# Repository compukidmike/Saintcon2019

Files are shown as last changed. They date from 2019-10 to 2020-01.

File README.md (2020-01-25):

# Saintcon 2019 Enigma Badge

## About the Badge
There is a writeup available at https://mkfactor.com/?p=100

There is also a video of my badge talk at Saintcon https://www.youtube.com/watch?v=MAhJ2W_oN14

## Completing the Badge Challenge
Since you probably don't have 26 badges and a Hut 6 "teleprinter" at your house, it will be difficult to complete the challenge. I have created a modified version of the badge firmware that will allow you to complete the challenge at home! You'll need to complete the steps for reprogramming your badge below. Once that's done, grab the Saintcon2019BadgeChallenge.pdf file from this repository. It has all the intercepted messages for you to decode. Be sure to decode them in order! Your badge should say "LEVELED UP" after successfully decoding a message. Good luck! If you get stuck, feel free to reach out on the SaintComms slack, or via twitter @compukidmike or even email compukidmike @ gmail.

## Reprogramming your badge
Note: This will completely erase the memory on your badge. Any progress in the challenge, as well as custom messages will be lost.

You will need the STM32CubeProgrammer software from https://www.st.com/en/development-tools/stm32cubeprog.html to reprogram your badge. It's cross-platform, though I've only tested it on Windows 10. Unfortunately ST requires you to create a login to download software :(

You'll also need the 2 hex files called Saintcon2019.hex and fpga.hex from this repository as well as a micro USB cable and one of the plugboard jumper wires from your badge.

Programming Steps:
1. Turn off the badge.
2. Connect the 2 TEST pins on your badge using the jumper (On the bottom-right side of your badge). If you haven't soldered that connector, you can put the jumper in from the back and hold it.
3. Connect the badge to your computer using a micro USB cable.
4. Turn on the badge. It will boot into DFU (Device Firmware Upgrade) mode.
5. From the STM32CubeProgrammer application, select USB from the drop-down menu at the top-right.
6. If you don't see anything next to "Serial number", click the little refresh button.
7. Click the green "Connect" button in the top-right corner. It should now say "Connected" above that button.
8. Click the Eraser button on the bottom-left corner (right above the question mark) and click OK to erase the badge memory. This is required for the new program to run correctly as there were many changes made to the way the internal EEPROM is organized.
9. Now click the "+" tab next to Device Memory and select "Open file". Choose one of the hex files you downloaded earlier. Now do the same for the other hex file.
10. With one of the hex file tabs selected, click the blue Download button. This will load the file onto your badge. Now do the same for the other hex file tab.
11. Remove the jumper and turn it off and back on. The first time you turn it on, it will go into a testing mode, where all the LEDs are turned on white. This is normal. Simply press each keyboard button until all the lampboard lights are off. It will say "TEST DONE". Turn it off and back on, and you are finished programming your badge. Enjoy!

## Editing Badge Code
The badge code can be found in the Firmware folder. It was written using the STM32CubeIDE. It's cross-platform and works reasonably well. You'll need an ST-Link V2 USB adapter to program and debug your badge. They can be had for ~$10 from Amazon or even less from Aliexpress if you're willing to wait for shipping.
The IDE can be downloaded from ST here: https://www.st.com/en/development-tools/stm32cubeide.html

The FPGA code was written using Icestudio https://icestudio.io/ It's a cross-platform IDE for Lattice ICE40 FPGAs

The FPGA code is in SaintconFPGA.ice

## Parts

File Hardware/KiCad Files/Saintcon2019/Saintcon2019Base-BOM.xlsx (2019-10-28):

Item # | Ref Des | Qty | Manufacturer | Mfg Part # | Description / Value | Package | Type | Your Instructions / Notes
1 | BT1 | 1 | JST Sales America Inc. | S2B-PH-SM4-TB(LF)(SN) | CONN HEADER SMD R/A 2POS 2MM | 2-SMD | SMD
2 | C1, C2, C3, C4, C6, C7, C14, C16, C18, C20, C22 | 11 |  |  | CAPACITOR 0.1uF 0603 | 0603 | SMD
3 | C5, C9, C10, C11, C12 | 5 |  |  | CAPACITOR 4.7uF 0603 | 0603 | SMD
4 | C8, C13, C15, C17, C19, C21 | 6 |  |  | CAPACITOR 1uF 0603 | 0603 | SMD
5 | D1, D2, D3, D4, D5, D6, D7, D8, D9, D10, D11, D12, D13, D14, D15, D16, D17, D18, D19, D20, D21, D22, D23, D24, D25, D26 | 26 | Varies | Varies | 5050 RGB LED | PLCC-6 (5050) | SMD | https://www.aliexpress.com/item/Led-Lamp-SMD-Led-Diode-RGB-LED-4500pcs-smd-5050-super-bright-leds-Free-Shipping-SMT/32690982692.html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
6 | D27 | 1 |  |  | LED RED 0603 | 0603 | SMD
7 | J1 | 1 | DNP | DNP | DNP
8 | J2 | 1 | Amphenol ICC (FCI) | 10132797-027100LF | CONN PLUG 20POS SMD GOLD | 20*0.5mm | SMD
9 | J3, J4 | 2 | DNP | DNP | DNP
10 | J5 | 1 | DNP | DNP | DNP
11 | J6 | 1 | Amphenol ICC (FCI) | 10118192-0002LF | CONN RCPT USB2.0 MICRO B SMD R/A | USB | SMD
12 | R1, R2, R3, R4 | 4 |  |  | RESISTOR 1k 0603 | 0603 | SMD
13 | R5, R13, R14, R15, R16, R17 | 6 |  |  | RESISTOR 10k 0603 | 0603 | SMD
14 | R6, R7, R10, R12 | 4 |  |  | RESISTOR 100k 0603 | 0603 | SMD
15 | R8, R9 | 2 |  |  | RESISTOR 2k 0603 | 0603 | SMD
16 | R11 | 1 |  |  | RESISTOR 20k 0603 | 0603 | SMD
17 | SW1, SW2, SW3, SW4, SW5, SW6, SW7, SW8, SW9, SW10, SW11, SW12, SW13, SW14, SW15, SW16, SW17, SW18, SW19, SW20, SW21, SW22, SW23, SW24, SW25, SW26 | 26 | Varies | Varies | TACH SWITCH SQUARE HEAD 6x6MM | 4-SMD | SMD | https://www.aliexpress.com/item/32726480469.html?transAbTest=ae803_5
18 | SW27 | 1 | C&K | JS102011SAQN | SWITCH SLIDE SPDT 300MA 6V | 3-SMD | SMD
19 | U1 | 1 | STMicroelectronics | STM32L433VCT6 | IC MCU 32BIT 256KB FLASH 100LQFP | 100LQFP | SMD
20 | U2 | 1 | Microchip Technology | MCP73832T-2ACI/OT | IC LI-ION/LI-POLY CTRLR SOT23-5 | SOT-23-5 | SMD
21 | U3 | 1 | Diodes Incorporated | AP2112K-3.3TRG1 | IC REG LINEAR 3.3V 600MA SOT25 | SOT-23-5 | SMD
22 | U4 | 1 | ISSI, Integrated Silicon Solution Inc | IS31FL3736-QFLS4-TR | IC LED DRVR LINEAR 45MA 40QFN | 40-QFN | SMD
23 | X1, X2 | 2 | JST Sales America Inc. | 02R-LEBSS-TB(LF)(SN) | CONN SSL RCPT 2POS 4MM SOLDER | 2-SMD | SMD
24 | X3, X4 | 2 | JST Sales America Inc. | 02P-LEBSS-TF(LF)(SN) | CONN SSL PLUG 2POS 4MM SOLDER | 2-SMD | SMD
25 | Y1 | 1 | ECS Inc. | ECS-2520MV-120-BN-TR | XTAL OSC XO 12.0000MHZ CMOS SMD | 4-SMD | SMD

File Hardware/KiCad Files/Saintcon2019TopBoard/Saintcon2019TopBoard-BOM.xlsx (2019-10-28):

Item # | Ref Des | Qty | Manufacturer | Mfg Part # | Description / Value | Package | Type | Your Instructions / Notes
1 | C1, C2, C3, C4, C5, C6, C7, C8, C10, C15, C16, C17, C18, C19, C20, C21, C22, C23, C24, C25, C26, C27, C28, C29, C30, C31, C32 | 27 |  |  | Capacitor 0603 100nF 25V | 0603 | SMD
2 | C9 | 1 |  |  | Capacitor 0603 10uF 25V | 0603 | SMD
3 | C11, C12, C13, C14 | 4 |  |  | Capacitor 0603 1uF 25V | 0603 | SMD
4 | D1, D2, D3, D4, D5, D6, D7, D8, D9, D10, D11, D12, D13, D14, D15, D16, D17, D18, D19, D20, D21, D22, D23, D24, D25, D26, D27, D28, D29, D30, D31, D32, D33, D34, D35, D36, D37, D38, D39, D40, D41, D42, D43, D44, D45, D46, D47, D48, D49, D50, D51, D52, D53, D54, D55, D56, D57, D58, D59, D60, D61, D62, D63, D64, D65, D66, D67, D68, D69, D70, D71, D72, D73, D74, D75, D76, D77, D78, D79, D80, D81, D82, D83, D84, D85, D86, D87, D88, D89, D90, D91, D92, D93, D94, D95, D96, D97, D98, D99, D100, D101, D102, D103, D104, D105, D106, D107, D108, D109, D110, D111, D112, D113, D114, D115, D116, D117, D118, D119, D120, D121, D122, D123, D124, D125, D126, D127, D128, D129, D130, D131, D132, D133, D134, D135, D136, D137, D138, D139, D140, D141, D142, D143, D144, D145, D146, D147, D148, D149, D150, D151, D152, D153, D154, D155, D156, D157, D158, D159, D160, D161, D162, D163, D164, D165, D166, D167, D168, D169, D170, D171, D172, D173, D174, D175, D176, D177, D178, D179, D180, D181, D182, D183, D184, D185, D186, D187, D188, D189, D190, D191, D192, D193, D194, D195, D196, D197, D198, D199, D200, D201, D202, D203, D204, D205, D206, D207, D208, D209, D210, D211, D212, D213, D214, D215, D216, D217, D218, D219, D220, D221, D222, D223, D224, D225, D226, D227, D228, D229, D230, D231, D232, D233, D234, D235, D236, D237, D238, D239, D240, D241, D242, D243, D244, D245, D246, D247, D248, D249, D250, D251, D252, D253, D254, D255, D256, D257, D258, D259, D260, D261, D262, D263, D264, D265, D266, D267, D268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 | 1024 | Lite-On | LSTN-B28JEGBB | RGB LED 0404(1010) | 1010 | SMD | https://www.aliexpress.com/item/32374160642.html?transAbTest=ae803_5
5 | D1025 | 1 | STMicroelectronics | BAS70JFILM | DIODE SCHOTTKY 70V 70MA SOD323 | SOD323 | SMD
6 | J1 | 1 | Amphenol ICC (FCI) | 10132798-022100LF | Board to Board & Mezzanine Connectors 2.7mm Height,Dbl Rw 20P,Recept,Connector | 20*0.5mm | SMD
7 | R1, R2, R3 | 3 |  |  | Resistor 0603 10k | 0603 | SMD
8 | R4 | 1 |  |  | Resistor 0603 100 | 0603 | SMD
9 | R9, R10, R11, R12, R13, R14, R15, R16, R17, R18, R19, R20, R21, R22, R23, R24, R25, R26, R27, R28, R29, R30, R31, R32, R33, R34, R35, R36 | 28 |  |  | Resistor 0603 1k | 0603 | SMD
10 | U1 | 1 | Lattice | iCE40HX1K-TQ144 | FPGA - Field Programmable Gate Array iCE40HX 1280 LUTs 1.2V Ultra Low-Power | TQFP144 | SMD
11 | U2 | 1 | Diodes Incorporated | AP2112K-3.3TRG1 | IC REG LINEAR 3.3V 600MA SOT25 | SOT-23-5 | SMD
12 | U3 | 1 | Microchip | MIC5504-1.2YM5-TR | IC REG LINEAR 1.2V 300MA SOT23-5 | SOT-23-5 | SMD
13 | U5, U6, U7, U8, U9, U10, U11, U12, U13, U14, U15, U16 | 12 | Macroblock | MBI5124GP-A | IC LED DRVR 24QSOP | 24-QSOP | SMD
14 | U17, U18, U19, U20, U21, U22, U23, U24 | 8 | Micro Commercial Co | SIL2301-TP | P-CHANNEL,MOSFETS,SOT23-6L PACKA | SOT-23-6 | SMD

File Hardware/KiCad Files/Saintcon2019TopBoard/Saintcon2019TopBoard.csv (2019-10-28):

Source: | C:\Users\compukidmike\Dropbox\kicad\Saintcon2019TopBoard\Saintcon2019TopBoard.sch
Date: | 6/2/2019 3:04:15 PM
Tool: | Eeschema (5.1.2)-1
Generator: | C:\Program Files\KiCad\bin\scripting\plugins/bom_csv_grouped_by_value.py
Component Count: | 1119
Individual Components:
Item | Qty | Reference(s) | Value | LibPart | Footprint | Datasheet | Field4 | Field5 | Field6 | Field7 | Field8
 |  | C1 | 0.1uF | Device:C_Small | Capacitors_SMD:C_0603 | ~
 |  | C2 | 0.1uF | Device:C_Small | Capacitors_SMD:C_0603 | ~
 |  | C3 | 0.1uF | Device:C_Small | Capacitors_SMD:C_0603 | ~
 |  | C4 | 0.1uF | Device:C_Small | Capacitors_SMD:C_0603 | ~
 |  | C5 | 0.1uF | Device:C_Small | Capacitors_SMD:C_0603 | ~
 |  | C6 | 0.1uF | Device:C_Small | Capacitors_SMD:C_0603 | ~
 |  | C7 | 0.1uF | Device:C_Small | Capacitors_SMD:C_0603 | ~
 |  | C8 | 0.1uF | Device:C_Small | Capacitors_SMD:C_0603 | ~
 |  | C9 | 10uF | Device:C_Small | Capacitors_SMD:C_0603 | ~
 |  | C10 | 0.1uF | Device:C_Small | Capacitors_SMD:C_0603 | ~
 |  | C11 | 1uF | Device:C_Small | Capacitors_SMD:C_0603 | ~
 |  | C12 | 1uF | Device:C_Small | Capacitors_SMD:C_0603 | ~
 |  | C13 | 1uF | Device:C_Small | Capacitors_SMD:C_0603 | ~
 |  | C14 | 1uF | Device:C_Small | Capacitors_SMD:C_0603 | ~
 |  | C15 | 0.1uF | Device:C_Small | Capacitors_SMD:C_0603 | ~
 |  | C16 | 0.1uF | Device:C_Small | Capacitors_SMD:C_0603 | ~
 |  | C17 | 0.1uF | Device:C_Small | Capacitors_SMD:C_0603 | ~
 |  | C18 | 0.1uF | Device:C_Small | Capacitors_SMD:C_0603 | ~
 |  | C19 | 0.1uF | Device:C_Small | Capacitors_SMD:C_0603 | ~
 |  | C20 | 0.1uF | Device:C_Small | Capacitors_SMD:C_0603 | ~
 |  | C21 | 0.1uF | Device:C_Small | Capacitors_SMD:C_0603 | ~
 |  | C22 | 0.1uF | Device:C_Small | Capacitors_SMD:C_0603 | ~
 |  | C23 | 0.1uF | Device:C_Small | Capacitors_SMD:C_0603 | ~
 |  | C24 | 0.1uF | Device:C_Small | Capacitors_SMD:C_0603 | ~
 |  | C25 | 0.1uF | Device:C_Small | Capacitors_SMD:C_0603 | ~
 |  | C26 | 0.1uF | Device:C_Small | Capacitors_SMD:C_0603 | ~
 |  | C27 | 0.1uF | Device:C_Small | Capacitors_SMD:C_0603 | ~
 |  | C28 | 0.1uF | Device:C_Small | Capacitors_SMD:C_0603 | ~
 |  | C29 | 0.1uF | Device:C_Small | Capacitors_SMD:C_0603 | ~
 |  | C30 | 0.1uF | Device:C_Small | Capacitors_SMD:C_0603 | ~
 |  | C31 | 0.1uF | Device:C_Small | Capacitors_SMD:C_0603 | ~
 |  | C32 | 0.1uF | Device:C_Small | Capacitors_SMD:C_0603 | ~
 |  | D1 | LED_ARGB | Device:LED_ARGB | RGB_LED_0402_1mm:LTSN-B28JEGBB | ~
 |  | D2 | LED_ARGB | Device:LED_ARGB | RGB_LED_0402_1mm:LTSN-B28JEGBB | ~
 |  | D3 | LED_ARGB | Device:LED_ARGB | RGB_LED_0402_1mm:LTSN-B28JEGBB | ~
 |  | D4 | LED_ARGB | Device:LED_ARGB | RGB_LED_0402_1mm:LTSN-B28JEGBB | ~
 |  | D5 | LED_ARGB | Device:LED_ARGB | RGB_LED_0402_1mm:LTSN-B28JEGBB | ~
 |  | D6 | LED_ARGB | Device:LED_ARGB | RGB_LED_0402_1mm:LTSN-B28JEGBB | ~
 |  | D7 | LED_ARGB | Device:LED_ARGB | RGB_LED_0402_1mm:LTSN-B28JEGBB | ~
 |  | D8 | LED_ARGB | Device:LED_ARGB | RGB_LED_0402_1mm:LTSN-B28JEGBB | ~
 |  | D9 | LED_ARGB | Device:LED_ARGB | RGB_LED_0402_1mm:LTSN-B28JEGBB | ~
 |  | D10 | LED_ARGB | Device:LED_ARGB | RGB_LED_0402_1mm:LTSN-B28JEGBB | ~
 |  | D11 | LED_ARGB | Device:LED_ARGB | RGB_LED_0402_1mm:LTSN-B28JEGBB | ~
 |  | D12 | LED_ARGB | Device:LED_ARGB | RGB_LED_0402_1mm:LTSN-B28JEGBB | ~
 |  | D13 | LED_ARGB | Device:LED_ARGB | RGB_LED_0402_1mm:LTSN-B28JEGBB | ~
 |  | D14 | LED_ARGB | Device:LED_ARGB | RGB_LED_0402_1mm:LTSN-B28JEGBB | ~
 |  | D15 | LED_ARGB | Device:LED_ARGB | RGB_LED_0402_1mm:LTSN-B28JEGBB | ~
 |  | D16 | LED_ARGB | Device:LED_ARGB | RGB_LED_0402_1mm:LTSN-B28JEGBB | ~
 |  | D17 | LED_ARGB | Device:LED_ARGB | RGB_LED_0402_1mm:LTSN-B28JEGBB | ~
 |  | D18 | LED_ARGB | Device:LED_ARGB | RGB_LED_0402_1mm:LTSN-B28JEGBB | ~
 |  | D19 | LED_ARGB | Device:LED_ARGB | RGB_LED_0402_1mm:LTSN-B28JEGBB | ~
 |  | D20 | LED_ARGB | Device:LED_ARGB | RGB_LED_0402_1mm:LTSN-B28JEGBB | ~
 |  | D21 | LED_ARGB | Device:LED_ARGB | RGB_LED_0402_1mm:LTSN-B28JEGBB | ~
 |  | D22 | LED_ARGB | Device:LED_ARGB | RGB_LED_0402_1mm:LTSN-B28JEGBB | ~
 |  | D23 | LED_ARGB | Device:LED_ARGB | RGB_LED_0402_1mm:LTSN-B28JEGBB | ~
 |  | D24 | LED_ARGB | Device:LED_ARGB | RGB_LED_0402_1mm:LTSN-B28JEGBB | ~
 |  | D25 | LED_ARGB | Device:LED_ARGB | RGB_LED_0402_1mm:LTSN-B28JEGBB | ~
 |  | D26 | LED_ARGB | Device:LED_ARGB | RGB_LED_0402_1mm:LTSN-B28JEGBB | ~
 |  | D27 | LED_ARGB | Device:LED_ARGB | RGB_LED_0402_1mm:LTSN-B28JEGBB | ~
 |  | D28 | LED_ARGB | Device:LED_ARGB | RGB_LED_0402_1mm:LTSN-B28JEGBB | ~
 |  | D29 | LED_ARGB | Device:LED_ARGB | RGB_LED_0402_1mm:LTSN-B28JEGBB | ~
 |  | D30 | LED_ARGB | Device:LED_ARGB | RGB_LED_0402_1mm:LTSN-B28JEGBB | ~
 |  | D31 | LED_ARGB | Device:LED_ARGB | RGB_LED_0402_1mm:LTSN-B28JEGBB | ~
 |  | D32 | LED_ARGB | Device:LED_ARGB | RGB_LED_0402_1mm:LTSN-B28JEGBB | ~
 |  | D33 | LED_ARGB | Device:LED_ARGB | RGB_LED_0402_1mm:LTSN-B28JEGBB | ~
 |  | D34 | LED_ARGB | Device:LED_ARGB | RGB_LED_0402_1mm:LTSN-B28JEGBB | ~
 |  | D35 | LED_ARGB | Device:LED_ARGB | RGB_LED_0402_1mm:LTSN-B28JEGBB | ~
 |  | D36 | LED_ARGB | Device:LED_ARGB | RGB_LED_0402_1mm:LTSN-B28JEGBB | ~
 |  | D37 | LED_ARGB | Device:LED_ARGB | RGB_LED_0402_1mm:LTSN-B28JEGBB | ~
 |  | D38 | LED_ARGB | Device:LED_ARGB | RGB_LED_0402_1mm:LTSN-B28JEGBB | ~
 |  | D39 | LED_ARGB | Device:LED_ARGB | RGB_LED_0402_1mm:LTSN-B28JEGBB | ~
 |  | D40 | LED_ARGB | Device:LED_ARGB | RGB_LED_0402_1mm:LTSN-B28JEGBB | ~
 |  | D41 | LED_ARGB | Device:LED_ARGB | RGB_LED_0402_1mm:LTSN-B28JEGBB | ~
 |  | D42 | LED_ARGB | Device:LED_ARGB | RGB_LED_0402_1mm:LTSN-B28JEGBB | ~
 |  | D43 | LED_ARGB | Device:LED_ARGB | RGB_LED_0402_1mm:LTSN-B28JEGBB | ~
 |  | D44 | LED_ARGB | Device:LED_ARGB | RGB_LED_0402_1mm:LTSN-B28JEGBB | ~
 |  | D45 | LED_ARGB | Device:LED_ARGB | RGB_LED_0402_1mm:LTSN-B28JEGBB | ~
 |  | D46 | LED_ARGB | Device:LED_ARGB | RGB_LED_0402_1mm:LTSN-B28JEGBB | ~
 |  | D47 | LED_ARGB | Device:LED_ARGB | RGB_LED_0402_1mm:LTSN-B28JEGBB | ~
 |  | D48 | LED_ARGB | Device:LED_ARGB | RGB_LED_0402_1mm:LTSN-B28JEGBB | ~
 |  | D49 | LED_ARGB | Device:LED_ARGB | RGB_LED_0402_1mm:LTSN-B28JEGBB | ~
 |  | D50 | LED_ARGB | Device:LED_ARGB | RGB_LED_0402_1mm:LTSN-B28JEGBB | ~
 |  | D51 | LED_ARGB | Device:LED_ARGB | RGB_LED_0402_1mm:LTSN-B28JEGBB | ~
 |  | D52 | LED_ARGB | Device:LED_ARGB | RGB_LED_0402_1mm:LTSN-B28JEGBB | ~
 |  | D53 | LED_ARGB | Device:LED_ARGB | RGB_LED_0402_1mm:LTSN-B28JEGBB | ~
 |  | D54 | LED_ARGB | Device:LED_ARGB | RGB_LED_0402_1mm:LTSN-B28JEGBB | ~
 |  | D55 | LED_ARGB | Device:LED_ARGB | RGB_LED_0402_1mm:LTSN-B28JEGBB | ~
 |  | D56 | LED_ARGB | Device:LED_ARGB | RGB_LED_0402_1mm:LTSN-B28JEGBB | ~
 |  | D57 | LED_ARGB | Device:LED_ARGB | RGB_LED_0402_1mm:LTSN-B28JEGBB | ~
 |  | D58 | LED_ARGB | Device:LED_ARGB | RGB_LED_0402_1mm:LTSN-B28JEGBB | ~
 |  | D59 | LED_ARGB | Device:LED_ARGB | RGB_LED_0402_1mm:LTSN-B28JEGBB | ~
 |  | D60 | LED_ARGB | Device:LED_ARGB | RGB_LED_0402_1mm:LTSN-B28JEGBB | ~
 |  | D61 | LED_ARGB | Device:LED_ARGB | RGB_LED_0402_1mm:LTSN-B28JEGBB | ~
 |  | D62 | LED_ARGB | Device:LED_ARGB | RGB_LED_0402_1mm:LTSN-B28JEGBB | ~
 |  | D63 | LED_ARGB | Device:LED_ARGB | RGB_LED_0402_1mm:LTSN-B28JEGBB | ~
 |  | D64 | LED_ARGB | Device:LED_ARGB | RGB_LED_0402_1mm:LTSN-B28JEGBB | ~
 |  | D65 | LED_ARGB | Device:LED_ARGB | RGB_LED_0402_1mm:LTSN-B28JEGBB | ~
 |  | D66 | LED_ARGB | Device:LED_ARGB | RGB_LED_0402_1mm:LTSN-B28JEGBB | ~
 |  | D67 | LED_ARGB | Device:LED_ARGB | RGB_LED_0402_1mm:LTSN-B28JEGBB | ~
 |  | D68 | LED_ARGB | Device:LED_ARGB | RGB_LED_0402_1mm:LTSN-B28JEGBB | ~
 |  | D69 | LED_ARGB | Device:LED_ARGB | RGB_LED_0402_1mm:LTSN-B28JEGBB | ~
 |  | D70 | LED_ARGB | Device:LED_ARGB | RGB_LED_0402_1mm:LTSN-B28JEGBB | ~
 |  | D71 | LED_ARGB | Device:LED_ARGB | RGB_LED_0402_1mm:LTSN-B28JEGBB | ~
 |  | D72 | LED_ARGB | Device:LED_ARGB | RGB_LED_0402_1mm:LTSN-B28JEGBB | ~
 |  | D73 | LED_ARGB | Device:LED_ARGB | RGB_LED_0402_1mm:LTSN-B28JEGBB | ~
 |  | D74 | LED_ARGB | Device:LED_ARGB | RGB_LED_0402_1mm:LTSN-B28JEGBB | ~
 |  | D75 | LED_ARGB | Device:LED_ARGB | RGB_LED_0402_1mm:LTSN-B28JEGBB | ~
 |  | D76 | LED_ARGB | Device:LED_ARGB | RGB_LED_0402_1mm:LTSN-B28JEGBB | ~
 |  | D77 | LED_ARGB | Device:LED_ARGB | RGB_LED_0402_1mm:LTSN-B28JEGBB | ~
 |  | D78 | LED_ARGB | Device:LED_ARGB | RGB_LED_0402_1mm:LTSN-B28JEGBB | ~
 |  | D79 | LED_ARGB | Device:LED_ARGB | RGB_LED_0402_1mm:LTSN-B28JEGBB | ~
 |  | D80 | LED_ARGB | Device:LED_ARGB | RGB_LED_0402_1mm:LTSN-B28JEGBB | ~
 |  | D81 | LED_ARGB | Device:LED_ARGB | RGB_LED_0402_1mm:LTSN-B28JEGBB | ~
 |  | D82 | LED_ARGB | Device:LED_ARGB | RGB_LED_0402_1mm:LTSN-B28JEGBB | ~
 |  | D83 | LED_ARGB | Device:LED_ARGB | RGB_LED_0402_1mm:LTSN-B28JEGBB | ~
 |  | D84 | LED_ARGB | Device:LED_ARGB | RGB_LED_0402_1mm:LTSN-B28JEGBB | ~
 |  | D85 | LED_ARGB | Device:LED_ARGB | RGB_LED_0402_1mm:LTSN-B28JEGBB | ~
 |  | D86 | LED_ARGB | Device:LED_ARGB | RGB_LED_0402_1mm:LTSN-B28JEGBB | ~
 |  | D87 | LED_ARGB | Device:LED_ARGB | RGB_LED_0402_1mm:LTSN-B28JEGBB | ~
 |  | D88 | LED_ARGB | Device:LED_ARGB | RGB_LED_0402_1mm:LTSN-B28JEGBB | ~
 |  | D89 | LED_ARGB | Device:LED_ARGB | RGB_LED_0402_1mm:LTSN-B28JEGBB | ~
 |  | D90 | LED_ARGB | Device:LED_ARGB | RGB_LED_0402_1mm:LTSN-B28JEGBB | ~
 |  | D91 | LED_ARGB | Device:LED_ARGB | RGB_LED_0402_1mm:LTSN-B28JEGBB | ~
 |  | D92 | LED_ARGB | Device:LED_ARGB | RGB_LED_0402_1mm:LTSN-B28JEGBB | ~
 |  | D93 | LED_ARGB | Device:LED_ARGB | RGB_LED_0402_1mm:LTSN-B28JEGBB | ~
 |  | D94 | LED_ARGB | Device:LED_ARGB | RGB_LED_0402_1mm:LTSN-B28JEGBB | ~
 |  | D95 | LED_ARGB | Device:LED_ARGB | RGB_LED_0402_1mm:LTSN-B28JEGBB | ~
 |  | D96 | LED_ARGB | Device:LED_ARGB | RGB_LED_0402_1mm:LTSN-B28JEGBB | ~
 |  | D97 | LED_ARGB | Device:LED_ARGB | RGB_LED_0402_1mm:LTSN-B28JEGBB | ~
 |  | D98 | LED_ARGB | Device:LED_ARGB | RGB_LED_0402_1mm:LTSN-B28JEGBB | ~
 |  | D99 | LED_ARGB | Device:LED_ARGB | RGB_LED_0402_1mm:LTSN-B28JEGBB | ~
 |  | D100 | LED_ARGB | Device:LED_ARGB | RGB_LED_0402_1mm:LTSN-B28JEGBB | ~
 |  | D101 | LED_ARGB | Device:LED_ARGB | RGB_LED_0402_1mm:LTSN-B28JEGBB | ~
 |  | D102 | LED_ARGB | Device:LED_ARGB | RGB_LED_0402_1mm:LTSN-B28JEGBB | ~
 |  | D103 | LED_ARGB | Device:LED_ARGB | RGB_LED_0402_1mm:LTSN-B28JEGBB | ~
 |  | D104 | LED_ARGB | Device:LED_ARGB | RGB_LED_0402_1mm:LTSN-B28JEGBB | ~
 |  | D105 | LED_ARGB | Device:LED_ARGB | RGB_LED_0402_1mm:LTSN-B28JEGBB | ~
 |  | D106 | LED_ARGB | Device:LED_ARGB | RGB_LED_0402_1mm:LTSN-B28JEGBB | ~
 |  | D107 | LED_ARGB | Device:LED_ARGB | RGB_LED_0402_1mm:LTSN-B28JEGBB | ~
 |  | D108 | LED_ARGB | Device:LED_ARGB | RGB_LED_0402_1mm:LTSN-B28JEGBB | ~
 |  | D109 | LED_ARGB | Device:LED_ARGB | RGB_LED_0402_1mm:LTSN-B28JEGBB | ~
 |  | D110 | LED_ARGB | Device:LED_ARGB | RGB_LED_0402_1mm:LTSN-B28JEGBB | ~
 |  | D111 | LED_ARGB | Device:LED_ARGB | RGB_LED_0402_1mm:LTSN-B28JEGBB | ~
 |  | D112 | LED_ARGB | Device:LED_ARGB | RGB_LED_0402_1mm:LTSN-B28JEGBB | ~
 |  | D113 | LED_ARGB | Device:LED_ARGB | RGB_LED_0402_1mm:LTSN-B28JEGBB | ~
 |  | D114 | LED_ARGB | Device:LED_ARGB | RGB_LED_0402_1mm:LTSN-B28JEGBB | ~
 |  | D115 | LED_ARGB | Device:LED_ARGB | RGB_LED_0402_1mm:LTSN-B28JEGBB | ~
 |  | D116 | LED_ARGB | Device:LED_ARGB | RGB_LED_0402_1mm:LTSN-B28JEGBB | ~
 |  | D117 | LED_ARGB | Device:LED_ARGB | RGB_LED_0402_1mm:LTSN-B28JEGBB | ~
 |  | D118 | LED_ARGB | Device:LED_ARGB | RGB_LED_0402_1mm:LTSN-B28JEGBB | ~
 |  | D119 | LED_ARGB | Device:LED_ARGB | RGB_LED_0402_1mm:LTSN-B28JEGBB | ~
 |  | D120 | LED_ARGB | Device:LED_ARGB | RGB_LED_0402_1mm:LTSN-B28JEGBB | ~
 |  | D121 | LED_ARGB | Device:LED_ARGB | RGB_LED_0402_1mm:LTSN-B28JEGBB | ~
 |  | D122 | LED_ARGB | Device:LED_ARGB | RGB_LED_0402_1mm:LTSN-B28JEGBB | ~
 |  | D123 | LED_ARGB | Device:LED_ARGB | RGB_LED_0402_1mm:LTSN-B28JEGBB | ~
 |  | D124 | LED_ARGB | Device:LED_ARGB | RGB_LED_0402_1mm:LTSN-B28JEGBB | ~
 |  | D125 | LED_ARGB | Device:LED_ARGB | RGB_LED_0402_1mm:LTSN-B28JEGBB | ~
 |  | D126 | LED_ARGB | Device:LED_ARGB | RGB_LED_0402_1mm:LTSN-B28JEGBB | ~
 |  | D127 | LED_ARGB | Device:LED_ARGB | RGB_LED_0402_1mm:LTSN-B28JEGBB | ~
 |  | D128 | LED_ARGB | Device:LED_ARGB | RGB_LED_0402_1mm:LTSN-B28JEGBB | ~
 |  | D129 | LED_ARGB | Device:LED_ARGB | RGB_LED_0402_1mm:LTSN-B28JEGBB | ~
 |  | D130 | LED_ARGB | Device:LED_ARGB | RGB_LED_0402_1mm:LTSN-B28JEGBB | ~
 |  | D131 | LED_ARGB | Device:LED_ARGB | RGB_LED_0402_1mm:LTSN-B28JEGBB | ~
 |  | D132 | LED_ARGB | Device:LED_ARGB | RGB_LED_0402_1mm:LTSN-B28JEGBB | ~
 |  | D133 | LED_ARGB | Device:LED_ARGB | RGB_LED_0402_1mm:LTSN-B28JEGBB | ~
 |  | D134 | LED_ARGB | Device:LED_ARGB | RGB_LED_0402_1mm:LTSN-B28JEGBB | ~
 |  | D135 | LED_ARGB | Device:LED_ARGB | RGB_LED_0402_1mm:LTSN-B28JEGBB | ~
 |  | D136 | LED_ARGB | Device:LED_ARGB | RGB_LED_0402_1mm:LTSN-B28JEGBB | ~
 |  | D137 | LED_ARGB | Device:LED_ARGB | RGB_LED_0402_1mm:LTSN-B28JEGBB | ~
 |  | D138 | LED_ARGB | Device:LED_ARGB | RGB_LED_0402_1mm:LTSN-B28JEGBB | ~
 |  | D139 | LED_ARGB | Device:LED_ARGB | RGB_LED_0402_1mm:LTSN-B28JEGBB | ~
 |  | D140 | LED_ARGB | Device:LED_ARGB | RGB_LED_0402_1mm:LTSN-B28JEGBB | ~
 |  | D141 | LED_ARGB | Device:LED_ARGB | RGB_LED_0402_1mm:LTSN-B28JEGBB | ~
 |  | D142 | LED_ARGB | Device:LED_ARGB | RGB_LED_0402_1mm:LTSN-B28JEGBB | ~
 |  | D143 | LED_ARGB | Device:LED_ARGB | RGB_LED_0402_1mm:LTSN-B28JEGBB | ~
 |  | D144 | LED_ARGB | Device:LED_ARGB | RGB_LED_0402_1mm:LTSN-B28JEGBB | ~
 |  | D145 | LED_ARGB | Device:LED_ARGB | RGB_LED_0402_1mm:LTSN-B28JEGBB | ~
 |  | D146 | LED_ARGB | Device:LED_ARGB | RGB_LED_0402_1mm:LTSN-B28JEGBB | ~
 |  | D147 | LED_ARGB | Device:LED_ARGB | RGB_LED_0402_1mm:LTSN-B28JEGBB | ~
 |  | D148 | LED_ARGB | Device:LED_ARGB | RGB_LED_0402_1mm:LTSN-B28JEGBB | ~
 |  | D149 | LED_ARGB | Device:LED_ARGB | RGB_LED_0402_1mm:LTSN-B28JEGBB | ~
 |  | D150 | LED_ARGB | Device:LED_ARGB | RGB_LED_0402_1mm:LTSN-B28JEGBB | ~
 |  | D151 | LED_ARGB | Device:LED_ARGB | RGB_LED_0402_1mm:LTSN-B28JEGBB | ~
 |  | D152 | LED_ARGB | Device:LED_ARGB | RGB_LED_0402_1mm:LTSN-B28JEGBB | ~
 |  | D153 | LED_ARGB | Device:LED_ARGB | RGB_LED_0402_1mm:LTSN-B28JEGBB | ~
 |  | D154 | LED_ARGB | Device:LED_ARGB | RGB_LED_0402_1mm:LTSN-B28JEGBB | ~
 |  | D155 | LED_ARGB | Device:LED_ARGB | RGB_LED_0402_1mm:LTSN-B28JEGBB | ~
 |  | D156 | LED_ARGB | Device:LED_ARGB | RGB_LED_0402_1mm:LTSN-B28JEGBB | ~
 |  | D157 | LED_ARGB | Device:LED_ARGB | RGB_LED_0402_1mm:LTSN-B28JEGBB | ~
 |  | D158 | LED_ARGB | Device:LED_ARGB | RGB_LED_0402_1mm:LTSN-B28JEGBB | ~
 |  | D159 | LED_ARGB | Device:LED_ARGB | RGB_LED_0402_1mm:LTSN-B28JEGBB | ~
 |  | D160 | LED_ARGB | Device:LED_ARGB | RGB_LED_0402_1mm:LTSN-B28JEGBB | ~
 |  | D161 | LED_ARGB | Device:LED_ARGB | RGB_LED_0402_1mm:LTSN-B28JEGBB | ~
 |  | D162 | LED_ARGB | Device:LED_ARGB | RGB_LED_0402_1mm:LTSN-B28JEGBB | ~
 |  | D163 | LED_ARGB | Device:LED_ARGB | RGB_LED_0402_1mm:LTSN-B28JEGBB | ~
 |  | D164 | LED_ARGB | Device:LED_ARGB | RGB_LED_0402_1mm:LTSN-B28JEGBB | ~
 |  | D165 | LED_ARGB | Device:LED_ARGB | RGB_LED_0402_1mm:LTSN-B28JEGBB | ~
 |  | D166 | LED_ARGB | Device:LED_ARGB | RGB_LED_0402_1mm:LTSN-B28JEGBB | ~
 |  | D167 | LED_ARGB | Device:LED_ARGB | RGB_LED_0402_1mm:LTSN-B28JEGBB | ~
 |  | D168 | LED_ARGB | Device:LED_ARGB | RGB_LED_0402_1mm:LTSN-B28JEGBB | ~
 |  | D169 | LED_ARGB | Device:LED_ARGB | RGB_LED_0402_1mm:LTSN-B28JEGBB | ~
 |  | D170 | LED_ARGB | Device:LED_ARGB | RGB_LED_0402_1mm:LTSN-B28JEGBB | ~
 |  | D171 | LED_ARGB | Device:LED_ARGB | RGB_LED_0402_1mm:LTSN-B28JEGBB | ~
 |  | D172 | LED_ARGB | Device:LED_ARGB | RGB_LED_0402_1mm:LTSN-B28JEGBB | ~
 |  | D173 | LED_ARGB | Device:LED_ARGB | RGB_LED_0402_1mm:LTSN-B28JEGBB | ~
 |  | D174 | LED_ARGB | Device:LED_ARGB | RGB_LED_0402_1mm:LTSN-B28JEGBB | ~
 |  | D175 | LED_ARGB | Device:LED_ARGB | RGB_LED_0402_1mm:LTSN-B28JEGBB | ~
 |  | D176 | LED_ARGB | Device:LED_ARGB | RGB_LED_0402_1mm:LTSN-B28JEGBB | ~
 |  | D177 | LED_ARGB | Device:LED_ARGB | RGB_LED_0402_1mm:LTSN-B28JEGBB | ~
 |  | D178 | LED_ARGB | Device:LED_ARGB | RGB_LED_0402_1mm:LTSN-B28JEGBB | ~
 |  | D179 | LED_ARGB | Device:LED_ARGB | RGB_LED_0402_1mm:LTSN-B28JEGBB | ~
 |  | D180 | LED_ARGB | Device:LED_ARGB | RGB_LED_0402_1mm:LTSN-B28JEGBB | ~
 |  | D181 | LED_ARGB | Device:LED_ARGB | RGB_LED_0402_1mm:LTSN-B28JEGBB | ~
 |  | D182 | LED_ARGB | Device:LED_ARGB | RGB_LED_0402_1mm:LTSN-B28JEGBB | ~
 |  | D183 | LED_ARGB | Device:LED_ARGB | RGB_LED_0402_1mm:LTSN-B28JEGBB | ~
 |  | D184 | LED_ARGB | Device:LED_ARGB | RGB_LED_0402_1mm:LTSN-B28JEGBB | ~
 |  | D185 | LED_ARGB | Device:LED_ARGB | RGB_LED_0402_1mm:LTSN-B28JEGBB | ~
 |  | D186 | LED_ARGB | Device:LED_ARGB | RGB_LED_0402_1mm:LTSN-B28JEGBB | ~
 |  | D187 | LED_ARGB | Device:LED_ARGB | RGB_LED_0402_1mm:LTSN-B28JEGBB | ~
 |  | D188 | LED_ARGB | Device:LED_ARGB | RGB_LED_0402_1mm:LTSN-B28JEGBB | ~
 |  | D189 | LED_ARGB | Device:LED_ARGB | RGB_LED_0402_1mm:LTSN-B28JEGBB | ~
 |  | D190 | LED_ARGB | Device:LED_ARGB | RGB_LED_0402_1mm:LTSN-B28JEGBB | ~
 |  | D191 | LED_ARGB | Device:LED_ARGB | RGB_LED_0402_1mm:LTSN-B28JEGBB | ~
 |  | D192 | LED_ARGB | Device:LED_ARGB | RGB_LED_0402_1mm:LTSN-B28JEGBB | ~
 |  | D193 | LED_ARGB | Device:LED_ARGB | RGB_LED_0402_1mm:LTSN-B28JEGBB | ~
 |  | D194 | LED_ARGB | Device:LED_ARGB | RGB_LED_0402_1mm:LTSN-B28JEGBB | ~
 |  | D195 | LED_ARGB | Device:LED_ARGB | RGB_LED_0402_1mm:LTSN-B28JEGBB | ~
 |  | D196 | LED_ARGB | Device:LED_ARGB | RGB_LED_0402_1mm:LTSN-B28JEGBB | ~
 |  | D197 | LED_ARGB | Device:LED_ARGB | RGB_LED_0402_1mm:LTSN-B28JEGBB | ~
 |  | D198 | LED_ARGB | Device:LED_ARGB | RGB_LED_0402_1mm:LTSN-B28JEGBB | ~
 |  | D199 | LED_ARGB | Device:LED_ARGB | RGB_LED_0402_1mm:LTSN-B28JEGBB | ~
 |  | D200 | LED_ARGB | Device:LED_ARGB | RGB_LED_0402_1mm:LTSN-B28JEGBB | ~
 |  | D201 | LED_ARGB | Device:LED_ARGB | RGB_LED_0402_1mm:LTSN-B28JEGBB | ~
 |  | D202 | LED_ARGB | Device:LED_ARGB | RGB_LED_0402_1mm:LTSN-B28JEGBB | ~
 |  | D203 | LED_ARGB | Device:LED_ARGB | RGB_LED_0402_1mm:LTSN-B28JEGBB | ~
 |  | D204 | LED_ARGB | Device:LED_ARGB | RGB_LED_0402_1mm:LTSN-B28JEGBB | ~
 |  | D205 | LED_ARGB | Device:LED_ARGB | RGB_LED_0402_1mm:LTSN-B28JEGBB | ~
 |  | D206 | LED_ARGB | Device:LED_ARGB | RGB_LED_0402_1mm:LTSN-B28JEGBB | ~
 |  | D207 | LED_ARGB | Device:LED_ARGB | RGB_LED_0402_1mm:LTSN-B28JEGBB | ~
 |  | D208 | LED_ARGB | Device:LED_ARGB | RGB_LED_0402_1mm:LTSN-B28JEGBB | ~
 |  | D209 | LED_ARGB | Device:LED_ARGB | RGB_LED_0402_1mm:LTSN-B28JEGBB | ~
 |  | D210 | LED_ARGB | Device:LED_ARGB | RGB_LED_0402_1mm:LTSN-B28JEGBB | ~
 |  | D211 | LED_ARGB | Device:LED_ARGB | RGB_LED_0402_1mm:LTSN-B28JEGBB | ~
 |  | D212 | LED_ARGB | Device:LED_ARGB | RGB_LED_0402_1mm:LTSN-B28JEGBB | ~
 |  | D213 | LED_ARGB | Device:LED_ARGB | RGB_LED_0402_1mm:LTSN-B28JEGBB | ~
 |  | D214 | LED_ARGB | Device:LED_ARGB | RGB_LED_0402_1mm:LTSN-B28JEGBB | ~
 |  | D215 | LED_ARGB | Device:LED_ARGB | RGB_LED_0402_1mm:LTSN-B28JEGBB | ~
 |  | D216 | LED_ARGB | Device:LED_ARGB | RGB_LED_0402_1mm:LTSN-B28JEGBB | ~
 |  | D217 | LED_ARGB | Device:LED_ARGB | RGB_LED_0402_1mm:LTSN-B28JEGBB | ~
 |  | D218 | LED_ARGB | Device:LED_ARGB | RGB_LED_0402_1mm:LTSN-B28JEGBB | ~
 |  | D219 | LED_ARGB | Device:LED_ARGB | RGB_LED_0402_1mm:LTSN-B28JEGBB | ~
 |  | D220 | LED_ARGB | Device:LED_ARGB | RGB_LED_0402_1mm:LTSN-B28JEGBB | ~
 |  | D221 | LED_ARGB | Device:LED_ARGB | RGB_LED_0402_1mm:LTSN-B28JEGBB | ~
 |  | D222 | LED_ARGB | Device:LED_ARGB | RGB_LED_0402_1mm:LTSN-B28JEGBB | ~
 |  | D223 | LED_ARGB | Device:LED_ARGB | RGB_LED_0402_1mm:LTSN-B28JEGBB | ~
 |  | D224 | LED_ARGB | Device:LED_ARGB | RGB_LED_0402_1mm:LTSN-B28JEGBB | ~
 |  | D225 | LED_ARGB | Device:LED_ARGB | RGB_LED_0402_1mm:LTSN-B28JEGBB | ~
 |  | D226 | LED_ARGB | Device:LED_ARGB | RGB_LED_0402_1mm:LTSN-B28JEGBB | ~
 |  | D227 | LED_ARGB | Device:LED_ARGB | RGB_LED_0402_1mm:LTSN-B28JEGBB | ~
 |  | D228 | LED_ARGB | Device:LED_ARGB | RGB_LED_0402_1mm:LTSN-B28JEGBB | ~
 |  | D229 | LED_ARGB | Device:LED_ARGB | RGB_LED_0402_1mm:LTSN-B28JEGBB | ~
 |  | D230 | LED_ARGB | Device:LED_ARGB | RGB_LED_0402_1mm:LTSN-B28JEGBB | ~
 |  | D231 | LED_ARGB | Device:LED_ARGB | RGB_LED_0402_1mm:LTSN-B28JEGBB | ~
 |  | D232 | LED_ARGB | Device:LED_ARGB | RGB_LED_0402_1mm:LTSN-B28JEGBB | ~
 |  | D233 | LED_ARGB | Device:LED_ARGB | RGB_LED_0402_1mm:LTSN-B28JEGBB | ~
 |  | D234 | LED_ARGB | Device:LED_ARGB | RGB_LED_0402_1mm:LTSN-B28JEGBB | ~
 |  | D235 | LED_ARGB | Device:LED_ARGB | RGB_LED_0402_1mm:LTSN-B28JEGBB | ~
 |  | D236 | LED_ARGB | Device:LED_ARGB | RGB_LED_0402_1mm:LTSN-B28JEGBB | ~
 |  | D237 | LED_ARGB | Device:LED_ARGB | RGB_LED_0402_1mm:LTSN-B28JEGBB | ~
 |  | D238 | LED_ARGB | Device:LED_ARGB | RGB_LED_0402_1mm:LTSN-B28JEGBB | ~
 |  | D239 | LED_ARGB | Device:LED_ARGB | RGB_LED_0402_1mm:LTSN-B28JEGBB | ~
 |  | D240 | LED_ARGB | Device:LED_ARGB | RGB_LED_0402_1mm:LTSN-B28JEGBB | ~
 |  | D241 | LED_ARGB | Device:LED_ARGB | RGB_LED_0402_1mm:LTSN-B28JEGBB | ~
 |  | D242 | LED_ARGB | Device:LED_ARGB | RGB_LED_0402_1mm:LTSN-B28JEGBB | ~
 |  | D243 | LED_ARGB | Device:LED_ARGB | RGB_LED_0402_1mm:LTSN-B28JEGBB | ~
 |  | D244 | LED_ARGB | Device:LED_ARGB | RGB_LED_0402_1mm:LTSN-B28JEGBB | ~
 |  | D245 | LED_ARGB | Device:LED_ARGB | RGB_LED_0402_1mm:LTSN-B28JEGBB | ~
 |  | D246 | LED_ARGB | Device:LED_ARGB | RGB_LED_0402_1mm:LTSN-B28JEGBB | ~
 |  | D247 | LED_ARGB | Device:LED_ARGB | RGB_LED_0402_1mm:LTSN-B28JEGBB | ~
 |  | D248 | LED_ARGB | Device:LED_ARGB | RGB_LED_0402_1mm:LTSN-B28JEGBB | ~
 |  | D249 | LED_ARGB | Device:LED_ARGB | RGB_LED_0402_1mm:LTSN-B28JEGBB | ~
 |  | D250 | LED_ARGB | Device:LED_ARGB | RGB_LED_0402_1mm:LTSN-B28JEGBB | ~
 |  | D251 | LED_ARGB | Device:LED_ARGB | RGB_LED_0402_1mm:LTSN-B28JEGBB | ~
 |  | D252 | LED_ARGB | Device:LED_ARGB | RGB_LED_0402_1mm:LTSN-B28JEGBB | ~
 |  | D253 | LED_ARGB | Device:LED_ARGB | RGB_LED_0402_1mm:LTSN-B28JEGBB | ~
 |  | D254 | LED_ARGB | Device:LED_ARGB | RGB_LED_0402_1mm:LTSN-B28JEGBB | ~
 |  | D255 | LED_ARGB | Device:LED_ARGB | RGB_LED_0402_1mm:LTSN-B28JEGBB | ~
 |  | D256 | LED_ARGB | Device:LED_ARGB | RGB_LED_0402_1mm:LTSN-B28JEGBB | ~
 |  | D257 | LED_ARGB | Device:LED_ARGB | RGB_LED_0402_1mm:LTSN-B28JEGBB | ~
 |  | D258 | LED_ARGB | Device:LED_ARGB | RGB_LED_0402_1mm:LTSN-B28JEGBB | ~
 |  | D259 | LED_ARGB | Device:LED_ARGB | RGB_LED_0402_1mm:LTSN-B28JEGBB | ~
 |  | D260 | LED_ARGB | Device:LED_ARGB | RGB_LED_0402_1mm:LTSN-B28JEGBB | ~
 |  | D261 | LED_ARGB | Device:LED_ARGB | RGB_LED_0402_1mm:LTSN-B28JEGBB | ~
 |  | D262 | LED_ARGB | Device:LED_ARGB | RGB_LED_0402_1mm:LTSN-B28JEGBB | ~
 |  | D263 | LED_ARGB | Device:LED_ARGB | RGB_LED_0402_1mm:LTSN-B28JEGBB | ~
 |  | D264 | LED_ARGB | Device:LED_ARGB | RGB_LED_0402_1mm:LTSN-B28JEGBB | ~
 |  | D265 | LED_ARGB | Device:LED_ARGB | RGB_LED_0402_1mm:LTSN-B28JEGBB | ~
 |  | D266 | LED_ARGB | Device:LED_ARGB | RGB_LED_0402_1mm:LTSN-B28JEGBB | ~
 |  | D267 | LED_ARGB | Device:LED_ARGB | RGB_LED_0402_1mm:LTSN-B28JEGBB | ~
 |  | D268 | LED_ARGB | Device:LED_ARGB | RGB_LED_0402_1mm:LTSN-B28JEGBB | ~
 |  | D269 | LED_ARGB | Device:LED_ARGB | RGB_LED_0402_1mm:LTSN-B28JEGBB | ~
 |  | D270 | LED_ARGB | Device:LED_ARGB | RGB_LED_0402_1mm:LTSN-B28JEGBB | ~
 |  | D271 | LED_ARGB | Device:LED_ARGB | RGB_LED_0402_1mm:LTSN-B28JEGBB | ~
 |  | D272 | LED_ARGB | Device:LED_ARGB | RGB_LED_0402_1mm:LTSN-B28JEGBB | ~
 |  | D273 | LED_ARGB | Device:LED_ARGB | RGB_LED_0402_1mm:LTSN-B28JEGBB | ~
 |  | D274 | LED_ARGB | Device:LED_ARGB | RGB_LED_0402_1mm:LTSN-B28JEGBB | ~
 |  | D275 | LED_ARGB | Device:LED_ARGB | RGB_LED_0402_1mm:LTSN-B28JEGBB | ~
 |  | D276 | LED_ARGB | Device:LED_ARGB | RGB_LED_0402_1mm:LTSN-B28JEGBB | ~
 |  | D277 | LED_ARGB | Device:LED_ARGB | RGB_LED_0402_1mm:LTSN-B28JEGBB | ~
 |  | D278 | LED_ARGB | Device:LED_ARGB | RGB_LED_0402_1mm:LTSN-B28JEGBB | ~
 |  | D279 | LED_ARGB | Device:LED_ARGB | RGB_LED_0402_1mm:LTSN-B28JEGBB | ~
 |  | D280 | LED_ARGB | Device:LED_ARGB | RGB_LED_0402_1mm:LTSN-B28JEGBB | ~
 |  | D281 | LED_ARGB | Device:LED_ARGB | RGB_LED_0402_1mm:LTSN-B28JEGBB | ~
 |  | D282 | LED_ARGB | Device:LED_ARGB | RGB_LED_0402_1mm:LTSN-B28JEGBB | ~
 |  | D283 | LED_ARGB | Device:LED_ARGB | RGB_LED_0402_1mm:LTSN-B28JEGBB | ~
 |  | D284 | LED_ARGB | Device:LED_ARGB | RGB_LED_0402_1mm:LTSN-B28JEGBB | ~
 |  | D285 | LED_ARGB | Device:LED_ARGB | RGB_LED_0402_1mm:LTSN-B28JEGBB | ~
 |  | D286 | LED_ARGB | Device:LED_ARGB | RGB_LED_0402_1mm:LTSN-B28JEGBB | ~
 |  | D287 | LED_ARGB | Device:LED_ARGB | RGB_LED_0402_1mm:LTSN-B28JEGBB | ~
 |  | D288 | LED_ARGB | Device:LED_ARGB | RGB_LED_0402_1mm:LTSN-B28JEGBB | ~
 |  | D289 | LED_ARGB | Device:LED_ARGB | RGB_LED_0402_1mm:LTSN-B28JEGBB | ~
 |  | D290 | LED_ARGB | Device:LED_ARGB | RGB_LED_0402_1mm:LTSN-B28JEGBB | ~
 |  | D291 | LED_ARGB | Device:LED_ARGB | RGB_LED_0402_1mm:LTSN-B28JEGBB | ~
 |  | D292 | LED_ARGB | Device:LED_ARGB | RGB_LED_0402_1mm:LTSN-B28JEGBB | ~
 |  | D293 | LED_ARGB | Device:LED_ARGB | RGB_LED_0402_1mm:LTSN-B28JEGBB | ~
 |  | D294 | LED_ARGB | Device:LED_ARGB | RGB_LED_0402_1mm:LTSN-B28JEGBB | ~
 |  | D295 | LED_ARGB | Device:LED_ARGB | RGB_LED_0402_1mm:LTSN-B28JEGBB | ~
 |  | D296 | LED_ARGB | Device:LED_ARGB | RGB_LED_0402_1mm:LTSN-B28JEGBB | ~
 |  | D297 | LED_ARGB | Device:LED_ARGB | RGB_LED_0402_1mm:LTSN-B28JEGBB | ~
 |  | D298 | LED_ARGB | Device:LED_ARGB | RGB_LED_0402_1mm:LTSN-B28JEGBB | ~
 |  | D299 | LED_ARGB | Device:LED_ARGB | RGB_LED_0402_1mm:LTSN-B28JEGBB | ~
 |  | D300 | LED_ARGB | Device:LED_ARGB | RGB_LED_0402_1mm:LTSN-B28JEGBB | ~
 |  | D301 | LED_ARGB | Device:LED_ARGB | RGB_LED_0402_1mm:LTSN-B28JEGBB | ~
 |  | D302 | LED_ARGB | Device:LED_ARGB | RGB_LED_0402_1mm:LTSN-B28JEGBB | ~
 |  | D303 | LED_ARGB | Device:LED_ARGB | RGB_LED_0402_1mm:LTSN-B28JEGBB | ~
 |  | D304 | LED_ARGB | Device:LED_ARGB | RGB_LED_0402_1mm:LTSN-B28JEGBB | ~
 |  | D305 | LED_ARGB | Device:LED_ARGB | RGB_LED_0402_1mm:LTSN-B28JEGBB | ~
 |  | D306 | LED_ARGB | Device:LED_ARGB | RGB_LED_0402_1mm:LTSN-B28JEGBB | ~
 |  | D307 | LED_ARGB | Device:LED_ARGB | RGB_LED_0402_1mm:LTSN-B28JEGBB | ~
 |  | D308 | LED_ARGB | Device:LED_ARGB | RGB_LED_0402_1mm:LTSN-B28JEGBB | ~
 |  | D309 | LED_ARGB | Device:LED_ARGB | RGB_LED_0402_1mm:LTSN-B28JEGBB | ~
 |  | D310 | LED_ARGB | Device:LED_ARGB | RGB_LED_0402_1mm:LTSN-B28JEGBB | ~
 |  | D311 | LED_ARGB | Device:LED_ARGB | RGB_LED_0402_1mm:LTSN-B28JEGBB | ~
 |  | D312 | LED_ARGB | Device:LED_ARGB | RGB_LED_0402_1mm:LTSN-B28JEGBB | ~
 |  | D313 | LED_ARGB | Device:LED_ARGB | RGB_LED_0402_1mm:LTSN-B28JEGBB | ~
 |  | D314 | LED_ARGB | Device:LED_ARGB | RGB_LED_0402_1mm:LTSN-B28JEGBB | ~
 |  | D315 | LED_ARGB | Device:LED_ARGB | RGB_LED_0402_1mm:LTSN-B28JEGBB | ~
 |  | D316 | LED_ARGB | Device:LED_ARGB | RGB_LED_0402_1mm:LTSN-B28JEGBB | ~
 |  | D317 | LED_ARGB | Device:LED_ARGB | RGB_LED_0402_1mm:LTSN-B28JEGBB | ~
 |  | D318 | LED_ARGB | Device:LED_ARGB | RGB_LED_0402_1mm:LTSN-B28JEGBB | ~
 |  | D319 | LED_ARGB | Device:LED_ARGB | RGB_LED_0402_1mm:LTSN-B28JEGBB | ~
 |  | D320 | LED_ARGB | Device:LED_ARGB | RGB_LED_0402_1mm:LTSN-B28JEGBB | ~
 |  | D321 | LED_ARGB | Device:LED_ARGB | RGB_LED_0402_1mm:LTSN-B28JEGBB | ~
 |  | D322 | LED_ARGB | Device:LED_ARGB | RGB_LED_0402_1mm:LTSN-B28JEGBB | ~
 |  | D323 | LED_ARGB | Device:LED_ARGB | RGB_LED_0402_1mm:LTSN-B28JEGBB | ~
 |  | D324 | LED_ARGB | Device:LED_ARGB | RGB_LED_0402_1mm:LTSN-B28JEGBB | ~
 |  | D325 | LED_ARGB | Device:LED_ARGB | RGB_LED_0402_1mm:LTSN-B28JEGBB | ~
 |  | D326 | LED_ARGB | Device:LED_ARGB | RGB_LED_0402_1mm:LTSN-B28JEGBB | ~
 |  | D327 | LED_ARGB | Device:LED_ARGB | RGB_LED_0402_1mm:LTSN-B28JEGBB | ~
 |  | D328 | LED_ARGB | Device:LED_ARGB | RGB_LED_0402_1mm:LTSN-B28JEGBB | ~
 |  | D329 | LED_ARGB | Device:LED_ARGB | RGB_LED_0402_1mm:LTSN-B28JEGBB | ~
 |  | D330 | LED_ARGB | Device:LED_ARGB | RGB_LED_0402_1mm:LTSN-B28JEGBB | ~
 |  | D331 | LED_ARGB | Device:LED_ARGB | RGB_LED_0402_1mm:LTSN-B28JEGBB | ~
 |  | D332 | LED_ARGB | Device:LED_ARGB | RGB_LED_0402_1mm:LTSN-B28JEGBB | ~
 |  | D333 | LED_ARGB | Device:LED_ARGB | RGB_LED_0402_1mm:LTSN-B28JEGBB | ~
 |  | D334 | LED_ARGB | Device:LED_ARGB | RGB_LED_0402_1mm:LTSN-B28JEGBB | ~
 |  | D335 | LED_ARGB | Device:LED_ARGB | RGB_LED_0402_1mm:LTSN-B28JEGBB | ~
 |  | D336 | LED_ARGB | Device:LED_ARGB | RGB_LED_0402_1mm:LTSN-B28JEGBB | ~
 |  | D337 | LED_ARGB | Device:LED_ARGB | RGB_LED_0402_1mm:LTSN-B28JEGBB | ~
 |  | D338 | LED_ARGB | Device:LED_ARGB | RGB_LED_0402_1mm:LTSN-B28JEGBB | ~
 |  | D339 | LED_ARGB | Device:LED_ARGB | RGB_LED_0402_1mm:LTSN-B28JEGBB | ~
 |  | D340 | LED_ARGB | Device:LED_ARGB | RGB_LED_0402_1mm:LTSN-B28JEGBB | ~
 |  | D341 | LED_ARGB | Device:LED_ARGB | RGB_LED_0402_1mm:LTSN-B28JEGBB | ~
 |  | D342 | LED_ARGB | Device:LED_ARGB | RGB_LED_0402_1mm:LTSN-B28JEGBB | ~
 |  | D343 | LED_ARGB | Device:LED_ARGB | RGB_LED_0402_1mm:LTSN-B28JEGBB | ~
 |  | D344 | LED_ARGB | Device:LED_ARGB | RGB_LED_0402_1mm:LTSN-B28JEGBB | ~
 |  | D345 | LED_ARGB | Device:LED_ARGB | RGB_LED_0402_1mm:LTSN-B28JEGBB | ~
 |  | D346 | LED_ARGB | Device:LED_ARGB | RGB_LED_0402_1mm:LTSN-B28JEGBB | ~
 |  | D347 | LED_ARGB | Device:LED_ARGB | RGB_LED_0402_1mm:LTSN-B28JEGBB | ~
 |  | D348 | LED_ARGB | Device:LED_ARGB | RGB_LED_0402_1mm:LTSN-B28JEGBB | ~
 |  | D349 | LED_ARGB | Device:LED_ARGB | RGB_LED_0402_1mm:LTSN-B28JEGBB | ~
 |  | D350 | LED_ARGB | Device:LED_ARGB | RGB_LED_0402_1mm:LTSN-B28JEGBB | ~
 |  | D351 | LED_ARGB | Device:LED_ARGB | RGB_LED_0402_1mm:LTSN-B28JEGBB | ~
 |  | D352 | LED_ARGB | Device:LED_ARGB | RGB_LED_0402_1mm:LTSN-B28JEGBB | ~
 |  | D353 | LED_ARGB | Device:LED_ARGB | RGB_LED_0402_1mm:LTSN-B28JEGBB | ~
 |  | D354 | LED_ARGB | Device:LED_ARGB | RGB_LED_0402_1mm:LTSN-B28JEGBB | ~
 |  | D355 | LED_ARGB | Device:LED_ARGB | RGB_LED_0402_1mm:LTSN-B28JEGBB | ~
 |  | D356 | LED_ARGB | Device:LED_ARGB | RGB_LED_0402_1mm:LTSN-B28JEGBB | ~
 |  | D357 | LED_ARGB | Device:LED_ARGB | RGB_LED_0402_1mm:LTSN-B28JEGBB | ~
 |  | D358 | LED_ARGB | Device:LED_ARGB | RGB_LED_0402_1mm:LTSN-B28JEGBB | ~
 |  | D359 | LED_ARGB | Device:LED_ARGB | RGB_LED_0402_1mm:LTSN-B28JEGBB | ~
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

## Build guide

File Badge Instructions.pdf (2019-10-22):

Hello Agent! You have a new mission: Help the Allies decode secret messages from the Enemy. You have acquired an enigma machine and have intercepted a code sheet! This will enable you and your fellow agents to decode encrypted messages sent by the Enemy.

How to use your enigma machine:
- When you turn it on, it will enter the menu from which you should select “Enigma Emulator” using W,S keys to go up/down through the menu and K for “Enter” to select an option.
- Use the W,A,S,D keys to change the various enigma settings. Use the provided wires to connect the plugboard according to the code sheet. Use the K key for “Enter” to start encoding/decoding messages.
- After you’re finished, press and hold any key for 3 seconds to go back to the main menu.

How to use the code sheet:
- The code sheet contains one month of daily enigma codes. It includes the Rotor numbers (Walzenlage), Ring settings (Ringstellung), Plugboard settings (Steckerverbindungen), and Key type (Kenngruppen). You enter these settings into the enigma machine based on the date of the message.
- Here is a sample of an intercepted message:

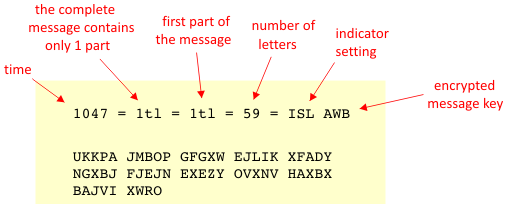
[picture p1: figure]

The first 5 letters of the message (Buchstabenkenngruppe) are plaintext. The first 2 letters are randomly chosen and do not matter. The next 3 letters (Kenngruppe) tell you which code sheet the message uses. If those 3 letters don’t match any of the Kengruppen for the day, the mesage is meant for a different military unit (Army, Navy, Command, etc), each of which used different code sheets.

Deciphering Procedure (example using sample message above):
1. Apply the daily key from the code sheet to your Enigma machine.
2. Look for the indicator setting (ISL) in the unenciphered preamble of the message, and apply those settings to the rotors.
3. Look for the encrypted message key (AWB) in the preamble, and type on the Enigma the letters A, W and B with the settings described under point 1 and 2. The result will be the message key ETG.
4. Change the rotor settings to ETG, supplied by the message key.
5. Type in the encrypted text blocks after the first five letter block. The result is the plain text!

Hint: Commanders can help if you get stuck. You can identify them by the shiny emblems on their badges.

Good luck!

Image and some text borrowed from: https://www.matematiksider.dk/enigma_eng.html

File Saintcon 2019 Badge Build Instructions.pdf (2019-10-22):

# How to build your Saintcon 2019 badge

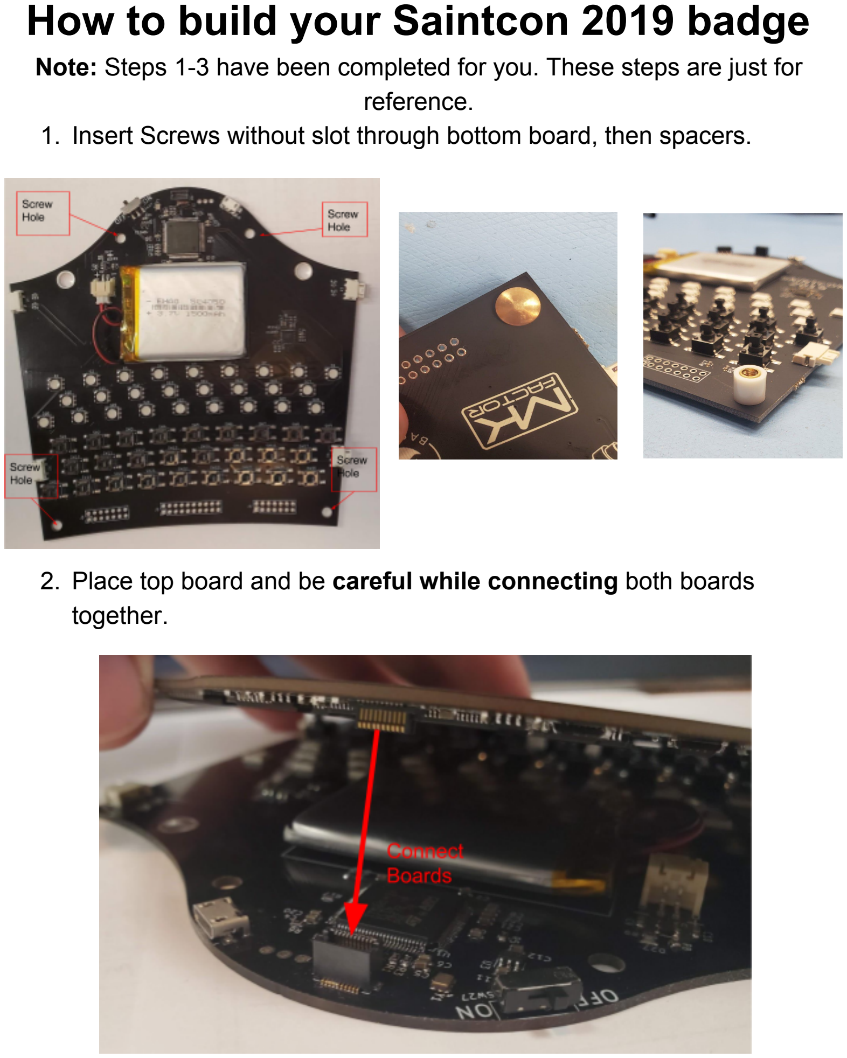
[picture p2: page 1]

Note: Steps 1-3 have been completed for you. These steps are just for reference.
1. Insert Screws without slot through bottom board, then spacers.
2. Place top board and be careful while connecting both boards together.

3. Put slotted screws through top board. Be careful not to overtighten the screws!

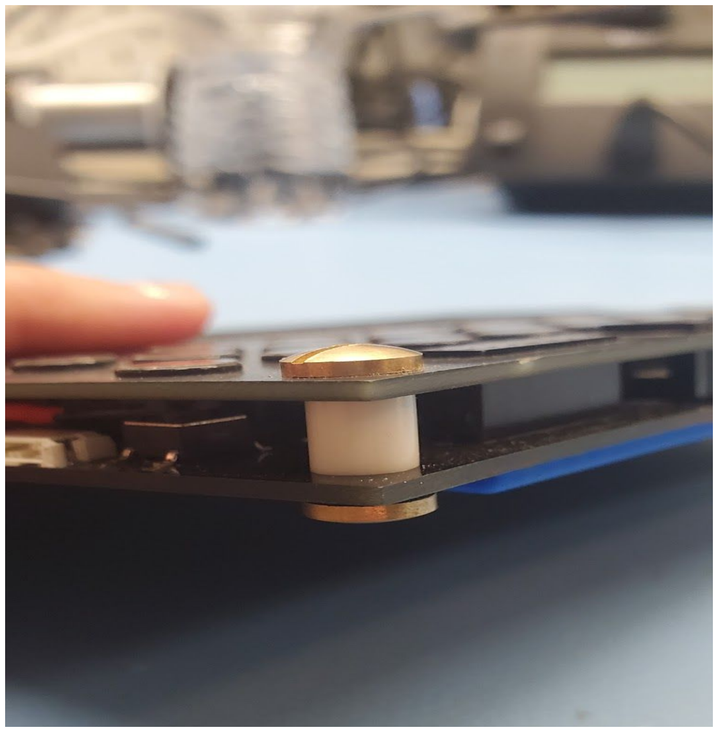
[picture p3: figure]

4. Place the connectors Solder minibadge connector WITH NOTCH FACING BOTTOM OF BOARD (This matters!) and then solder on both female plugboard connectors.

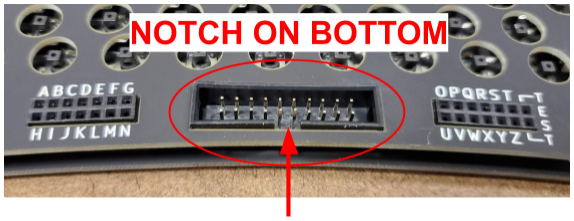
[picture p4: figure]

5. Your board is now assembled! Take it to the nearest flashing station to get the latest code.

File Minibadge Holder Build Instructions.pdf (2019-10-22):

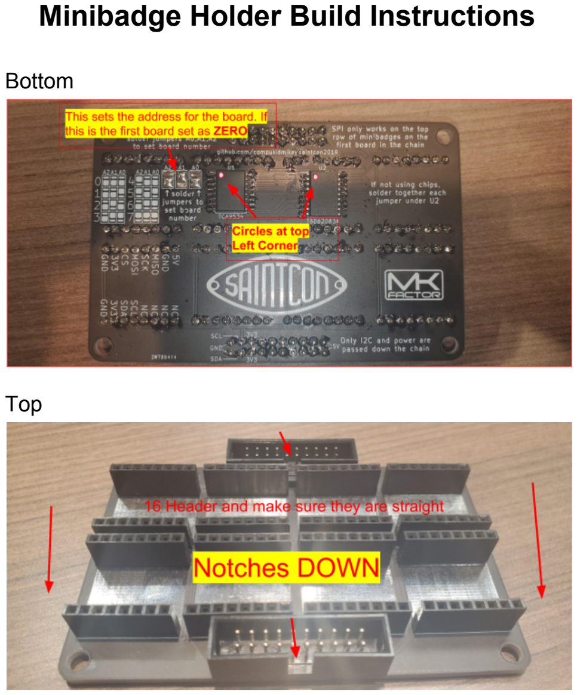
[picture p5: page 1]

Minibadge Holder Build Instructions

Bottom

Top

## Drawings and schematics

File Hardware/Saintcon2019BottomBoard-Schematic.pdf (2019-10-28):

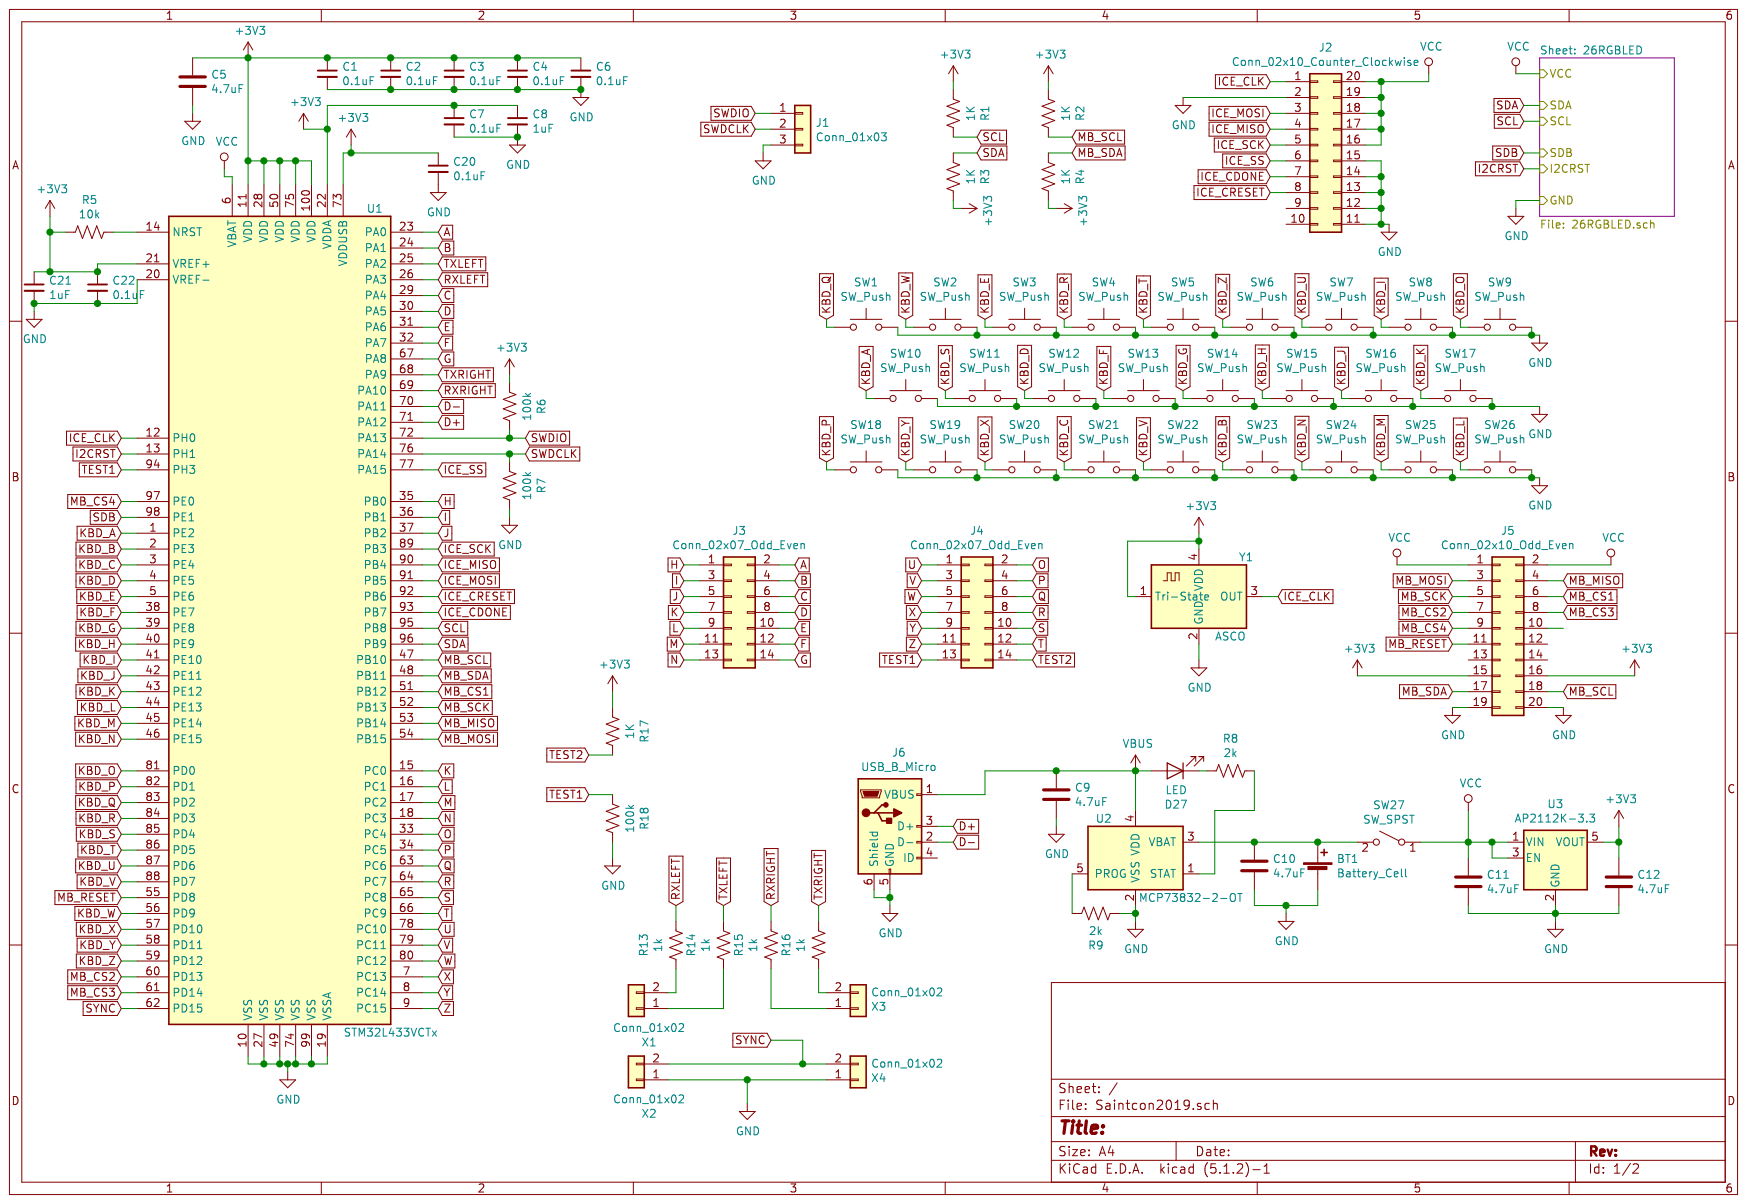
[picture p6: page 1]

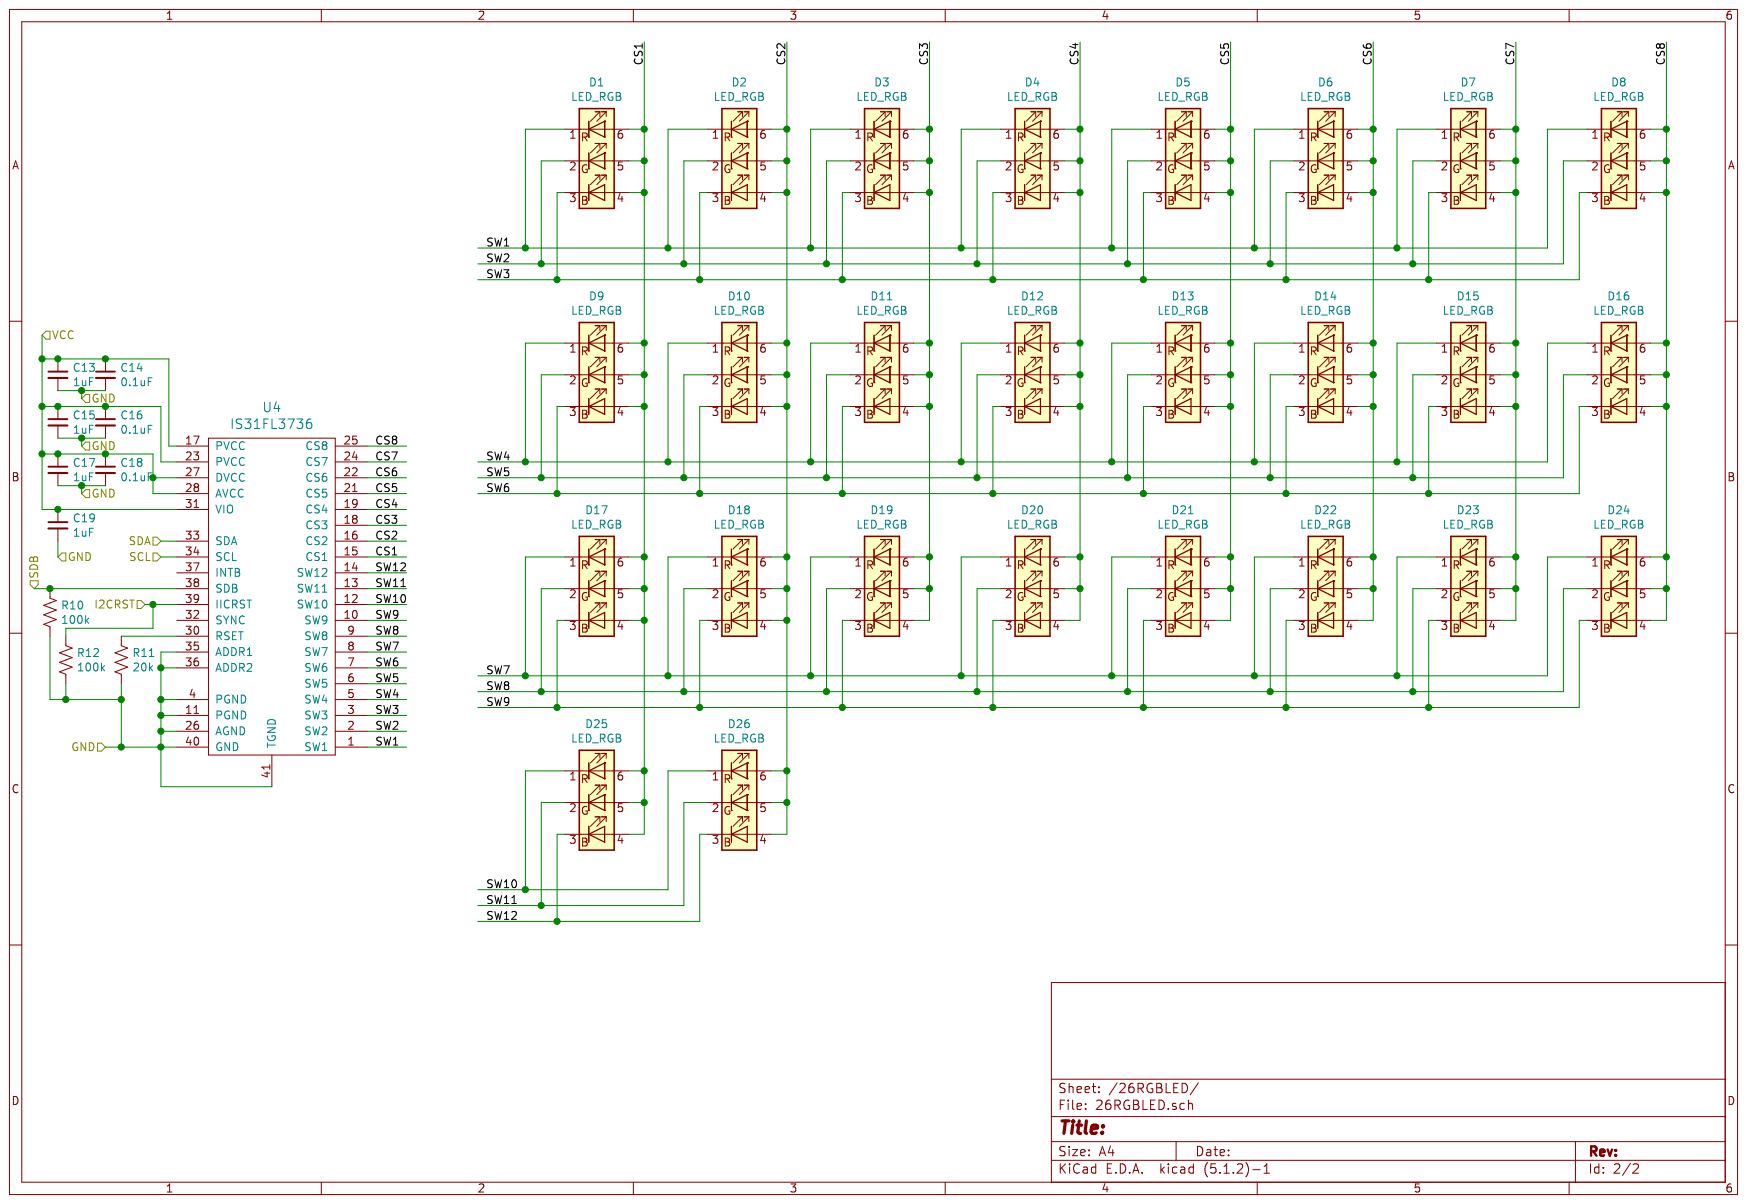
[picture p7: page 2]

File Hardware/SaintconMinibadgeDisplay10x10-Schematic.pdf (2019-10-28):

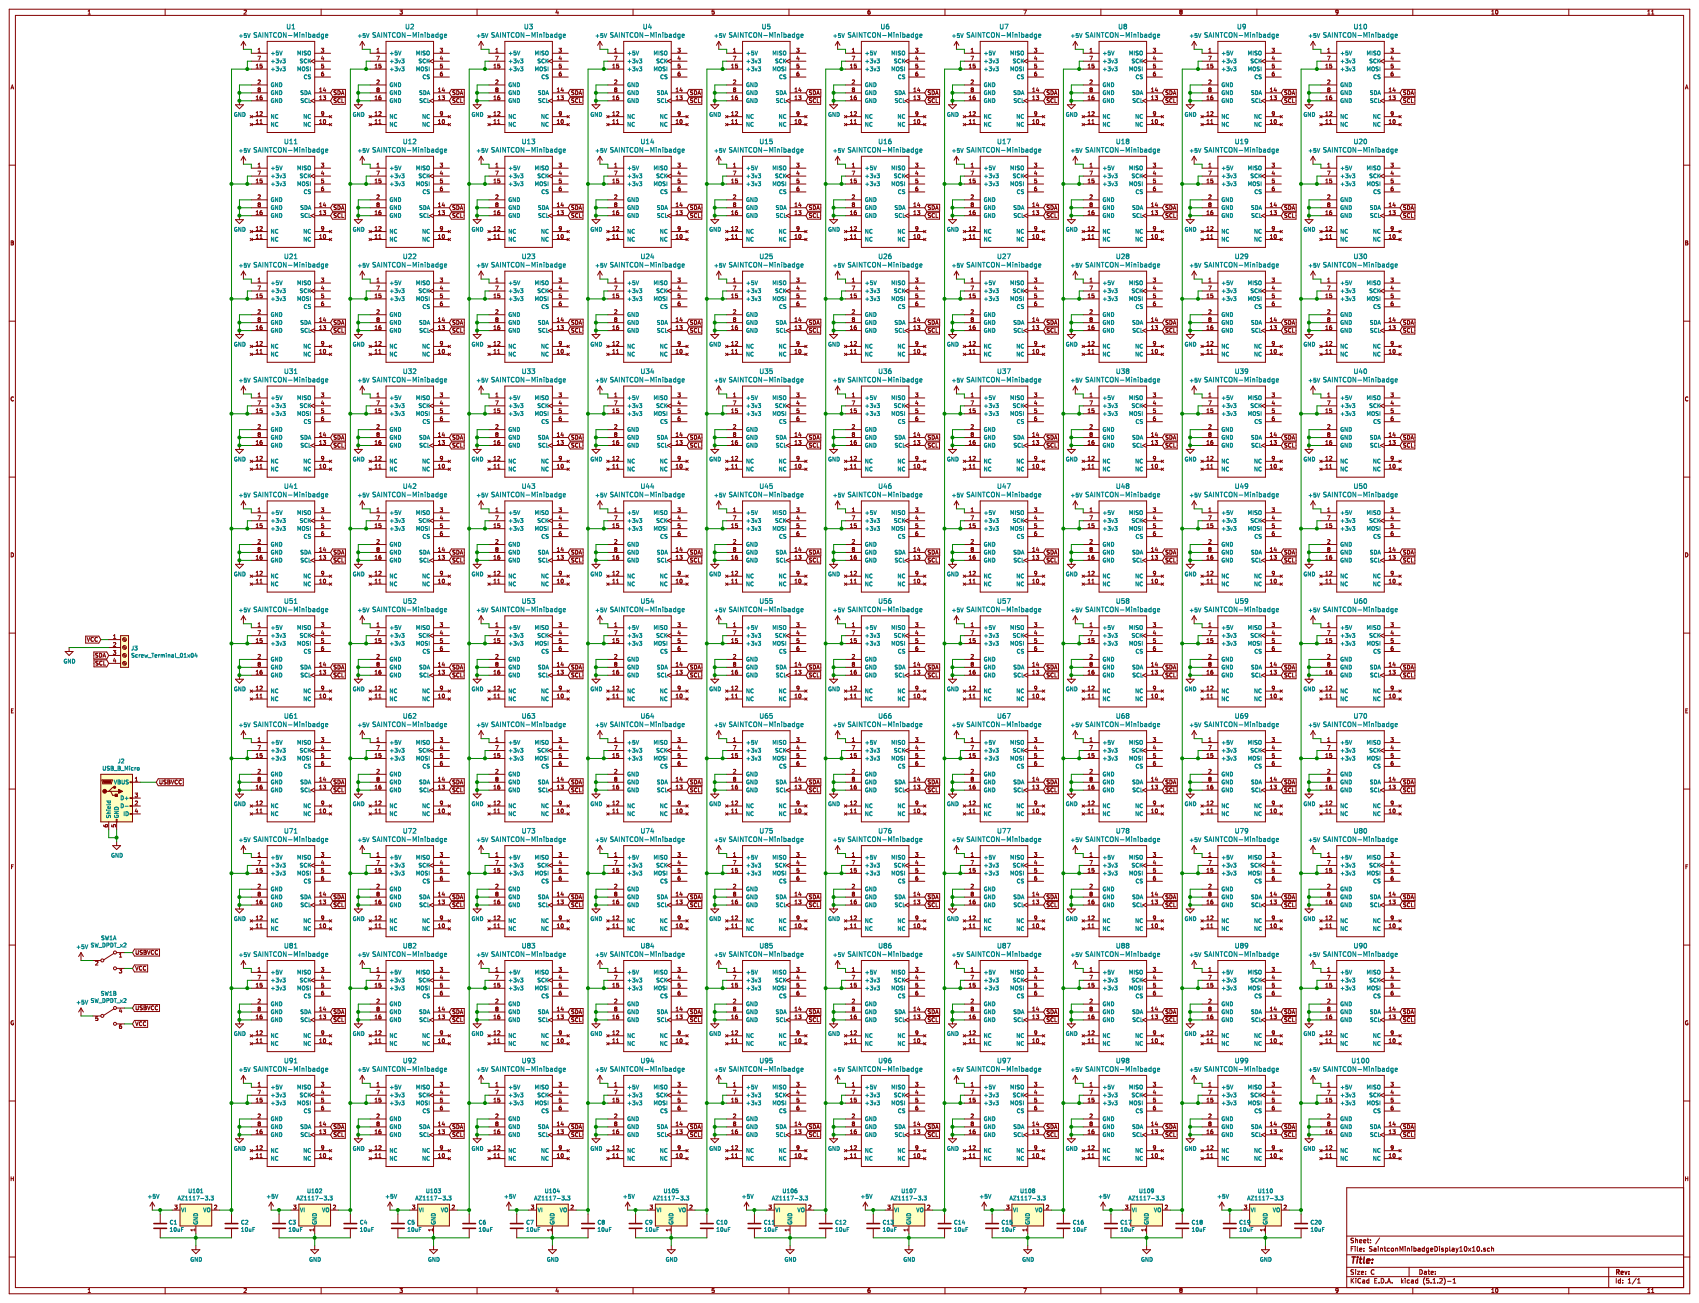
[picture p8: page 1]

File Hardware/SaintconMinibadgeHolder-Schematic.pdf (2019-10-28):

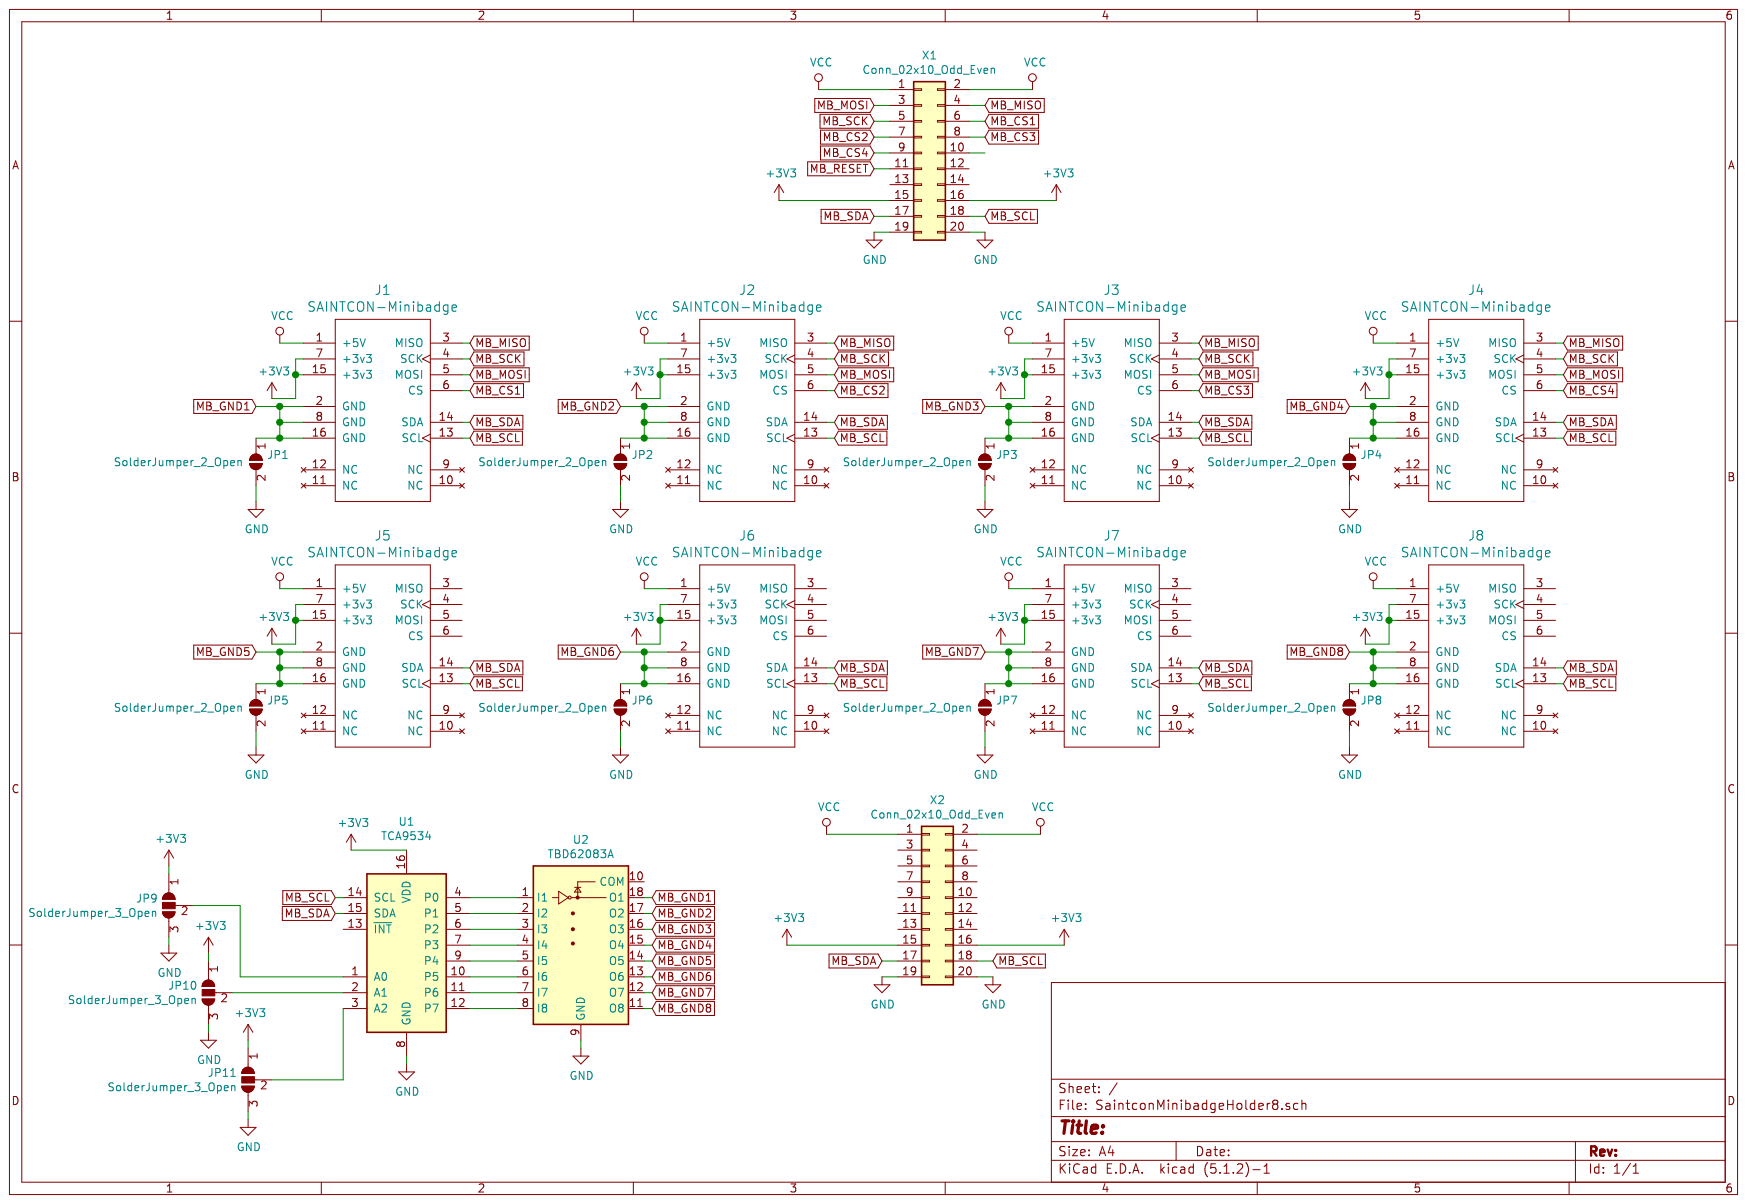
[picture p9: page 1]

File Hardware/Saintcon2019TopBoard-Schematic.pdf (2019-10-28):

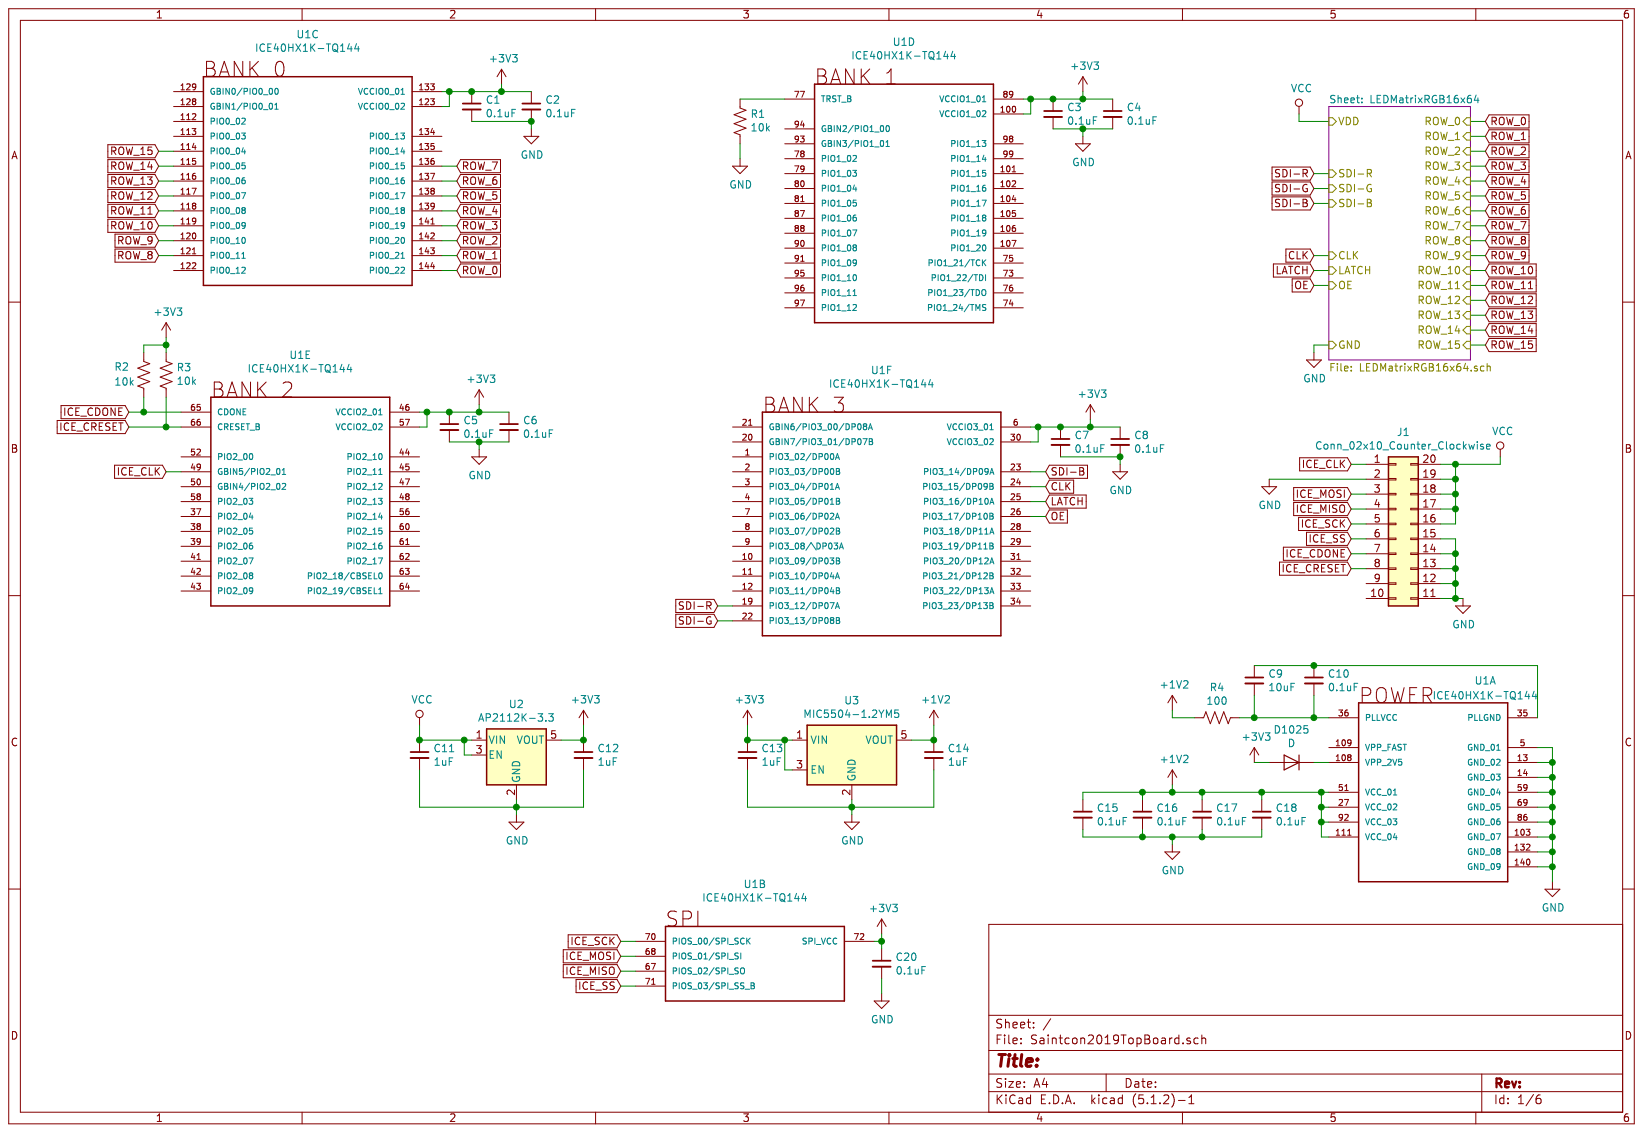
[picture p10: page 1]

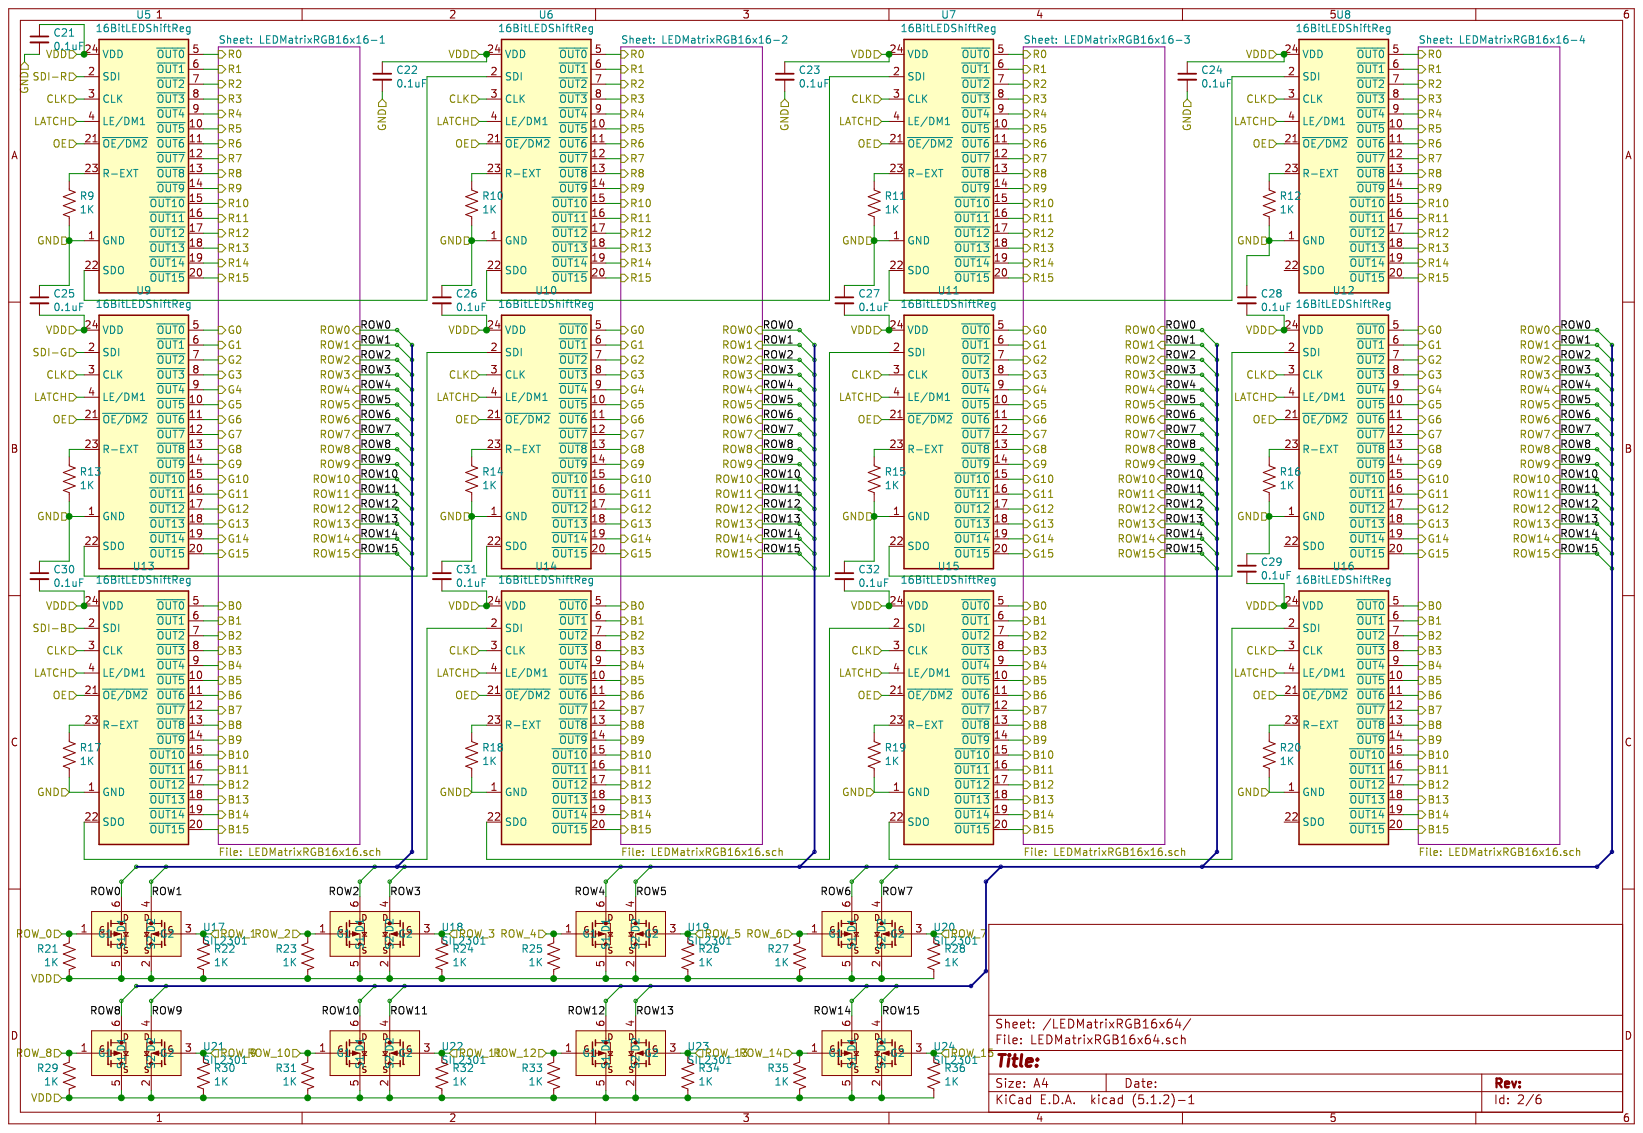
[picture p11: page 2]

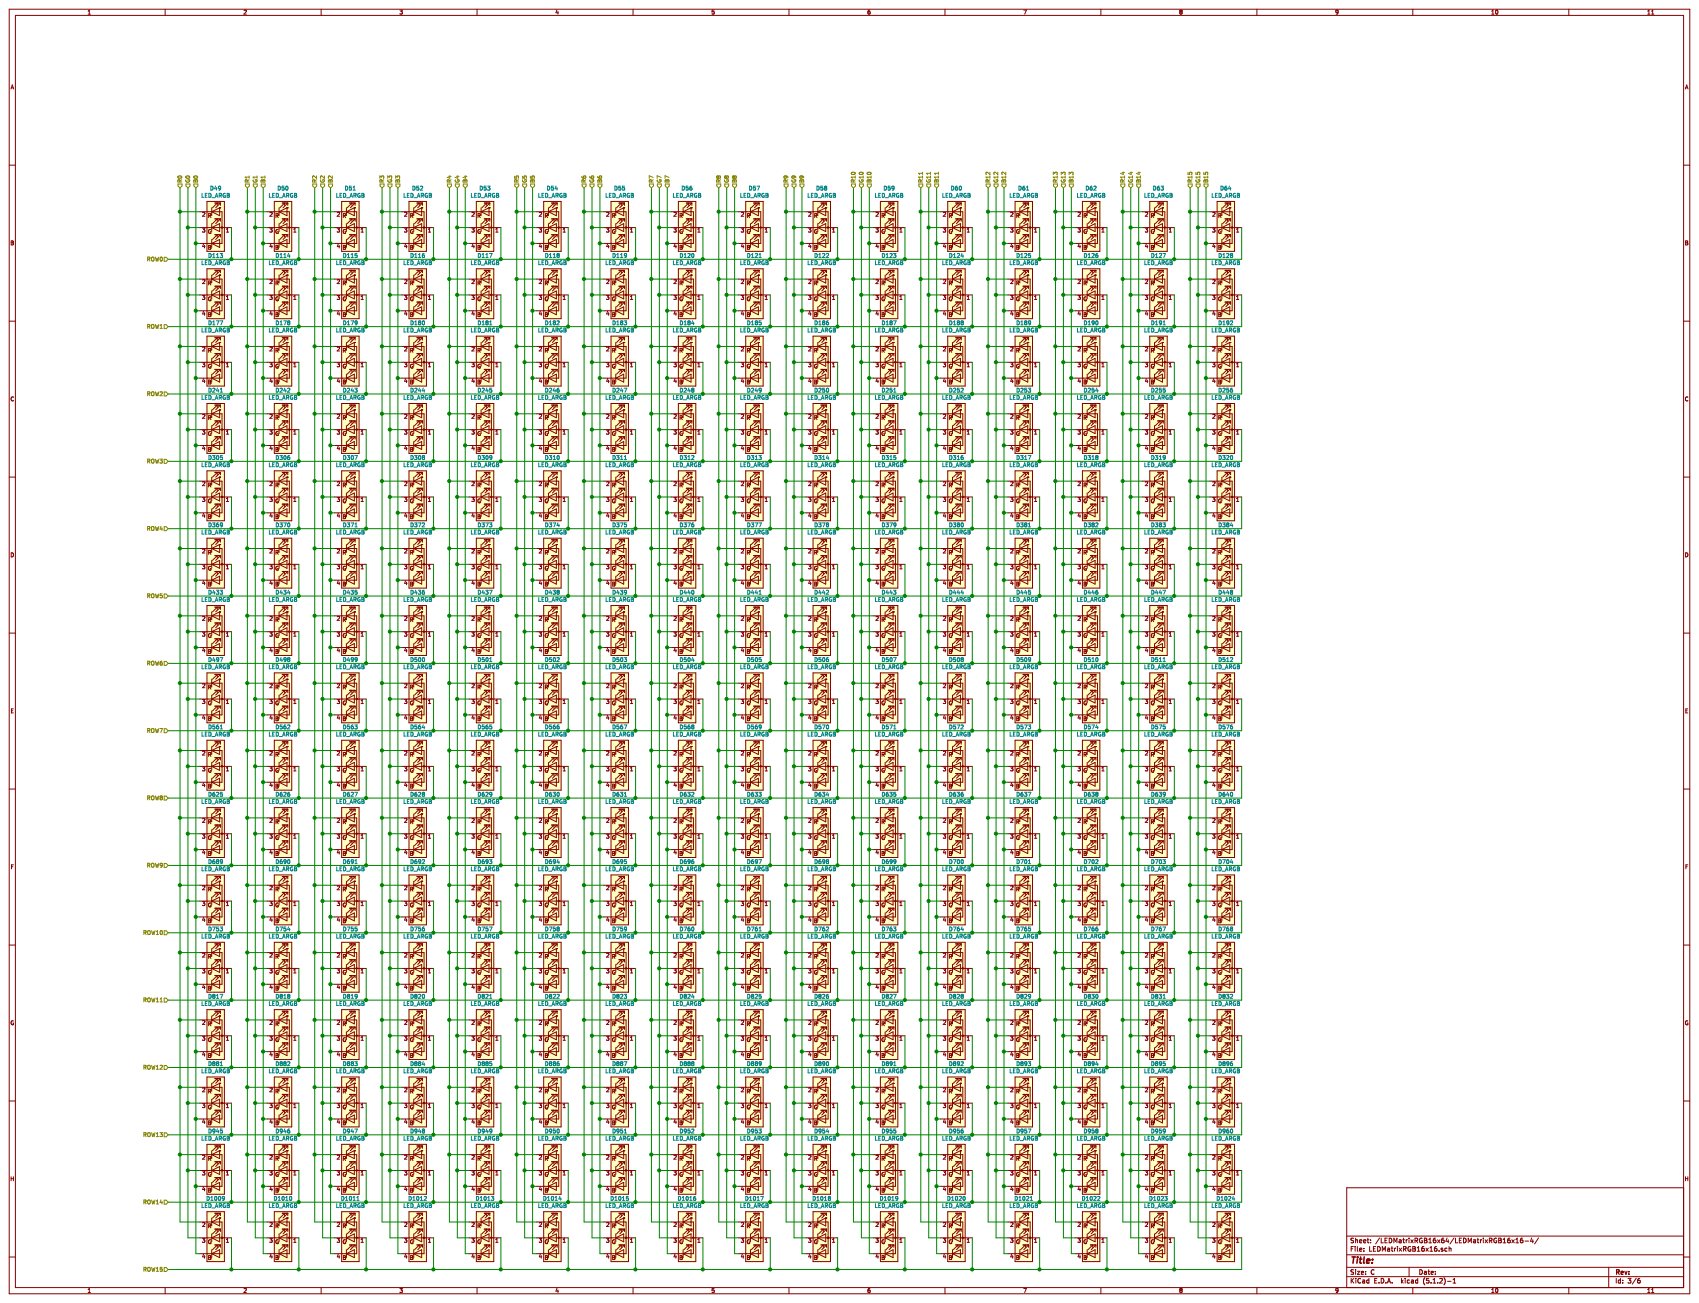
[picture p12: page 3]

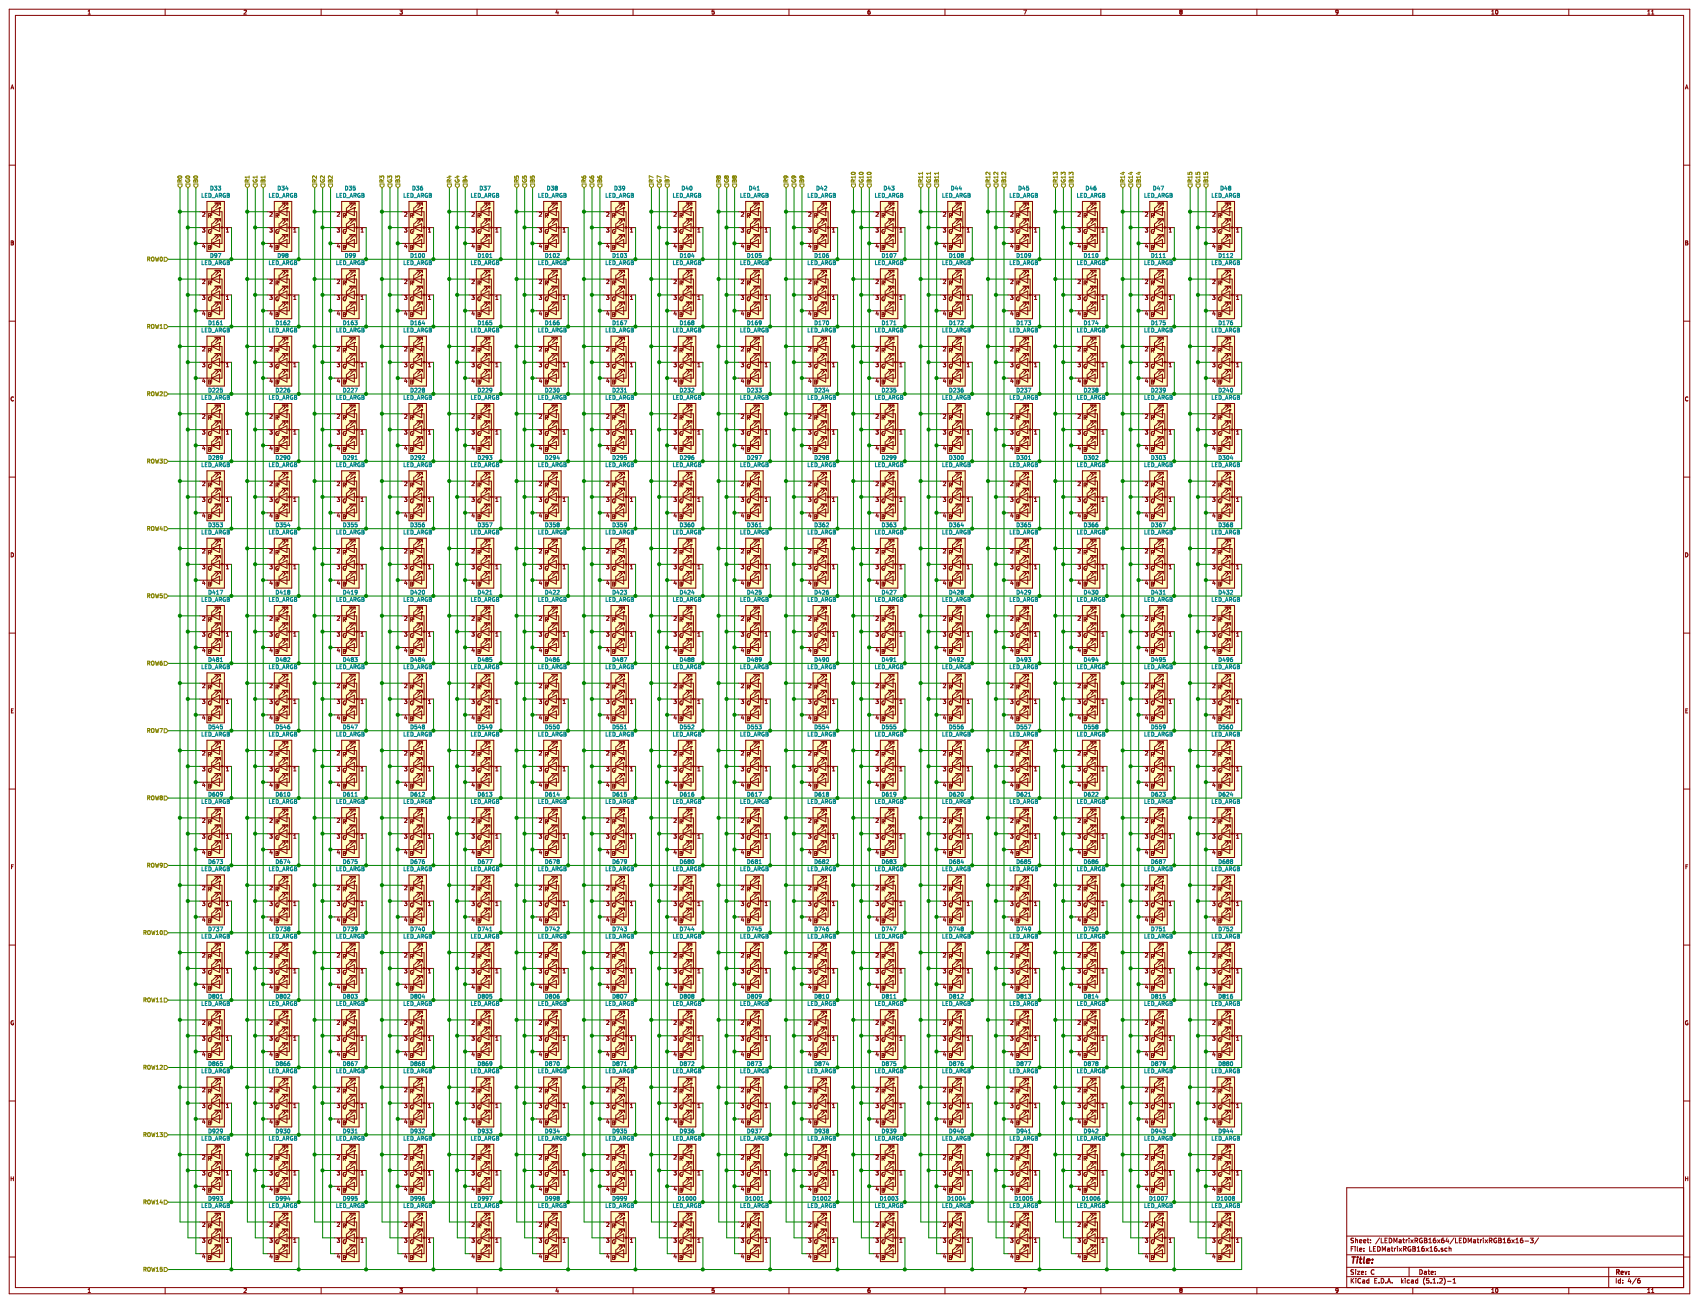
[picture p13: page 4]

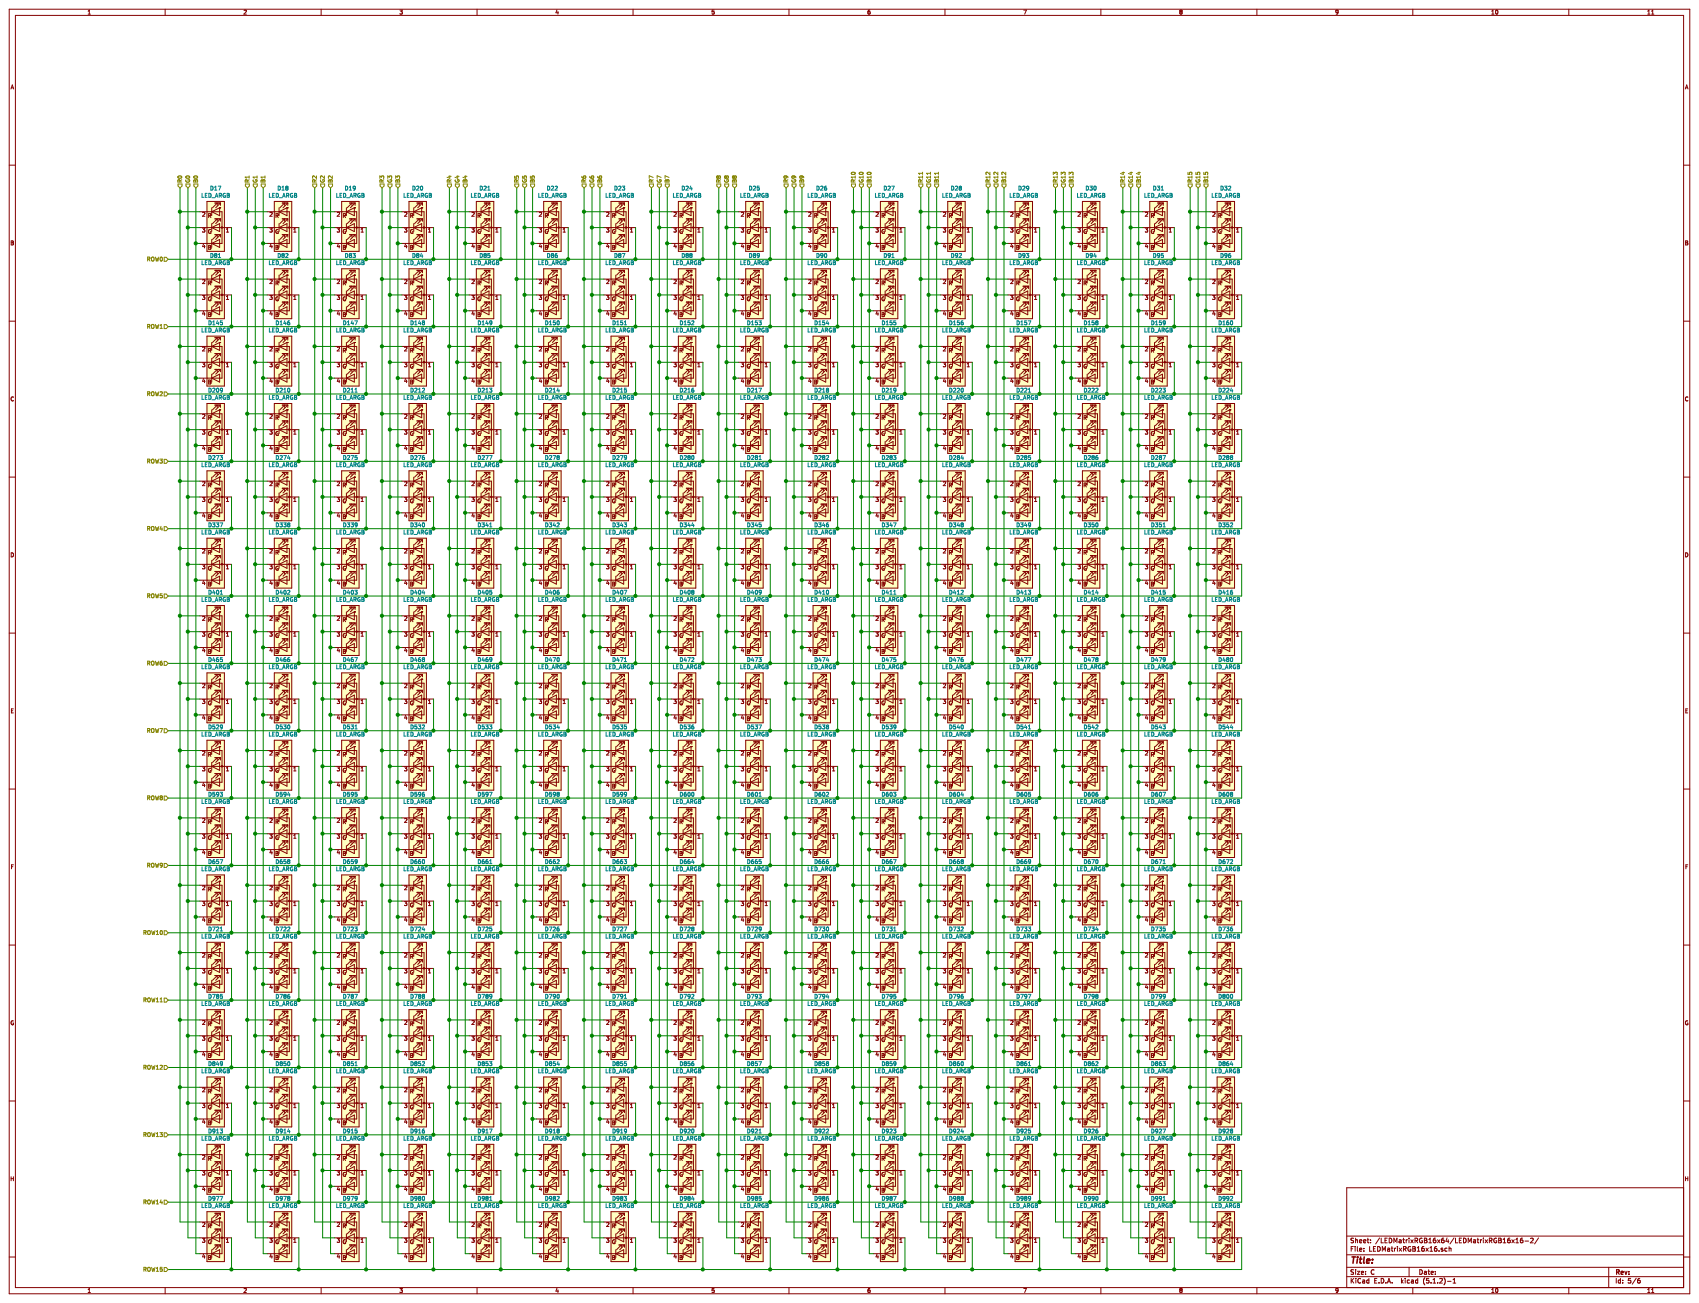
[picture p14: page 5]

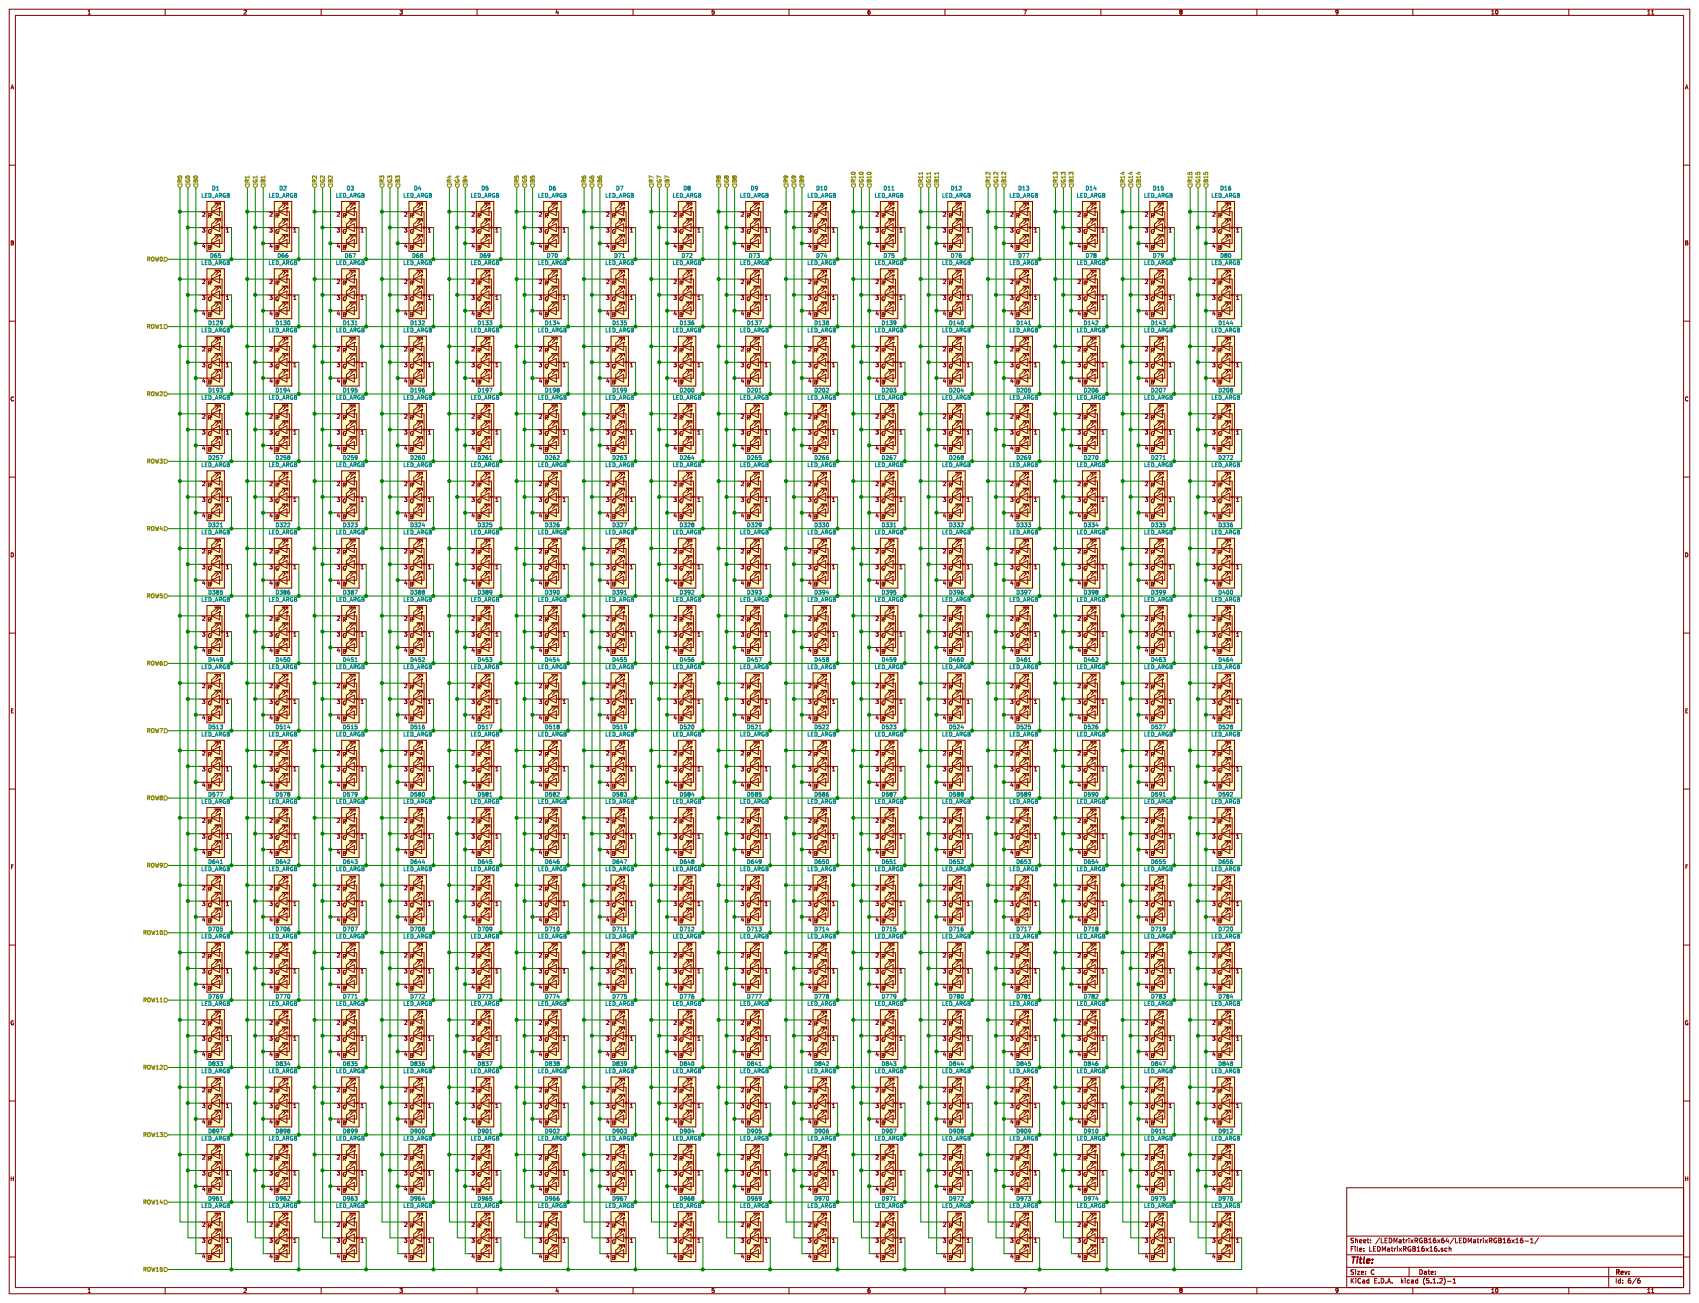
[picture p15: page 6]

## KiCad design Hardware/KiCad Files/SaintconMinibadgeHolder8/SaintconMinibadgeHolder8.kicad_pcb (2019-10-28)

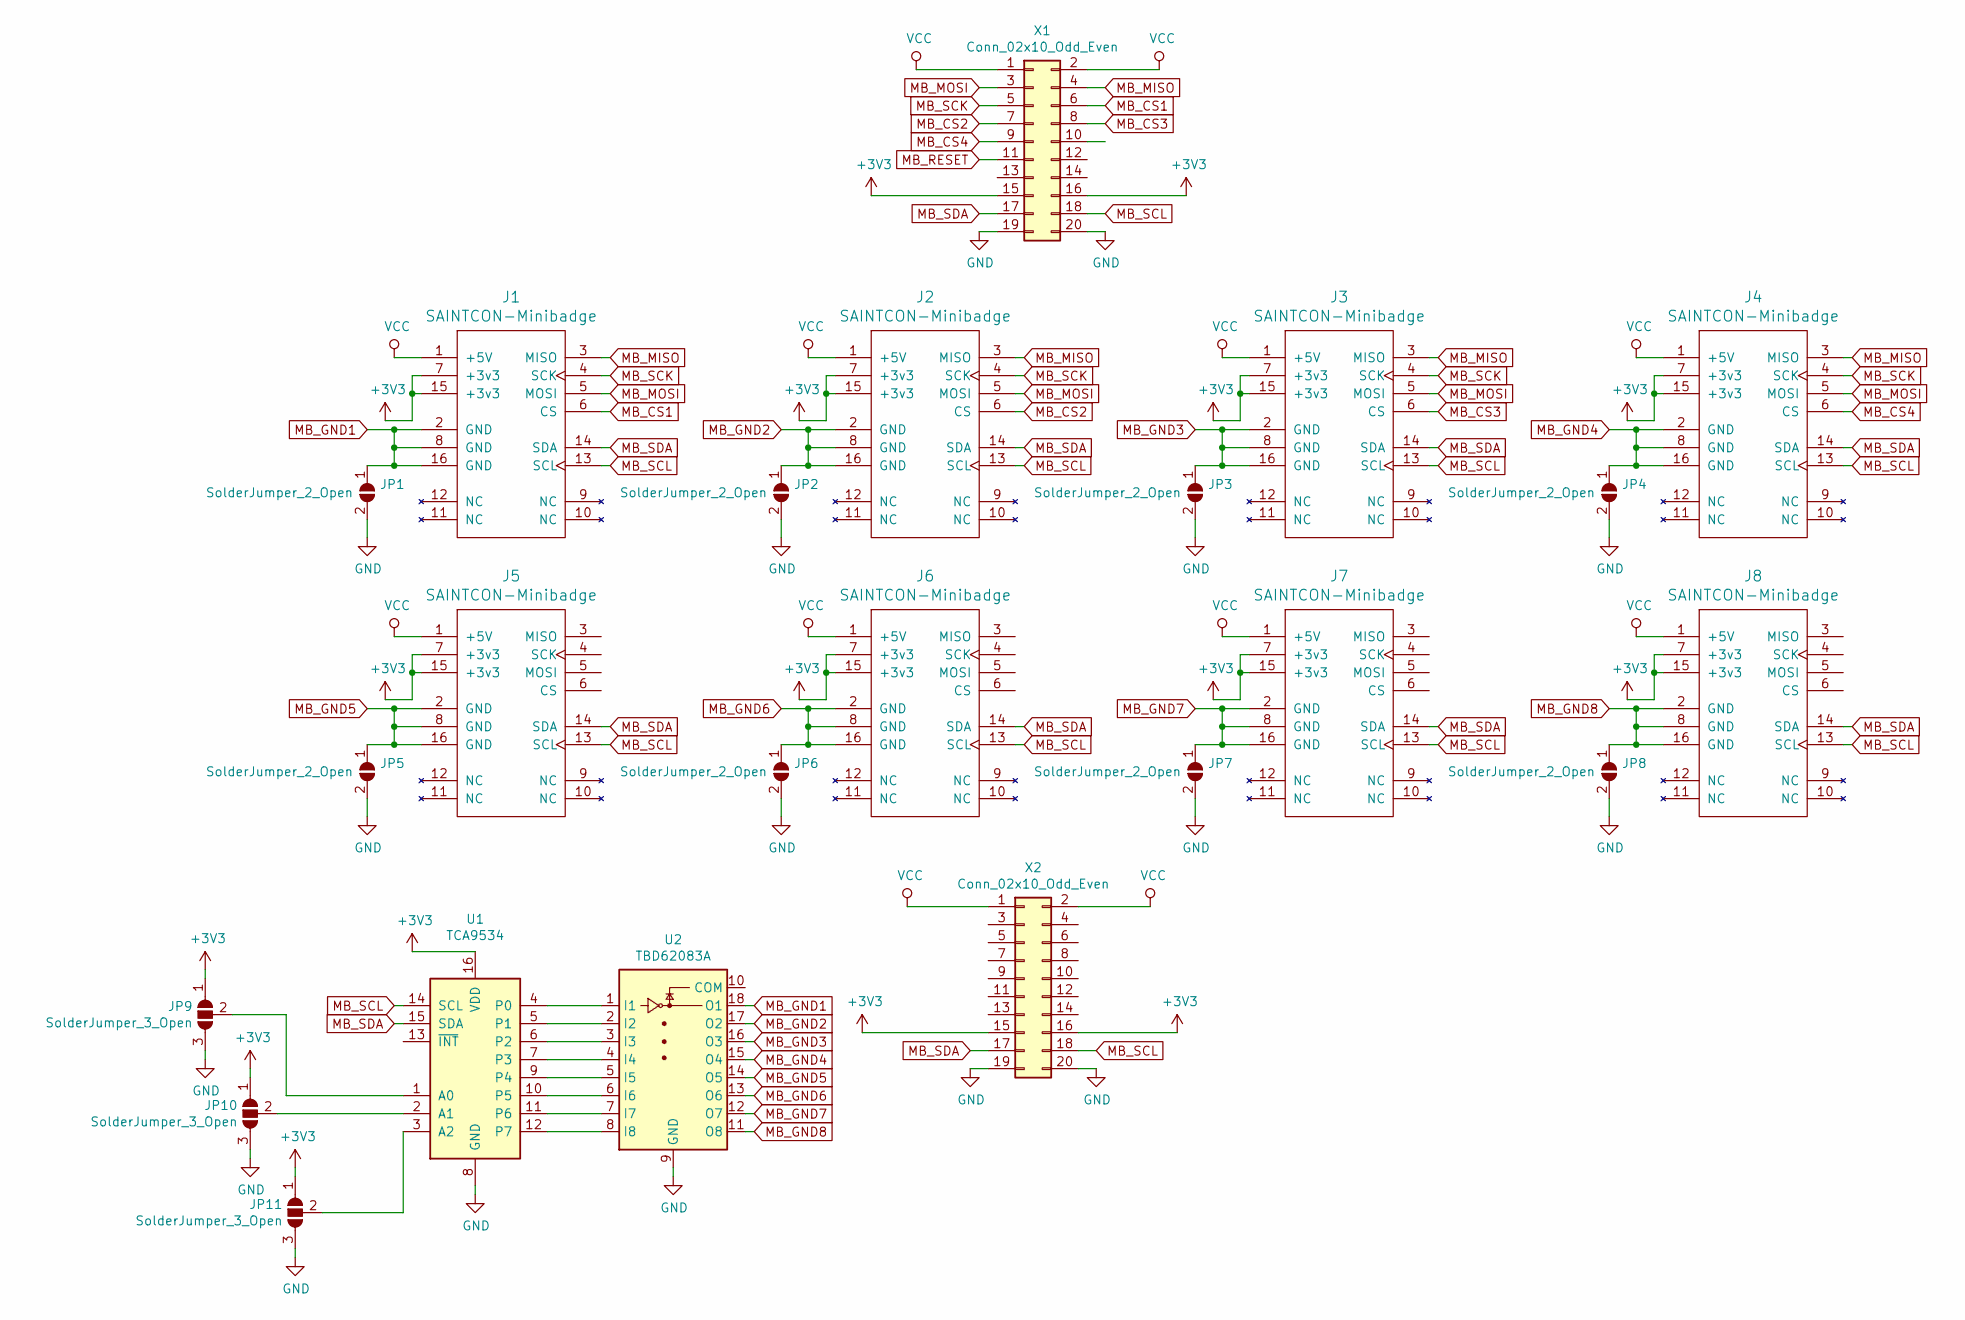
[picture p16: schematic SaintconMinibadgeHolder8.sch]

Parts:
J1, J2, J3, J4, J5, J6, J7, J8: SAINTCON-Minibadge; SAINTCON-Minibadge-Shiny
JP1, JP2, JP3, JP4, JP5, JP6, JP7, JP8: SolderJumper_2_Open; PAD-JUMPER-2-NO_YES_SILK
JP9, JP10, JP11: SolderJumper_3_Open; PAD-JUMPER-3-NO_YES_SILK
U1: TCA9534; SOIC-16W_7.5x10.3mm_Pitch1.27mm
U2: TBD62083A; SOIC-18W_7.5x11.6mm_Pitch1.27mm
X1, X2: Conn_02x10_Odd_Even; Pin_Header_Straight_2x10_Pitch2.54mm

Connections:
+3V3: J1.7 (+3v3), J1.15 (+3v3), J2.7 (+3v3), J2.15 (+3v3), J3.7 (+3v3), J3.15 (+3v3), J4.7 (+3v3), J4.15 (+3v3), J5.7 (+3v3), J5.15 (+3v3), J6.7 (+3v3), J6.15 (+3v3), J7.7 (+3v3), J7.15 (+3v3), J8.7 (+3v3), J8.15 (+3v3), JP9.1 (A), JP10.1 (A), JP11.1 (A), U1.16 (VDD), X1.15, X1.16, X2.15, X2.16
GND: JP1.2 (B), JP2.2 (B), JP3.2 (B), JP4.2 (B), JP5.2 (B), JP6.2 (B), JP7.2 (B), JP8.2 (B), JP9.3 (B), JP10.3 (B), JP11.3 (B), U1.8 (GND), U2.9 (GND), X1.19, X1.20, X2.19, X2.20
MB_CS1: J1.6 (CS), X1.6
MB_CS2: J2.6 (CS), X1.7
MB_CS3: J3.6 (CS), X1.8
MB_CS4: J4.6 (CS), X1.9
MB_GND1: J1.2 (GND), J1.8 (GND), J1.16 (GND), JP1.1 (A), U2.18 (O1)
MB_GND2: J2.2 (GND), J2.8 (GND), J2.16 (GND), JP2.1 (A), U2.17 (O2)
MB_GND3: J3.2 (GND), J3.8 (GND), J3.16 (GND), JP3.1 (A), U2.16 (O3)
MB_GND4: J4.2 (GND), J4.8 (GND), J4.16 (GND), JP4.1 (A), U2.15 (O4)
MB_GND5: J5.2 (GND), J5.8 (GND), J5.16 (GND), JP5.1 (A), U2.14 (O5)
MB_GND6: J6.2 (GND), J6.8 (GND), J6.16 (GND), JP6.1 (A), U2.13 (O6)
MB_GND7: J7.2 (GND), J7.8 (GND), J7.16 (GND), JP7.1 (A), U2.12 (O7)
MB_GND8: J8.2 (GND), J8.8 (GND), J8.16 (GND), JP8.1 (A), U2.11 (O8)
MB_MISO: J1.3 (MISO), J2.3 (MISO), J3.3 (MISO), J4.3 (MISO), X1.4
MB_MOSI: J1.5 (MOSI), J2.5 (MOSI), J3.5 (MOSI), J4.5 (MOSI), X1.3
MB_RESET: X1.11
MB_SCK: J1.4 (SCK), J2.4 (SCK), J3.4 (SCK), J4.4 (SCK), X1.5
MB_SCL: J1.13 (SCL), J2.13 (SCL), J3.13 (SCL), J4.13 (SCL), J5.13 (SCL), J6.13 (SCL), J7.13 (SCL), J8.13 (SCL), U1.14 (SCL), X1.18, X2.18
MB_SDA: J1.14 (SDA), J2.14 (SDA), J3.14 (SDA), J4.14 (SDA), J5.14 (SDA), J6.14 (SDA), J7.14 (SDA), J8.14 (SDA), U1.15 (SDA), X1.17, X2.17
unnamed: JP9.2 (C), U1.1 (A0)
unnamed: JP10.2 (C), U1.2 (A1)
unnamed: JP11.2 (C), U1.3 (A2)
unnamed: U1.4 (P0), U2.1 (I1)
unnamed: U1.5 (P1), U2.2 (I2)
unnamed: U1.6 (P2), U2.3 (I3)
unnamed: U1.7 (P3), U2.4 (I4)
unnamed: U1.9 (P4), U2.5 (I5)
unnamed: U1.10 (P5), U2.6 (I6)
unnamed: U1.11 (P6), U2.7 (I7)
unnamed: U1.12 (P7), U2.8 (I8)
VCC: J1.1 (+5V), J2.1 (+5V), J3.1 (+5V), J4.1 (+5V), J5.1 (+5V), J6.1 (+5V), J7.1 (+5V), J8.1 (+5V), X1.1, X1.2, X2.1, X2.2

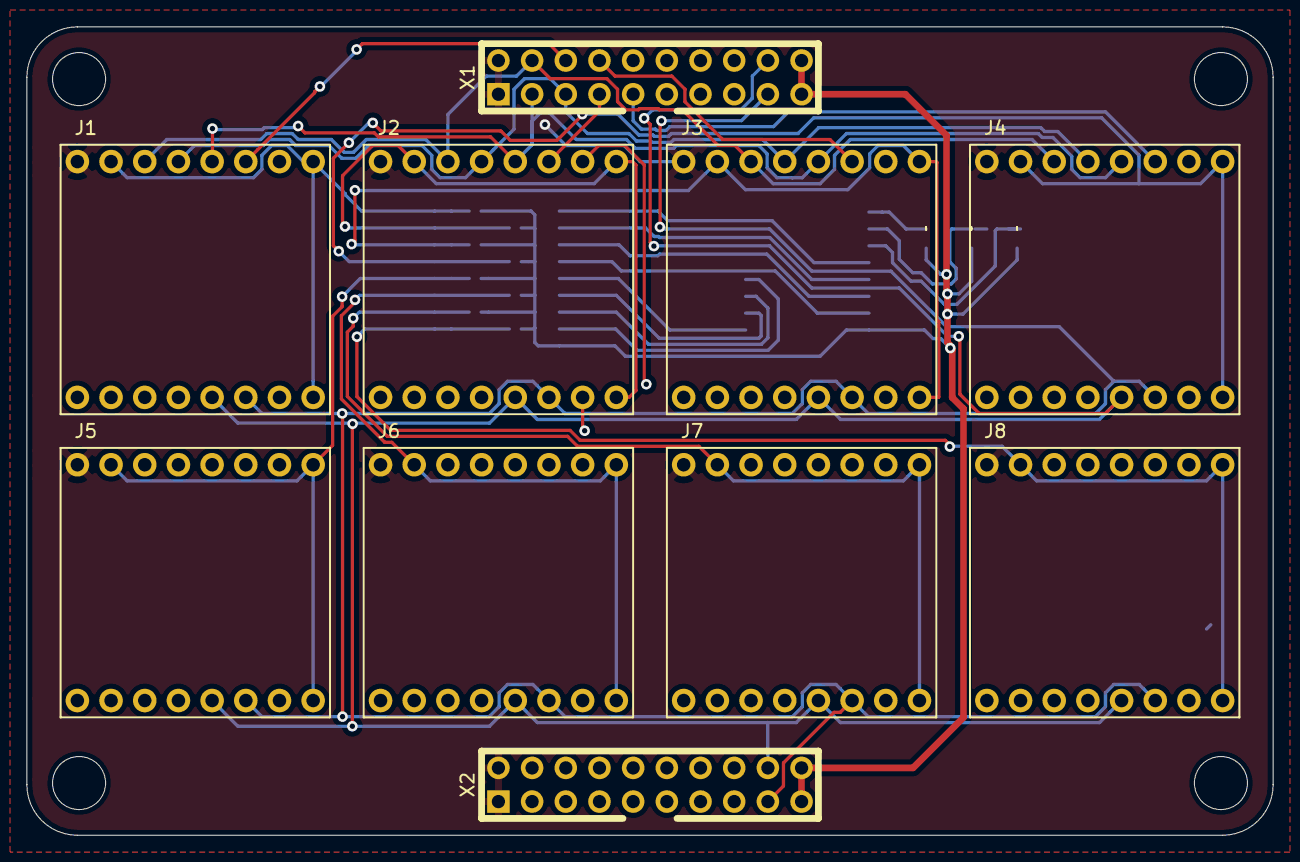
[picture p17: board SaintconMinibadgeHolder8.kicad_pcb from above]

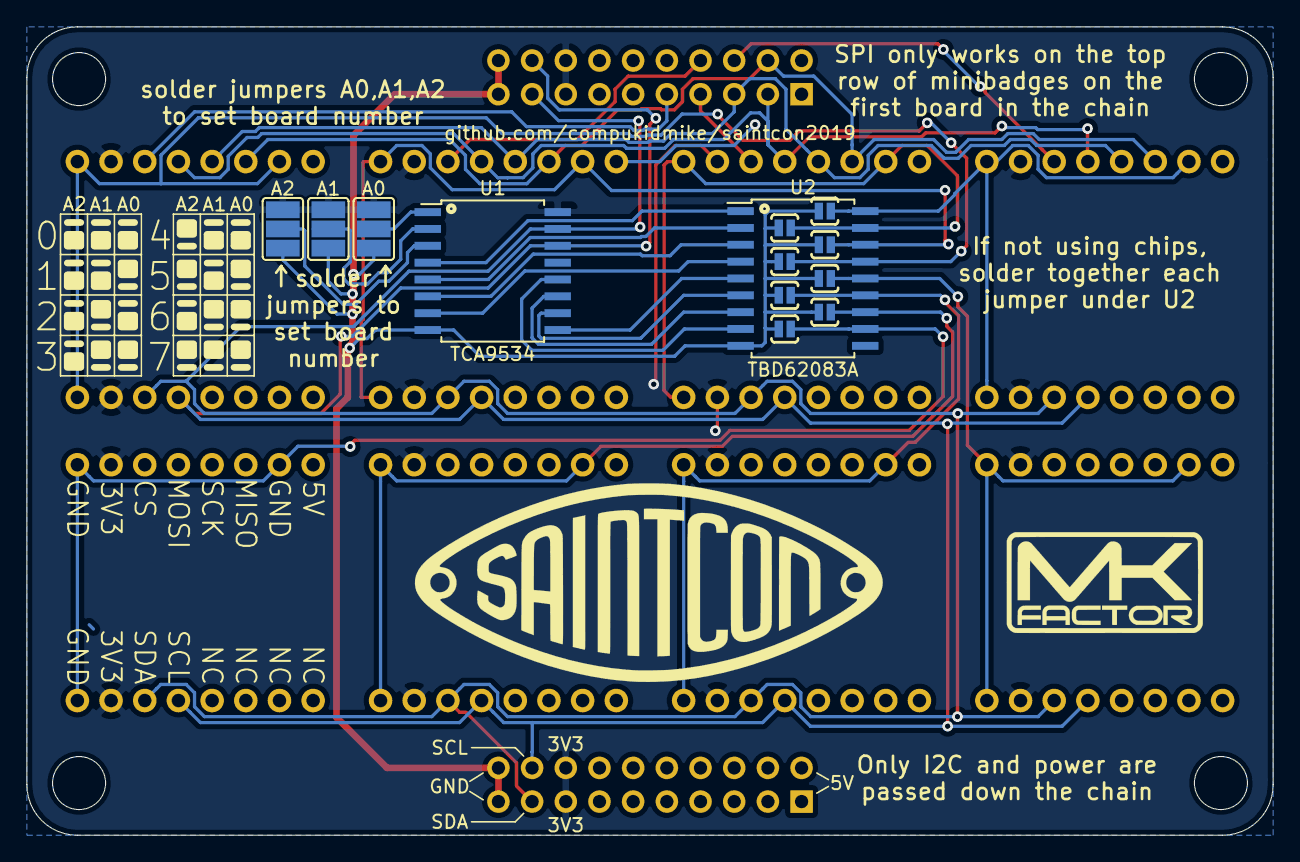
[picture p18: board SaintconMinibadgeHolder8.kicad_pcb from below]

Board: 2 copper layers, 94.0 x 61.0 mm, 24 parts (14 on the bottom side), 31 nets.

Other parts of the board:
Ref**: Val**; drawing

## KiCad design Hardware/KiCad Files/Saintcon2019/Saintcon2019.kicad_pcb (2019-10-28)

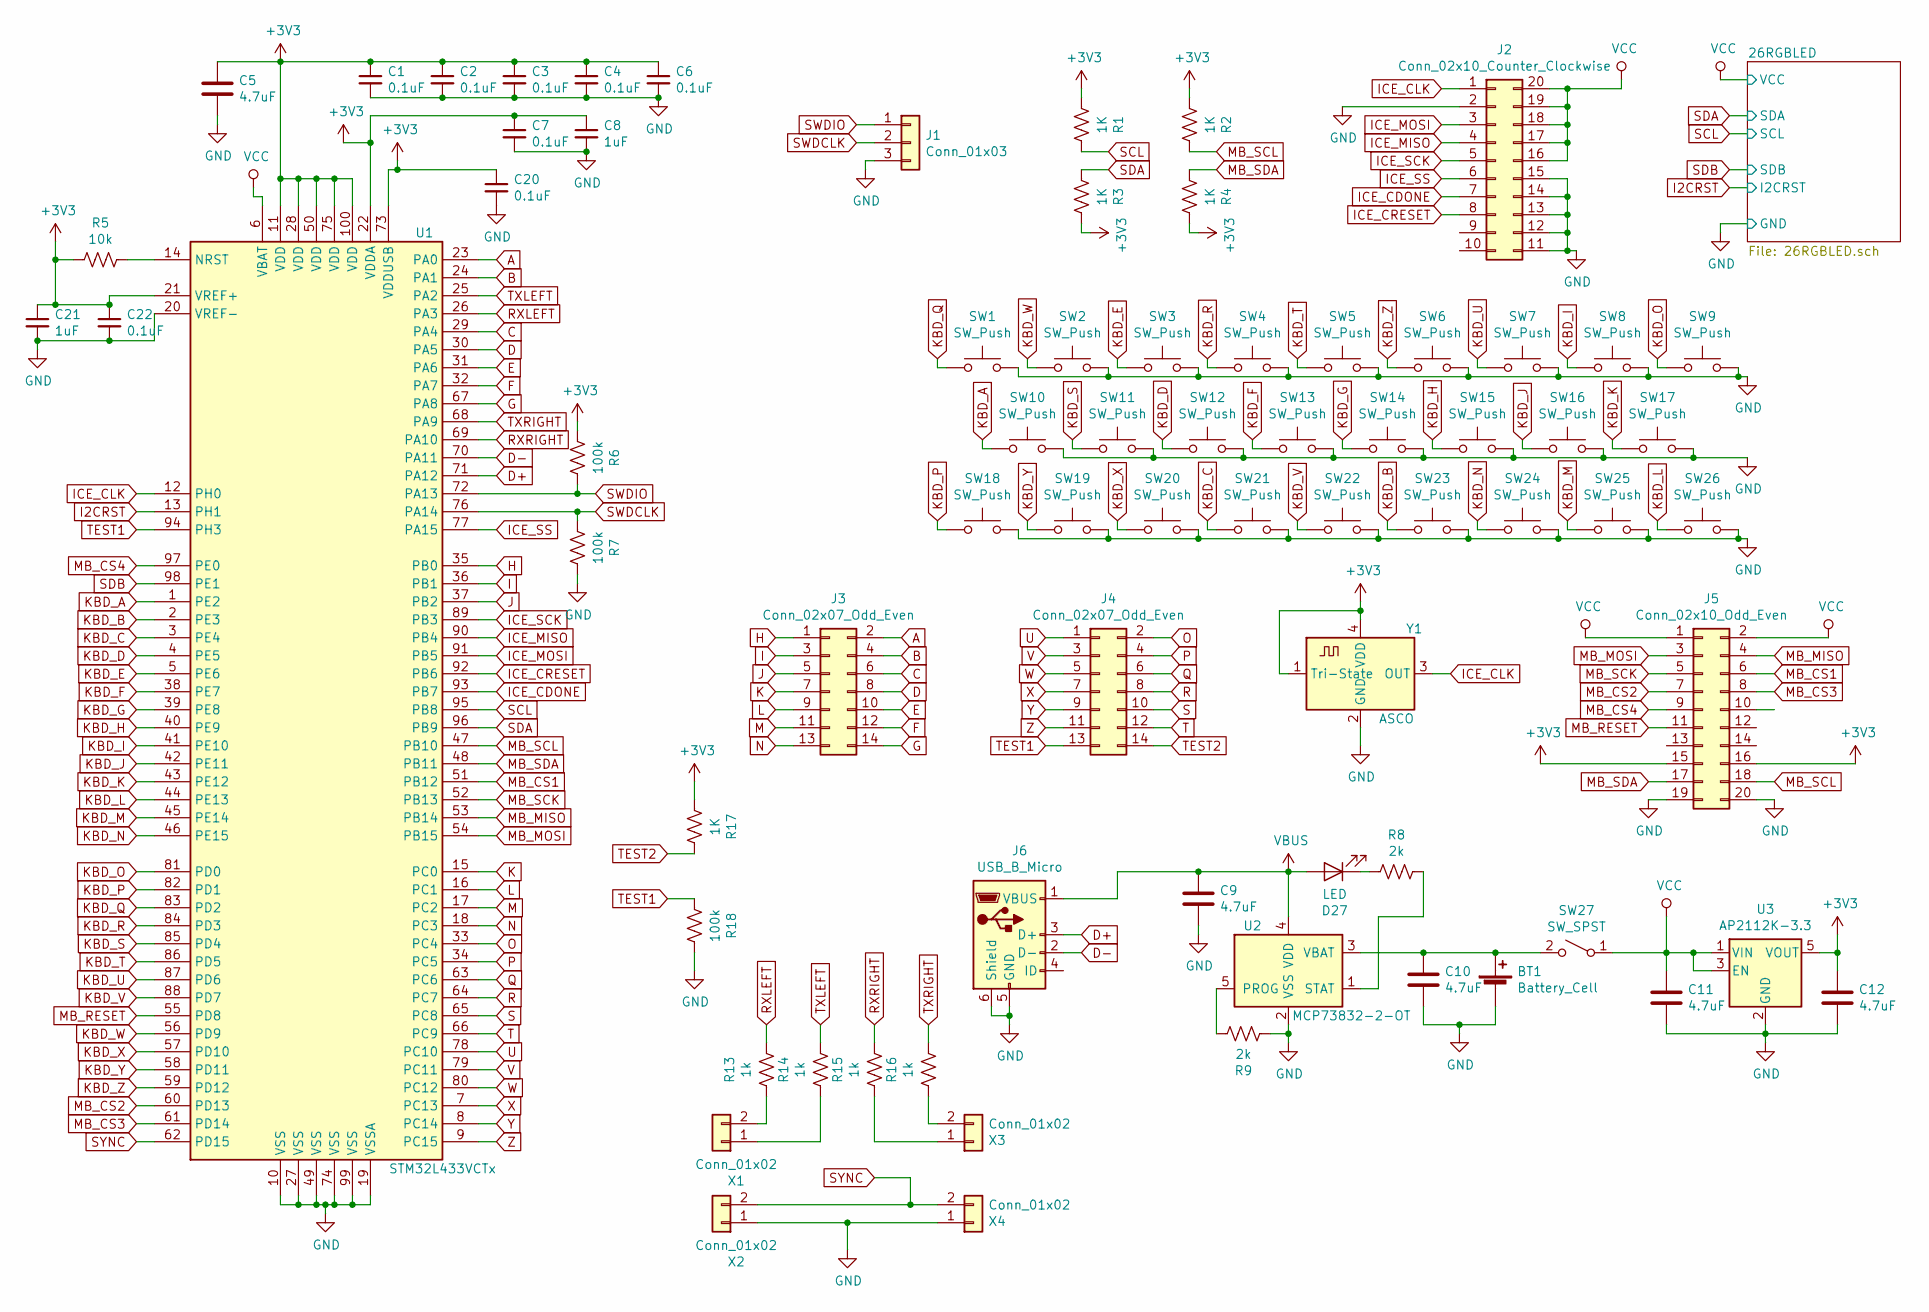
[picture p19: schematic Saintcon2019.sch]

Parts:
BT1: Battery_Cell; JST-2-SMD
C1, C2, C3, C4, C6, C7, C20, C22: 0.1uF; C_0603
C5, C9, C10, C11, C12: 4.7uF; C_0603
C8, C21: 1uF; C_0603
D27: LED; LED_0603
J1: Conn_01x03; 1X03
J2: Conn_02x10_Counter_Clockwise; BergStak_20Pin_0.5mm_Female_5.3mm
J3, J4: Conn_02x07_Odd_Even; Pin_Header_Straight_2x07_Pitch2.54mm
J5: Conn_02x10_Odd_Even; Pin_Header_Straight_2x10_Pitch2.54mm
J6: USB_B_Micro; 10118192-0002LF
R1, R2, R3, R4, R17: 1K; R_0603
R5: 10k; R_0603
R6, R7, R18: 100k; R_0603
R8, R9: 2k; R_0603
R13, R14, R15, R16: 1k; R_0603
SW1, SW2, SW3, SW4, SW5, SW6, SW7, SW8, SW9, SW10, SW11, SW12, SW13, SW14, SW15, SW16, SW17, SW18, SW19, SW20, SW21, SW22, SW23, SW24, SW25, SW26: SW_Push; TACT_6MM_SMD_SQUARE_TOP
SW27: SW_SPST; JS102011SAQN
U1: STM32L433VCTx; LQFP-100_14x14mm_Pitch0.5mm
U2: MCP73832-2-OT; SOT-23-5
U3: AP2112K-3.3; SOT-23-5
X1, X2: Conn_01x02; JST-LEB-2POS-FEMALE
X3, X4: Conn_01x02; JST-LEB-2POS-MALE
Y1: ASCO; ESC-2520MV

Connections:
+3V3: C1.1, C2.1, C3.1, C4.1, C5.1, C6.1, C7.1, C8.1, C12.1, C20.1, C21.1, C22.1, J5.15, J5.16, R1.2, R2.2, R3.1, R4.1, R5.2, R6.2, R17.2, U1.11 (VDD), U1.21 (VREF+), U1.22 (VDDA), U1.28 (VDD), U1.50 (VDD), U1.73 (VDDUSB), U1.75 (VDD), U1.100 (VDD), U3.5 (VOUT), Y1.1 (Tri-State), Y1.4 (VDD)
A: J3.2, U1.23 (PA0)
B: J3.4, U1.24 (PA1)
C: J3.6, U1.29 (PA4)
D: J3.8, U1.30 (PA5)
D+: J6.3 (D+), U1.71 (PA12)
D-: J6.2 (D-), U1.70 (PA11)
E: J3.10, U1.31 (PA6)
F: J3.12, U1.32 (PA7)
G: J3.14, U1.67 (PA8)
GND: BT1.2 (-), C1.2, C2.2, C3.2, C4.2, C5.2, C6.2, C7.2, C8.2, C9.2, C10.2, C11.2, C12.2, C20.2, C21.2, C22.2, J1.3, J2.2, J2.11, J2.12, J2.13, J2.14, J2.15, J5.19, J5.20, J6.5 (GND), J6.6 (Shield), R7.1, R9.2, R18.1, SW1.2, SW2.2, SW3.2, SW4.2, SW5.2, SW6.2, SW7.2, SW8.2, SW9.2, SW10.2, SW11.2, SW12.2, SW13.2, SW14.2, SW15.2, SW16.2, SW17.2, SW18.2, SW19.2, SW20.2, SW21.2, SW22.2, SW23.2, SW24.2, SW25.2, SW26.2, U1.10 (VSS), U1.19 (VSSA), U1.20 (VREF-), U1.27 (VSS), U1.49 (VSS), U1.74 (VSS), U1.99 (VSS), U2.2 (VSS), U3.2 (GND), X2.1, X4.1, Y1.2 (GND); also elsewhere on the board
H: J3.1, U1.35 (PB0)
I: J3.3, U1.36 (PB1)
I2CRST: U1.13 (PH1); also elsewhere on the board
ICE_CDONE: J2.7, U1.93 (PB7)
ICE_CLK: J2.1, U1.12 (PH0), Y1.3 (OUT)
ICE_CRESET: J2.8, U1.92 (PB6)
ICE_MISO: J2.4, U1.90 (PB4)
ICE_MOSI: J2.3, U1.91 (PB5)
ICE_SCK: J2.5, U1.89 (PB3)
ICE_SS: J2.6, U1.77 (PA15)
J: J3.5, U1.37 (PB2)
K: J3.7, U1.15 (PC0)
KBD_A: SW10.1, U1.1 (PE2)
KBD_B: SW23.1, U1.2 (PE3)
KBD_C: SW21.1, U1.3 (PE4)
KBD_D: SW12.1, U1.4 (PE5)
KBD_E: SW3.1, U1.5 (PE6)
KBD_F: SW13.1, U1.38 (PE7)
KBD_G: SW14.1, U1.39 (PE8)
KBD_H: SW15.1, U1.40 (PE9)
KBD_I: SW8.1, U1.41 (PE10)
KBD_J: SW16.1, U1.42 (PE11)
KBD_K: SW17.1, U1.43 (PE12)
KBD_L: SW26.1, U1.44 (PE13)
KBD_M: SW25.1, U1.45 (PE14)
KBD_N: SW24.1, U1.46 (PE15)
KBD_O: SW9.1, U1.81 (PD0)
KBD_P: SW18.1, U1.82 (PD1)
KBD_Q: SW1.1, U1.83 (PD2)
KBD_R: SW4.1, U1.84 (PD3)
KBD_S: SW11.1, U1.85 (PD4)
KBD_T: SW5.1, U1.86 (PD5)
KBD_U: SW7.1, U1.87 (PD6)
KBD_V: SW22.1, U1.88 (PD7)
KBD_W: SW2.1, U1.56 (PD9)
KBD_X: SW20.1, U1.57 (PD10)
KBD_Y: SW19.1, U1.58 (PD11)
KBD_Z: SW6.1, U1.59 (PD12)
L: J3.9, U1.16 (PC1)
M: J3.11, U1.17 (PC2)
MB_CS1: J5.6, U1.51 (PB12)
MB_CS2: J5.7, U1.60 (PD13)
MB_CS3: J5.8, U1.61 (PD14)
MB_CS4: J5.9, U1.97 (PE0)
MB_MISO: J5.4, U1.53 (PB14)
MB_MOSI: J5.3, U1.54 (PB15)
MB_RESET: J5.11, U1.55 (PD8)
MB_SCK: J5.5, U1.52 (PB13)
MB_SCL: J5.18, R2.1, U1.47 (PB10)
MB_SDA: J5.17, R4.2, U1.48 (PB11)
N: J3.13, U1.18 (PC3)
unnamed: BT1.1 (+), C10.1, SW27.2 (B), U2.3 (VBAT)
unnamed: D27.1 (K), R8.2
unnamed: R5.1, U1.14 (NRST)
unnamed: R8.1, U2.1 (STAT)
unnamed: R9.1, U2.5 (PROG)
unnamed: R13.2, X1.2
unnamed: R14.2, X1.1
unnamed: R15.2, X3.1
unnamed: R16.2, X3.2
O: J4.2, U1.33 (PC4)
P: J4.4, U1.34 (PC5)
Q: J4.6, U1.63 (PC6)
R: J4.8, U1.64 (PC7)
RXLEFT: R13.1, U1.26 (PA3)
RXRIGHT: R15.1, U1.69 (PA10)
S: J4.10, U1.65 (PC8)
SCL: R1.1, U1.95 (PB8); also elsewhere on the board
SDA: R3.2, U1.96 (PB9); also elsewhere on the board
SDB: U1.98 (PE1); also elsewhere on the board
SWDCLK: J1.2, R7.2, U1.76 (PA14)
SWDIO: J1.1, R6.1, U1.72 (PA13)
SYNC: U1.62 (PD15), X2.2, X4.2
T: J4.12, U1.66 (PC9)
TEST1: J4.13, R18.2, U1.94 (PH3)
TEST2: J4.14, R17.1
TXLEFT: R14.1, U1.25 (PA2)
TXRIGHT: R16.1, U1.68 (PA9)
U: J4.1, U1.78 (PC10)
V: J4.3, U1.79 (PC11)
VBUS: C9.1, D27.2 (A), J6.1 (VBUS), U2.4 (VDD)
VCC: C11.1, J2.16, J2.17, J2.18, J2.19, J2.20, J5.1, J5.2, SW27.1 (A), U1.6 (VBAT), U3.1 (VIN), U3.3 (EN); also elsewhere on the board
W: J4.5, U1.80 (PC12)
X: J4.7, U1.7 (PC13)
Y: J4.9, U1.8 (PC14)
Z: J4.11, U1.9 (PC15)

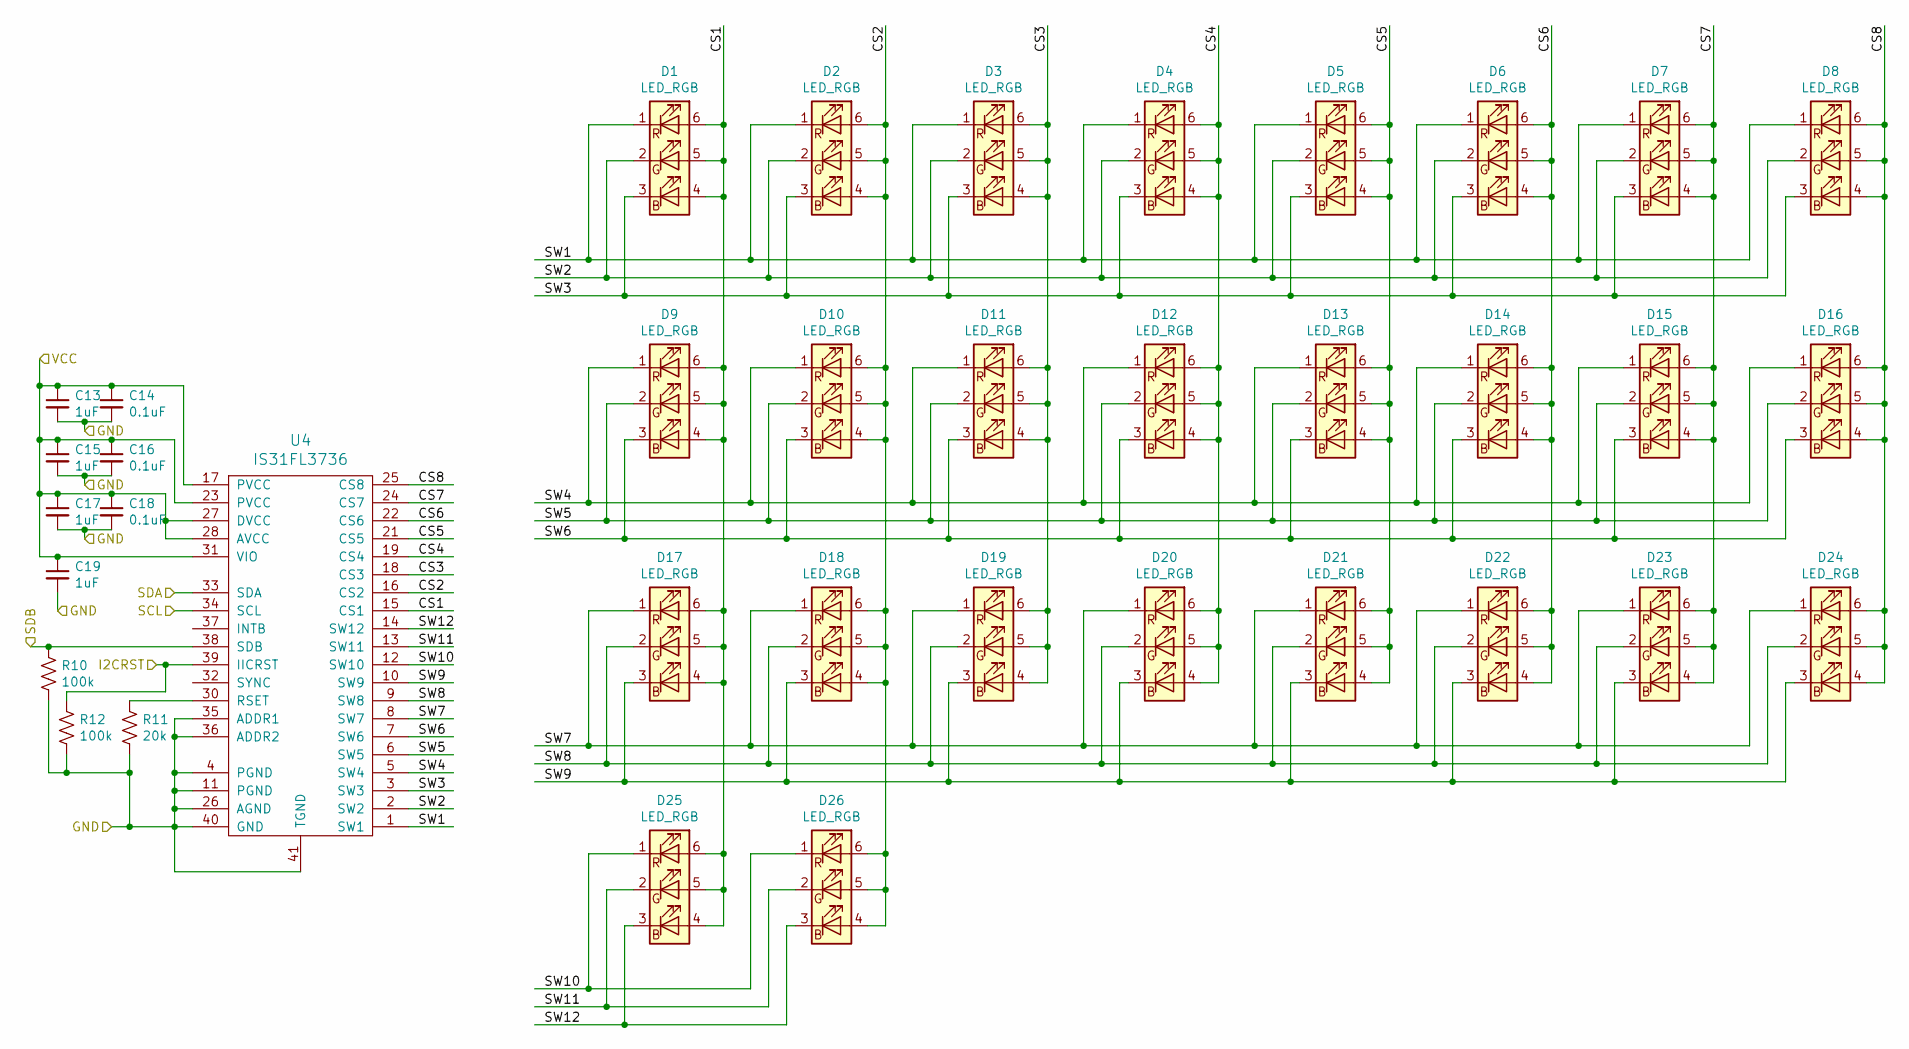
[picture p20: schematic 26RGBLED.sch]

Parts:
C13, C15, C17, C19: 1uF; C_0603
C14, C16, C18: 0.1uF; C_0603
D1, D2, D3, D4, D5, D6, D7, D8, D9, D10, D11, D12, D13, D14, D15, D16, D17, D18, D19, D20, D21, D22, D23, D24, D25, D26: LED_RGB; LED_RGB_5050-6
R10, R12: 100k; R_0603
R11: 20k; R_0603
U4: IS31FL3736; QFN-40-1EP_5x5mm_Pitch0.4mm

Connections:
/26RGBLED/CS1: D1.4 (BA), D1.5 (GA), D1.6 (RA), D9.4 (BA), D9.5 (GA), D9.6 (RA), D17.4 (BA), D17.5 (GA), D17.6 (RA), D25.4 (BA), D25.5 (GA), D25.6 (RA), U4.15 (CS1)
/26RGBLED/CS2: D2.4 (BA), D2.5 (GA), D2.6 (RA), D10.4 (BA), D10.5 (GA), D10.6 (RA), D18.4 (BA), D18.5 (GA), D18.6 (RA), D26.4 (BA), D26.5 (GA), D26.6 (RA), U4.16 (CS2)
/26RGBLED/CS3: D3.4 (BA), D3.5 (GA), D3.6 (RA), D11.4 (BA), D11.5 (GA), D11.6 (RA), D19.4 (BA), D19.5 (GA), D19.6 (RA), U4.18 (CS3)
/26RGBLED/CS4: D4.4 (BA), D4.5 (GA), D4.6 (RA), D12.4 (BA), D12.5 (GA), D12.6 (RA), D20.4 (BA), D20.5 (GA), D20.6 (RA), U4.19 (CS4)
/26RGBLED/CS5: D5.4 (BA), D5.5 (GA), D5.6 (RA), D13.4 (BA), D13.5 (GA), D13.6 (RA), D21.4 (BA), D21.5 (GA), D21.6 (RA), U4.21 (CS5)
/26RGBLED/CS6: D6.4 (BA), D6.5 (GA), D6.6 (RA), D14.4 (BA), D14.5 (GA), D14.6 (RA), D22.4 (BA), D22.5 (GA), D22.6 (RA), U4.22 (CS6)
/26RGBLED/CS7: D7.4 (BA), D7.5 (GA), D7.6 (RA), D15.4 (BA), D15.5 (GA), D15.6 (RA), D23.4 (BA), D23.5 (GA), D23.6 (RA), U4.24 (CS7)
/26RGBLED/CS8: D8.4 (BA), D8.5 (GA), D8.6 (RA), D16.4 (BA), D16.5 (GA), D16.6 (RA), D24.4 (BA), D24.5 (GA), D24.6 (RA), U4.25 (CS8)
/26RGBLED/SW1: D1.1 (RK), D2.1 (RK), D3.1 (RK), D4.1 (RK), D5.1 (RK), D6.1 (RK), D7.1 (RK), D8.1 (RK), U4.1 (SW1)
/26RGBLED/SW2: D1.2 (GK), D2.2 (GK), D3.2 (GK), D4.2 (GK), D5.2 (GK), D6.2 (GK), D7.2 (GK), D8.2 (GK), U4.2 (SW2)
/26RGBLED/SW3: D1.3 (BK), D2.3 (BK), D3.3 (BK), D4.3 (BK), D5.3 (BK), D6.3 (BK), D7.3 (BK), D8.3 (BK), U4.3 (SW3)
/26RGBLED/SW4: D9.1 (RK), D10.1 (RK), D11.1 (RK), D12.1 (RK), D13.1 (RK), D14.1 (RK), D15.1 (RK), D16.1 (RK), U4.5 (SW4)
/26RGBLED/SW5: D9.2 (GK), D10.2 (GK), D11.2 (GK), D12.2 (GK), D13.2 (GK), D14.2 (GK), D15.2 (GK), D16.2 (GK), U4.6 (SW5)
/26RGBLED/SW6: D9.3 (BK), D10.3 (BK), D11.3 (BK), D12.3 (BK), D13.3 (BK), D14.3 (BK), D15.3 (BK), D16.3 (BK), U4.7 (SW6)
/26RGBLED/SW7: D17.1 (RK), D18.1 (RK), D19.1 (RK), D20.1 (RK), D21.1 (RK), D22.1 (RK), D23.1 (RK), D24.1 (RK), U4.8 (SW7)
/26RGBLED/SW8: D17.2 (GK), D18.2 (GK), D19.2 (GK), D20.2 (GK), D21.2 (GK), D22.2 (GK), D23.2 (GK), D24.2 (GK), U4.9 (SW8)
/26RGBLED/SW9: D17.3 (BK), D18.3 (BK), D19.3 (BK), D20.3 (BK), D21.3 (BK), D22.3 (BK), D23.3 (BK), D24.3 (BK), U4.10 (SW9)
/26RGBLED/SW10: D25.1 (RK), D26.1 (RK), U4.12 (SW10)
/26RGBLED/SW11: D25.2 (GK), D26.2 (GK), U4.13 (SW11)
/26RGBLED/SW12: D25.3 (BK), D26.3 (BK), U4.14 (SW12)
GND: C13.2, C14.2, C15.2, C16.2, C17.2, C18.2, C19.2, R10.2, R11.2, R12.2, U4.4 (PGND), U4.11 (PGND), U4.26 (AGND), U4.35 (ADDR1), U4.36 (ADDR2), U4.40 (GND), U4.41 (TGND); also elsewhere on the board
I2CRST: R12.1, U4.39 (IICRST); also elsewhere on the board
unnamed: R11.1, U4.30 (RSET)
SCL: U4.34 (SCL); also elsewhere on the board
SDA: U4.33 (SDA); also elsewhere on the board
SDB: R10.1, U4.38 (SDB); also elsewhere on the board
VCC: C13.1, C14.1, C15.1, C16.1, C17.1, C18.1, C19.1, U4.17 (PVCC), U4.23 (PVCC), U4.27 (DVCC), U4.28 (AVCC), U4.31 (VIO); also elsewhere on the board

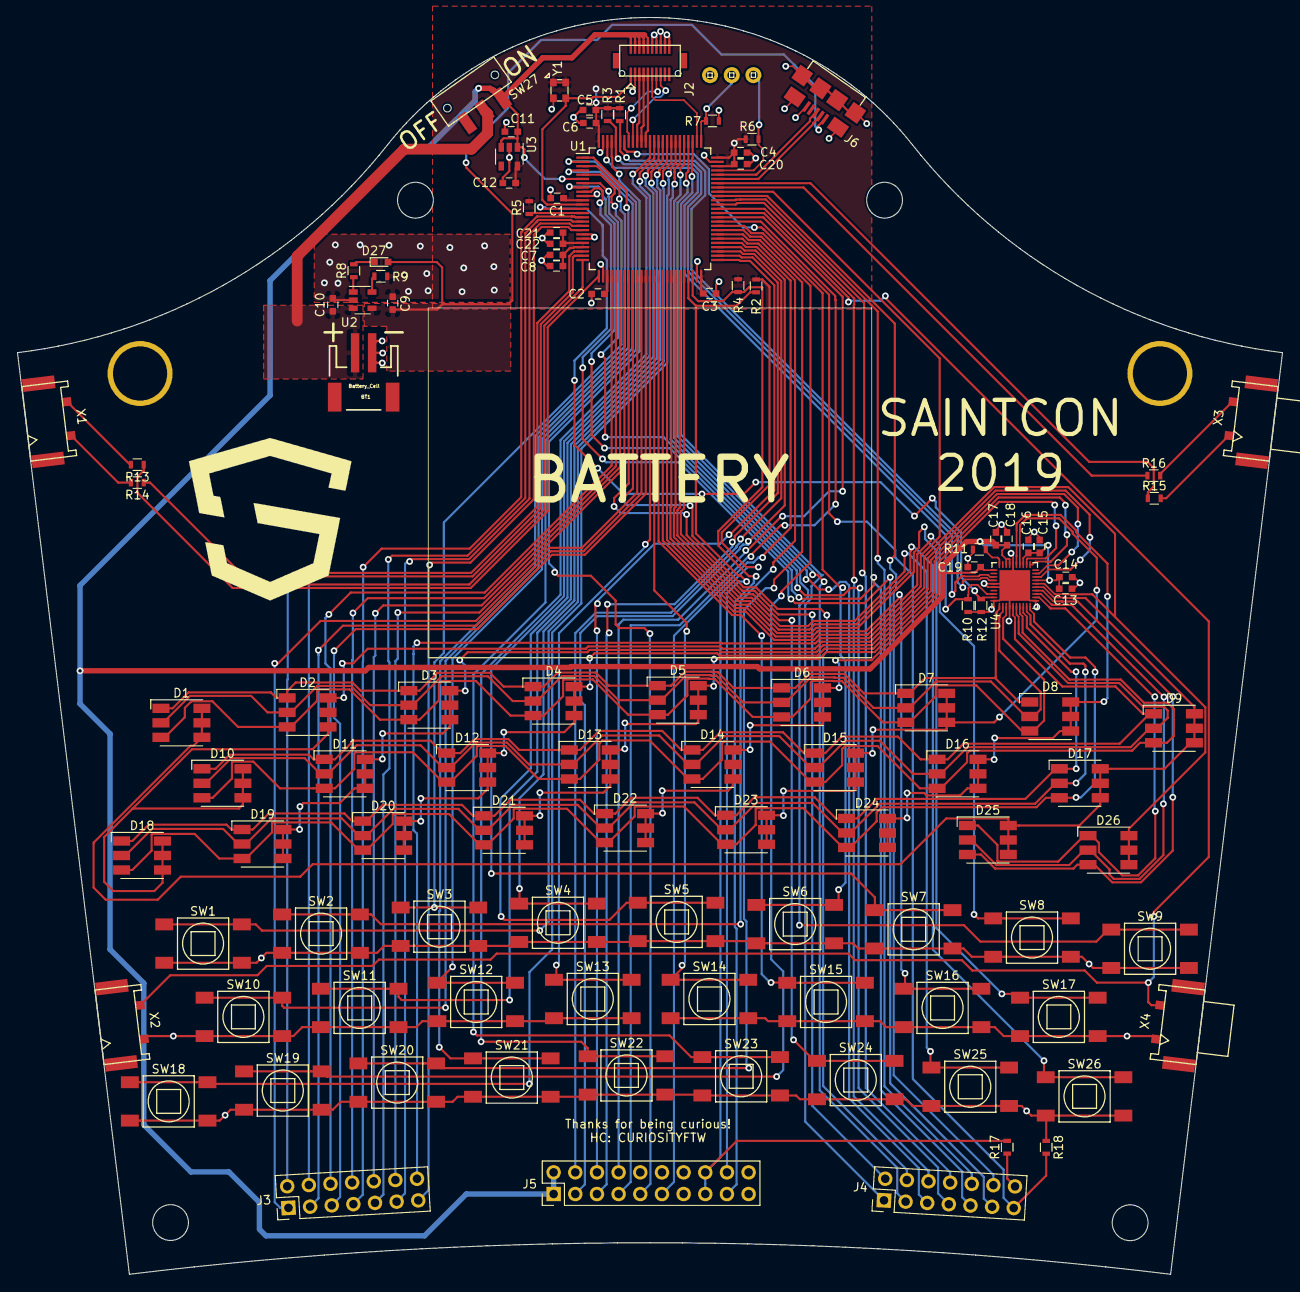
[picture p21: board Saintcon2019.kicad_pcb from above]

Board: 2 copper layers, 148.3 x 147.3 mm, 112 parts (1 on the bottom side), 118 nets.

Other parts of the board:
Back: Val**; Saintcon2019BaseBoardArtwork
Ref**: Val**; Saintcon2019TopBoardArtwork2

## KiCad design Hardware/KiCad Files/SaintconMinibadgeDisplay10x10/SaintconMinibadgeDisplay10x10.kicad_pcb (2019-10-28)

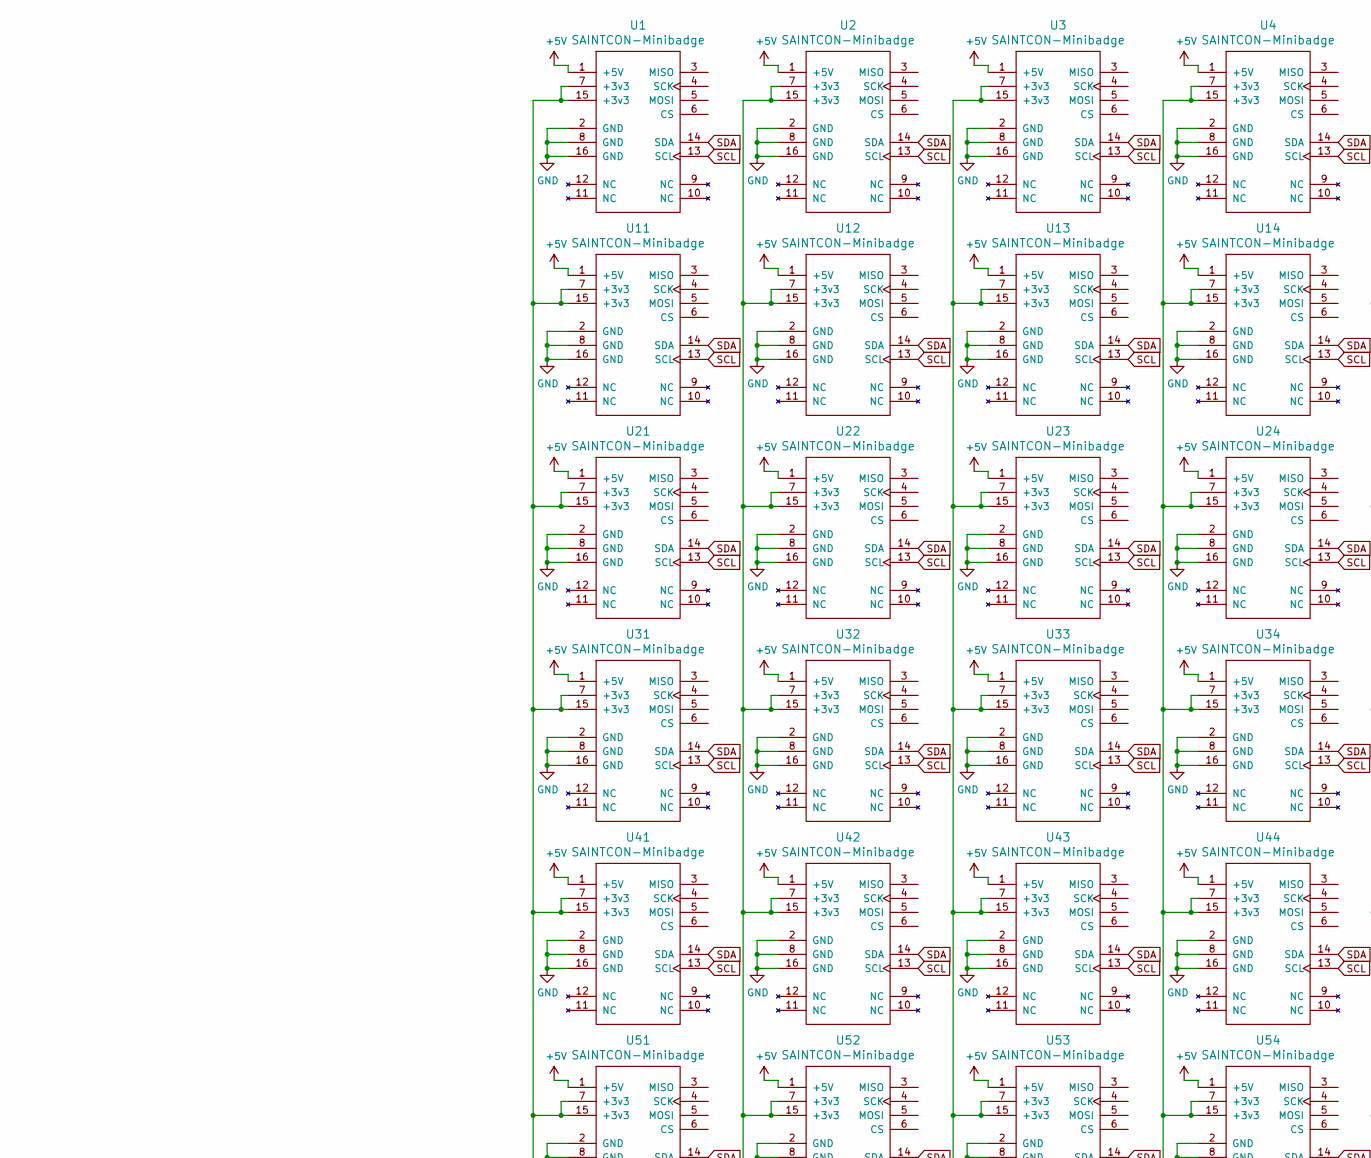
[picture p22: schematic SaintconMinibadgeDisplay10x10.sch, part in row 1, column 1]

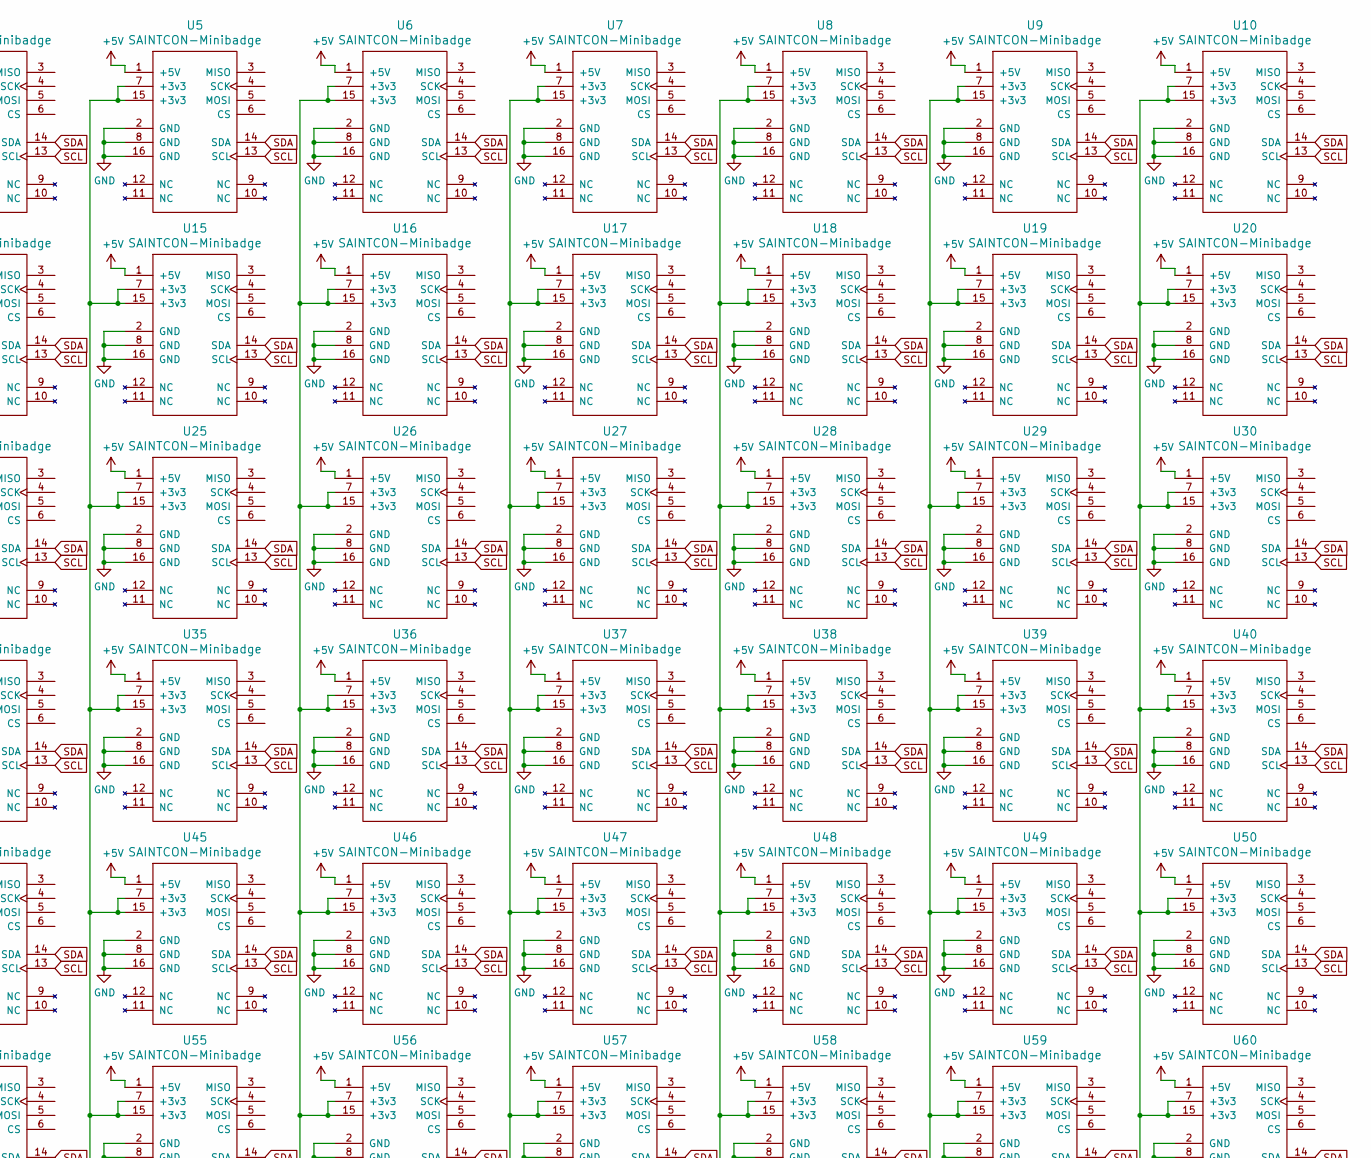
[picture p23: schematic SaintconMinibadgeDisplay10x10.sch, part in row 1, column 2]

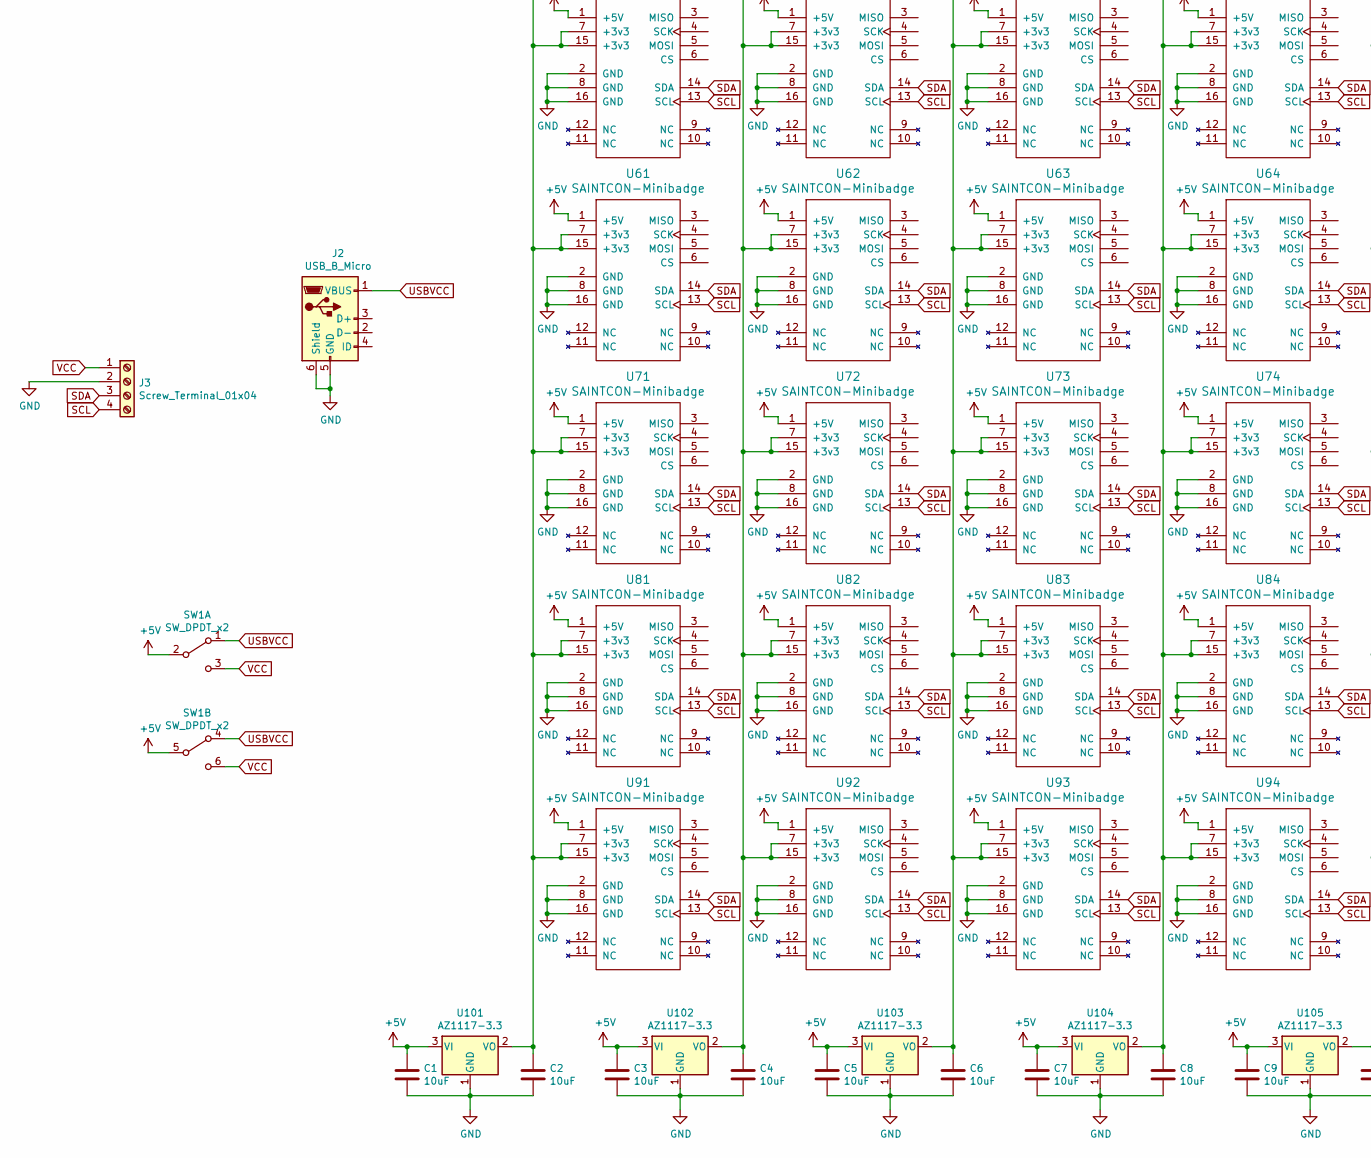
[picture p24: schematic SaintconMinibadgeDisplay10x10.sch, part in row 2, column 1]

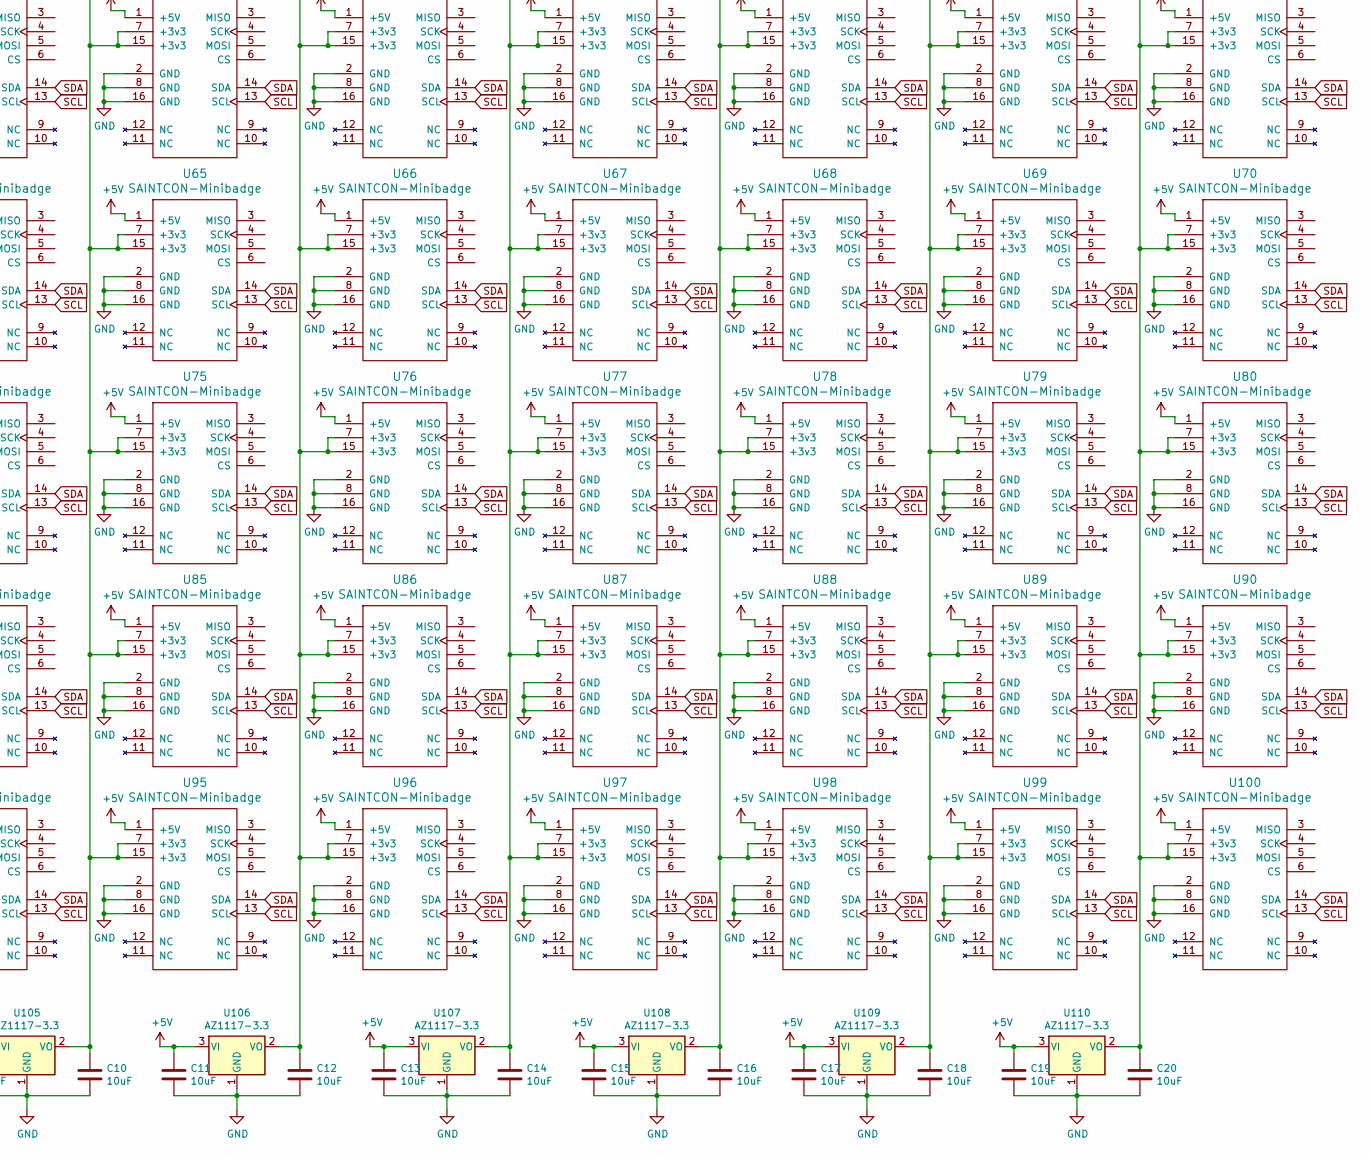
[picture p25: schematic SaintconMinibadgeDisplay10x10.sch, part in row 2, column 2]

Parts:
C1, C2, C3, C4, C5, C6, C7, C8, C9, C10, C11, C12, C13, C14, C15, C16, C17, C18, C19, C20: 10uF; C_0805_HandSoldering
J2: USB_B_Micro; 10118192-0002LF
J3: Screw_Terminal_01x04; SCREWTERMINAL-3.5MM-4
SW1: SW_DPDT_x2; MFS201N-9-Z
U1, U2, U3, U4, U5, U6, U7, U8, U9, U10, U11, U12, U13, U14, U15, U16, U17, U18, U19, U20, U21, U22, U23, U24, U25, U26, U27, U28, U29, U30, U31, U32, U33, U34, U35, U36, U37, U38, U39, U40, U41, U42, U43, U44, U45, U46, U47, U48, U49, U50, U51, U52, U53, U54, U55, U56, U57, U58, U59, U60, U61, U62, U63, U64, U65, U66, U67, U68, U69, U70, U71, U72, U73, U74, U75, U76, U77, U78, U79, U80, U81, U82, U83, U84, U85, U86, U87, U88, U89, U90, U91, U92, U93, U94, U95, U96, U97, U98, U99, U100: SAINTCON-Minibadge; SAINTCON-Minibadge-Shiny
U101, U102, U103, U104, U105, U106, U107, U108, U109, U110: AZ1117-3.3; SOT-223-3_TabPin2

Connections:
+5V: C1.1, C3.1, C5.1, C7.1, C9.1, C11.1, C13.1, C15.1, C17.1, C19.1, SW1.2 (B), SW1.5 (B), U1.1 (+5V), U2.1 (+5V), U3.1 (+5V), U4.1 (+5V), U5.1 (+5V), U6.1 (+5V), U7.1 (+5V), U8.1 (+5V), U9.1 (+5V), U10.1 (+5V), U11.1 (+5V), U12.1 (+5V), U13.1 (+5V), U14.1 (+5V), U15.1 (+5V), U16.1 (+5V), U17.1 (+5V), U18.1 (+5V), U19.1 (+5V), U20.1 (+5V), U21.1 (+5V), U22.1 (+5V), U23.1 (+5V), U24.1 (+5V), U25.1 (+5V), U26.1 (+5V), U27.1 (+5V), U28.1 (+5V), U29.1 (+5V), U30.1 (+5V), U31.1 (+5V), U32.1 (+5V), U33.1 (+5V), U34.1 (+5V), U35.1 (+5V), U36.1 (+5V), U37.1 (+5V), U38.1 (+5V), U39.1 (+5V), U40.1 (+5V), U41.1 (+5V), U42.1 (+5V), U43.1 (+5V), U44.1 (+5V), U45.1 (+5V), U46.1 (+5V), U47.1 (+5V), U48.1 (+5V), U49.1 (+5V), U50.1 (+5V), U51.1 (+5V), U52.1 (+5V), U53.1 (+5V), U54.1 (+5V), U55.1 (+5V), U56.1 (+5V), U57.1 (+5V), U58.1 (+5V), U59.1 (+5V), U60.1 (+5V), U61.1 (+5V), U62.1 (+5V), U63.1 (+5V), U64.1 (+5V), U65.1 (+5V), U66.1 (+5V), U67.1 (+5V), U68.1 (+5V), U69.1 (+5V), U70.1 (+5V), U71.1 (+5V), U72.1 (+5V), U73.1 (+5V), U74.1 (+5V), U75.1 (+5V), U76.1 (+5V), U77.1 (+5V), U78.1 (+5V), U79.1 (+5V), U80.1 (+5V), U81.1 (+5V), U82.1 (+5V), U83.1 (+5V), U84.1 (+5V), U85.1 (+5V), U86.1 (+5V), U87.1 (+5V), U88.1 (+5V), U89.1 (+5V), U90.1 (+5V), U91.1 (+5V), U92.1 (+5V), U93.1 (+5V), U94.1 (+5V), U95.1 (+5V), U96.1 (+5V), U97.1 (+5V), U98.1 (+5V), U99.1 (+5V), U100.1 (+5V), U101.3 (VI), U102.3 (VI), U103.3 (VI), U104.3 (VI), U105.3 (VI), U106.3 (VI), U107.3 (VI), U108.3 (VI), U109.3 (VI), U110.3 (VI)
GND: C1.2, C2.2, C3.2, C4.2, C5.2, C6.2, C7.2, C8.2, C9.2, C10.2, C11.2, C12.2, C13.2, C14.2, C15.2, C16.2, C17.2, C18.2, C19.2, C20.2, J2.5 (GND), J2.6 (Shield), J3.2, U1.2 (GND), U1.8 (GND), U1.16 (GND), U2.2 (GND), U2.8 (GND), U2.16 (GND), U3.2 (GND), U3.8 (GND), U3.16 (GND), U4.2 (GND), U4.8 (GND), U4.16 (GND), U5.2 (GND), U5.8 (GND), U5.16 (GND), U6.2 (GND), U6.8 (GND), U6.16 (GND), U7.2 (GND), U7.8 (GND), U7.16 (GND), U8.2 (GND), U8.8 (GND), U8.16 (GND), U9.2 (GND), U9.8 (GND), U9.16 (GND), U10.2 (GND), U10.8 (GND), U10.16 (GND), U11.2 (GND), U11.8 (GND), U11.16 (GND), U12.2 (GND), U12.8 (GND), U12.16 (GND), U13.2 (GND), U13.8 (GND), U13.16 (GND), U14.2 (GND), U14.8 (GND), U14.16 (GND), U15.2 (GND), U15.8 (GND), U15.16 (GND), U16.2 (GND), U16.8 (GND), U16.16 (GND), U17.2 (GND), U17.8 (GND), U17.16 (GND), U18.2 (GND), U18.8 (GND), U18.16 (GND), U19.2 (GND), U19.8 (GND), U19.16 (GND), U20.2 (GND), U20.8 (GND), U20.16 (GND), U21.2 (GND), U21.8 (GND), U21.16 (GND), U22.2 (GND), U22.8 (GND), U22.16 (GND), U23.2 (GND), U23.8 (GND), U23.16 (GND), U24.2 (GND), U24.8 (GND), U24.16 (GND), U25.2 (GND), U25.8 (GND), U25.16 (GND), U26.2 (GND), U26.8 (GND), U26.16 (GND), U27.2 (GND), U27.8 (GND), U27.16 (GND), U28.2 (GND), U28.8 (GND), U28.16 (GND), U29.2 (GND), U29.8 (GND), U29.16 (GND), U30.2 (GND), U30.8 (GND), U30.16 (GND), U31.2 (GND), U31.8 (GND), U31.16 (GND), U32.2 (GND), U32.8 (GND), U32.16 (GND), U33.2 (GND), U33.8 (GND), U33.16 (GND), U34.2 (GND), U34.8 (GND), U34.16 (GND), U35.2 (GND), U35.8 (GND), U35.16 (GND), U36.2 (GND), U36.8 (GND), U36.16 (GND), U37.2 (GND), U37.8 (GND), U37.16 (GND), U38.2 (GND), U38.8 (GND), U38.16 (GND), U39.2 (GND), U39.8 (GND), U39.16 (GND), U40.2 (GND), U40.8 (GND), U40.16 (GND), U41.2 (GND), U41.8 (GND), U41.16 (GND), U42.2 (GND), U42.8 (GND), U42.16 (GND), U43.2 (GND), U43.8 (GND), U43.16 (GND), U44.2 (GND), U44.8 (GND), U44.16 (GND), U45.2 (GND), U45.8 (GND), U45.16 (GND), U46.2 (GND), U46.8 (GND), U46.16 (GND), U47.2 (GND), U47.8 (GND), U47.16 (GND), U48.2 (GND), U48.8 (GND), U48.16 (GND), U49.2 (GND), U49.8 (GND), U49.16 (GND), U50.2 (GND), U50.8 (GND), U50.16 (GND), U51.2 (GND), U51.8 (GND), U51.16 (GND), U52.2 (GND), U52.8 (GND), U52.16 (GND), U53.2 (GND), U53.8 (GND), U53.16 (GND), U54.2 (GND), U54.8 (GND), U54.16 (GND), U55.2 (GND), U55.8 (GND), U55.16 (GND), U56.2 (GND), U56.8 (GND), U56.16 (GND), U57.2 (GND), U57.8 (GND), U57.16 (GND), U58.2 (GND), U58.8 (GND), U58.16 (GND), U59.2 (GND), U59.8 (GND), U59.16 (GND), U60.2 (GND), U60.8 (GND), U60.16 (GND), U61.2 (GND), U61.8 (GND), U61.16 (GND), U62.2 (GND), U62.8 (GND), U62.16 (GND), U63.2 (GND), U63.8 (GND), U63.16 (GND), U64.2 (GND), U64.8 (GND), U64.16 (GND), U65.2 (GND), U65.8 (GND), U65.16 (GND), U66.2 (GND), U66.8 (GND), U66.16 (GND), U67.2 (GND), U67.8 (GND), U67.16 (GND), U68.2 (GND), U68.8 (GND), U68.16 (GND), U69.2 (GND), U69.8 (GND), U69.16 (GND), U70.2 (GND), U70.8 (GND), U70.16 (GND), U71.2 (GND), U71.8 (GND), U71.16 (GND), U72.2 (GND), U72.8 (GND), U72.16 (GND), U73.2 (GND), U73.8 (GND), U73.16 (GND), U74.2 (GND), U74.8 (GND), U74.16 (GND), U75.2 (GND), U75.8 (GND), U75.16 (GND), U76.2 (GND), U76.8 (GND), U76.16 (GND), U77.2 (GND), U77.8 (GND), U77.16 (GND), U78.2 (GND), U78.8 (GND), U78.16 (GND), U79.2 (GND), U79.8 (GND), U79.16 (GND), U80.2 (GND), U80.8 (GND), U80.16 (GND), U81.2 (GND), U81.8 (GND), U81.16 (GND), U82.2 (GND), U82.8 (GND), U82.16 (GND), U83.2 (GND), U83.8 (GND), U83.16 (GND), U84.2 (GND), U84.8 (GND), U84.16 (GND), U85.2 (GND), U85.8 (GND), U85.16 (GND), U86.2 (GND), U86.8 (GND), U86.16 (GND), U87.2 (GND), U87.8 (GND), U87.16 (GND), U88.2 (GND), U88.8 (GND), U88.16 (GND), U89.2 (GND), U89.8 (GND), U89.16 (GND), U90.2 (GND), U90.8 (GND), U90.16 (GND), U91.2 (GND), U91.8 (GND), U91.16 (GND), U92.2 (GND), U92.8 (GND), U92.16 (GND), U93.2 (GND), U93.8 (GND), U93.16 (GND), U94.2 (GND), U94.8 (GND), U94.16 (GND), U95.2 (GND), U95.8 (GND), U95.16 (GND), U96.2 (GND), U96.8 (GND), U96.16 (GND), U97.2 (GND), U97.8 (GND), U97.16 (GND), U98.2 (GND), U98.8 (GND), U98.16 (GND), U99.2 (GND), U99.8 (GND), U99.16 (GND), U100.2 (GND), U100.8 (GND), U100.16 (GND), U101.1 (GND), U102.1 (GND), U103.1 (GND), U104.1 (GND), U105.1 (GND), U106.1 (GND), U107.1 (GND), U108.1 (GND), U109.1 (GND), U110.1 (GND)
unnamed: C2.1, U1.7 (+3v3), U1.15 (+3v3), U11.7 (+3v3), U11.15 (+3v3), U21.7 (+3v3), U21.15 (+3v3), U31.7 (+3v3), U31.15 (+3v3), U41.7 (+3v3), U41.15 (+3v3), U51.7 (+3v3), U51.15 (+3v3), U61.7 (+3v3), U61.15 (+3v3), U71.7 (+3v3), U71.15 (+3v3), U81.7 (+3v3), U81.15 (+3v3), U91.7 (+3v3), U91.15 (+3v3), U101.2 (VO)
unnamed: C4.1, U2.7 (+3v3), U2.15 (+3v3), U12.7 (+3v3), U12.15 (+3v3), U22.7 (+3v3), U22.15 (+3v3), U32.7 (+3v3), U32.15 (+3v3), U42.7 (+3v3), U42.15 (+3v3), U52.7 (+3v3), U52.15 (+3v3), U62.7 (+3v3), U62.15 (+3v3), U72.7 (+3v3), U72.15 (+3v3), U82.7 (+3v3), U82.15 (+3v3), U92.7 (+3v3), U92.15 (+3v3), U102.2 (VO)
unnamed: C6.1, U3.7 (+3v3), U3.15 (+3v3), U13.7 (+3v3), U13.15 (+3v3), U23.7 (+3v3), U23.15 (+3v3), U33.7 (+3v3), U33.15 (+3v3), U43.7 (+3v3), U43.15 (+3v3), U53.7 (+3v3), U53.15 (+3v3), U63.7 (+3v3), U63.15 (+3v3), U73.7 (+3v3), U73.15 (+3v3), U83.7 (+3v3), U83.15 (+3v3), U93.7 (+3v3), U93.15 (+3v3), U103.2 (VO)
unnamed: C8.1, U4.7 (+3v3), U4.15 (+3v3), U14.7 (+3v3), U14.15 (+3v3), U24.7 (+3v3), U24.15 (+3v3), U34.7 (+3v3), U34.15 (+3v3), U44.7 (+3v3), U44.15 (+3v3), U54.7 (+3v3), U54.15 (+3v3), U64.7 (+3v3), U64.15 (+3v3), U74.7 (+3v3), U74.15 (+3v3), U84.7 (+3v3), U84.15 (+3v3), U94.7 (+3v3), U94.15 (+3v3), U104.2 (VO)
unnamed: C10.1, U5.7 (+3v3), U5.15 (+3v3), U15.7 (+3v3), U15.15 (+3v3), U25.7 (+3v3), U25.15 (+3v3), U35.7 (+3v3), U35.15 (+3v3), U45.7 (+3v3), U45.15 (+3v3), U55.7 (+3v3), U55.15 (+3v3), U65.7 (+3v3), U65.15 (+3v3), U75.7 (+3v3), U75.15 (+3v3), U85.7 (+3v3), U85.15 (+3v3), U95.7 (+3v3), U95.15 (+3v3), U105.2 (VO)
unnamed: C12.1, U6.7 (+3v3), U6.15 (+3v3), U16.7 (+3v3), U16.15 (+3v3), U26.7 (+3v3), U26.15 (+3v3), U36.7 (+3v3), U36.15 (+3v3), U46.7 (+3v3), U46.15 (+3v3), U56.7 (+3v3), U56.15 (+3v3), U66.7 (+3v3), U66.15 (+3v3), U76.7 (+3v3), U76.15 (+3v3), U86.7 (+3v3), U86.15 (+3v3), U96.7 (+3v3), U96.15 (+3v3), U106.2 (VO)
unnamed: C14.1, U7.7 (+3v3), U7.15 (+3v3), U17.7 (+3v3), U17.15 (+3v3), U27.7 (+3v3), U27.15 (+3v3), U37.7 (+3v3), U37.15 (+3v3), U47.7 (+3v3), U47.15 (+3v3), U57.7 (+3v3), U57.15 (+3v3), U67.7 (+3v3), U67.15 (+3v3), U77.7 (+3v3), U77.15 (+3v3), U87.7 (+3v3), U87.15 (+3v3), U97.7 (+3v3), U97.15 (+3v3), U107.2 (VO)
unnamed: C16.1, U8.7 (+3v3), U8.15 (+3v3), U18.7 (+3v3), U18.15 (+3v3), U28.7 (+3v3), U28.15 (+3v3), U38.7 (+3v3), U38.15 (+3v3), U48.7 (+3v3), U48.15 (+3v3), U58.7 (+3v3), U58.15 (+3v3), U68.7 (+3v3), U68.15 (+3v3), U78.7 (+3v3), U78.15 (+3v3), U88.7 (+3v3), U88.15 (+3v3), U98.7 (+3v3), U98.15 (+3v3), U108.2 (VO)
unnamed: C18.1, U9.7 (+3v3), U9.15 (+3v3), U19.7 (+3v3), U19.15 (+3v3), U29.7 (+3v3), U29.15 (+3v3), U39.7 (+3v3), U39.15 (+3v3), U49.7 (+3v3), U49.15 (+3v3), U59.7 (+3v3), U59.15 (+3v3), U69.7 (+3v3), U69.15 (+3v3), U79.7 (+3v3), U79.15 (+3v3), U89.7 (+3v3), U89.15 (+3v3), U99.7 (+3v3), U99.15 (+3v3), U109.2 (VO)
unnamed: C20.1, U10.7 (+3v3), U10.15 (+3v3), U20.7 (+3v3), U20.15 (+3v3), U30.7 (+3v3), U30.15 (+3v3), U40.7 (+3v3), U40.15 (+3v3), U50.7 (+3v3), U50.15 (+3v3), U60.7 (+3v3), U60.15 (+3v3), U70.7 (+3v3), U70.15 (+3v3), U80.7 (+3v3), U80.15 (+3v3), U90.7 (+3v3), U90.15 (+3v3), U100.7 (+3v3), U100.15 (+3v3), U110.2 (VO)
SCL: J3.4, U1.13 (SCL), U2.13 (SCL), U3.13 (SCL), U4.13 (SCL), U5.13 (SCL), U6.13 (SCL), U7.13 (SCL), U8.13 (SCL), U9.13 (SCL), U10.13 (SCL), U11.13 (SCL), U12.13 (SCL), U13.13 (SCL), U14.13 (SCL), U15.13 (SCL), U16.13 (SCL), U17.13 (SCL), U18.13 (SCL), U19.13 (SCL), U20.13 (SCL), U21.13 (SCL), U22.13 (SCL), U23.13 (SCL), U24.13 (SCL), U25.13 (SCL), U26.13 (SCL), U27.13 (SCL), U28.13 (SCL), U29.13 (SCL), U30.13 (SCL), U31.13 (SCL), U32.13 (SCL), U33.13 (SCL), U34.13 (SCL), U35.13 (SCL), U36.13 (SCL), U37.13 (SCL), U38.13 (SCL), U39.13 (SCL), U40.13 (SCL), U41.13 (SCL), U42.13 (SCL), U43.13 (SCL), U44.13 (SCL), U45.13 (SCL), U46.13 (SCL), U47.13 (SCL), U48.13 (SCL), U49.13 (SCL), U50.13 (SCL), U51.13 (SCL), U52.13 (SCL), U53.13 (SCL), U54.13 (SCL), U55.13 (SCL), U56.13 (SCL), U57.13 (SCL), U58.13 (SCL), U59.13 (SCL), U60.13 (SCL), U61.13 (SCL), U62.13 (SCL), U63.13 (SCL), U64.13 (SCL), U65.13 (SCL), U66.13 (SCL), U67.13 (SCL), U68.13 (SCL), U69.13 (SCL), U70.13 (SCL), U71.13 (SCL), U72.13 (SCL), U73.13 (SCL), U74.13 (SCL), U75.13 (SCL), U76.13 (SCL), U77.13 (SCL), U78.13 (SCL), U79.13 (SCL), U80.13 (SCL), U81.13 (SCL), U82.13 (SCL), U83.13 (SCL), U84.13 (SCL), U85.13 (SCL), U86.13 (SCL), U87.13 (SCL), U88.13 (SCL), U89.13 (SCL), U90.13 (SCL), U91.13 (SCL), U92.13 (SCL), U93.13 (SCL), U94.13 (SCL), U95.13 (SCL), U96.13 (SCL), U97.13 (SCL), U98.13 (SCL), U99.13 (SCL), U100.13 (SCL)
SDA: J3.3, U1.14 (SDA), U2.14 (SDA), U3.14 (SDA), U4.14 (SDA), U5.14 (SDA), U6.14 (SDA), U7.14 (SDA), U8.14 (SDA), U9.14 (SDA), U10.14 (SDA), U11.14 (SDA), U12.14 (SDA), U13.14 (SDA), U14.14 (SDA), U15.14 (SDA), U16.14 (SDA), U17.14 (SDA), U18.14 (SDA), U19.14 (SDA), U20.14 (SDA), U21.14 (SDA), U22.14 (SDA), U23.14 (SDA), U24.14 (SDA), U25.14 (SDA), U26.14 (SDA), U27.14 (SDA), U28.14 (SDA), U29.14 (SDA), U30.14 (SDA), U31.14 (SDA), U32.14 (SDA), U33.14 (SDA), U34.14 (SDA), U35.14 (SDA), U36.14 (SDA), U37.14 (SDA), U38.14 (SDA), U39.14 (SDA), U40.14 (SDA), U41.14 (SDA), U42.14 (SDA), U43.14 (SDA), U44.14 (SDA), U45.14 (SDA), U46.14 (SDA), U47.14 (SDA), U48.14 (SDA), U49.14 (SDA), U50.14 (SDA), U51.14 (SDA), U52.14 (SDA), U53.14 (SDA), U54.14 (SDA), U55.14 (SDA), U56.14 (SDA), U57.14 (SDA), U58.14 (SDA), U59.14 (SDA), U60.14 (SDA), U61.14 (SDA), U62.14 (SDA), U63.14 (SDA), U64.14 (SDA), U65.14 (SDA), U66.14 (SDA), U67.14 (SDA), U68.14 (SDA), U69.14 (SDA), U70.14 (SDA), U71.14 (SDA), U72.14 (SDA), U73.14 (SDA), U74.14 (SDA), U75.14 (SDA), U76.14 (SDA), U77.14 (SDA), U78.14 (SDA), U79.14 (SDA), U80.14 (SDA), U81.14 (SDA), U82.14 (SDA), U83.14 (SDA), U84.14 (SDA), U85.14 (SDA), U86.14 (SDA), U87.14 (SDA), U88.14 (SDA), U89.14 (SDA), U90.14 (SDA), U91.14 (SDA), U92.14 (SDA), U93.14 (SDA), U94.14 (SDA), U95.14 (SDA), U96.14 (SDA), U97.14 (SDA), U98.14 (SDA), U99.14 (SDA), U100.14 (SDA)
USBVCC: J2.1 (VBUS), SW1.1 (A), SW1.4 (A)
VCC: J3.1, SW1.3 (C), SW1.6 (C)

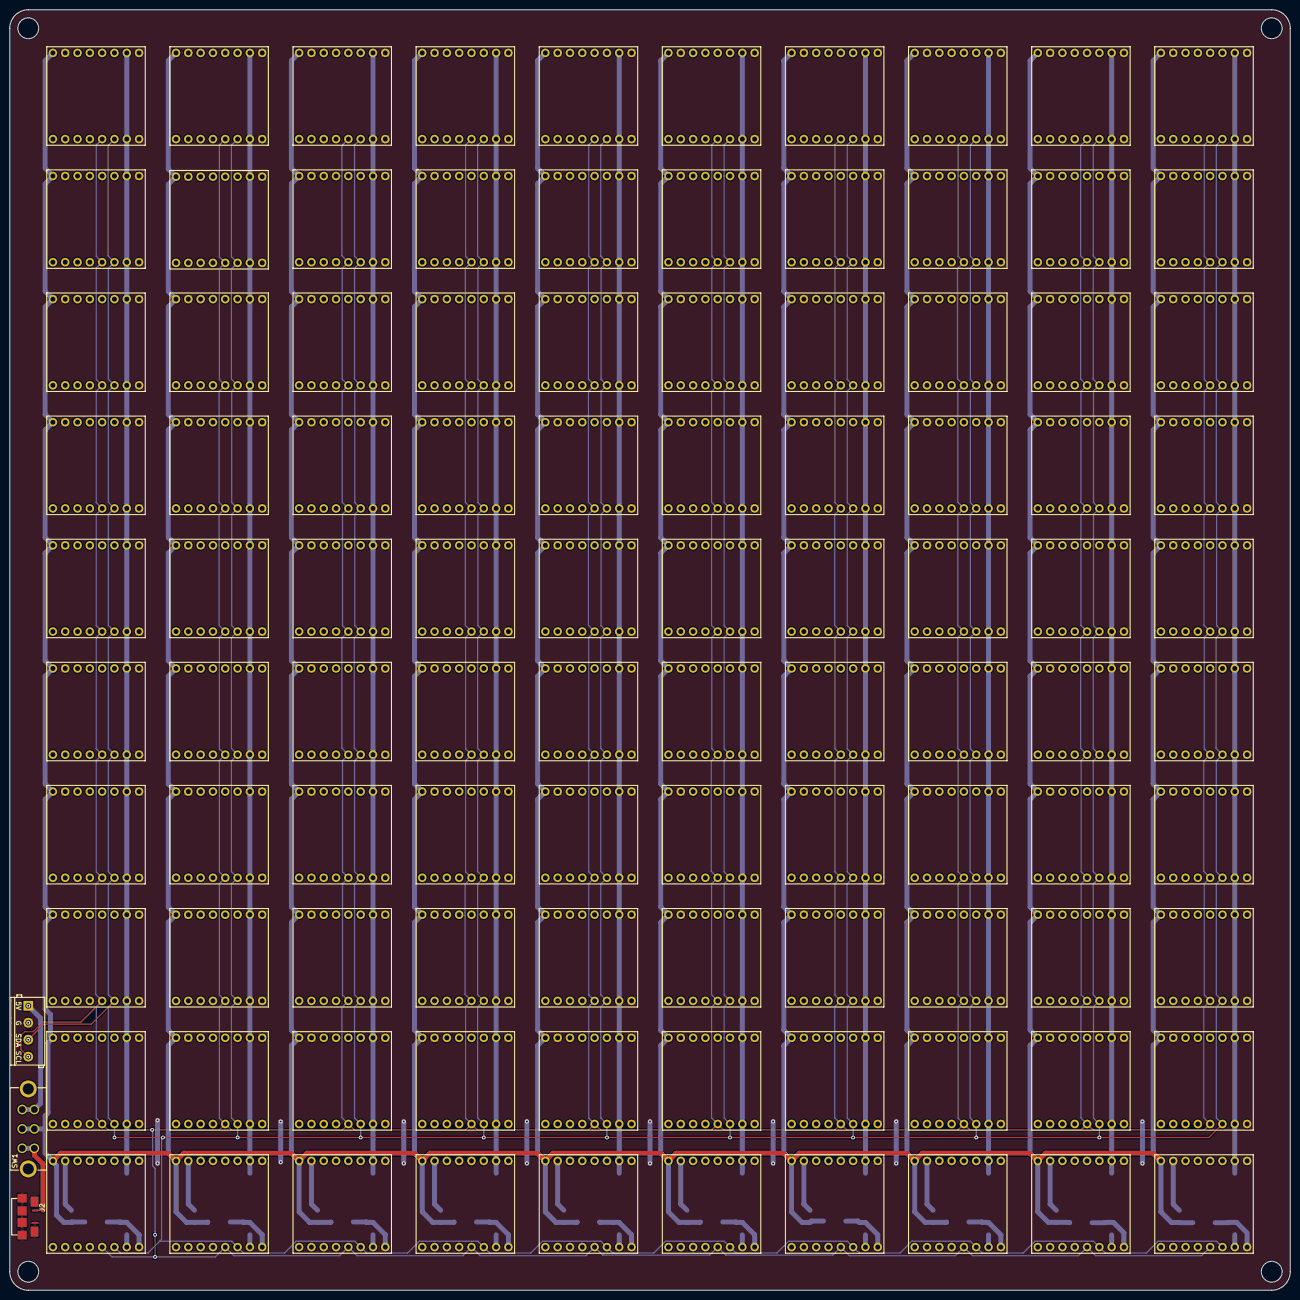
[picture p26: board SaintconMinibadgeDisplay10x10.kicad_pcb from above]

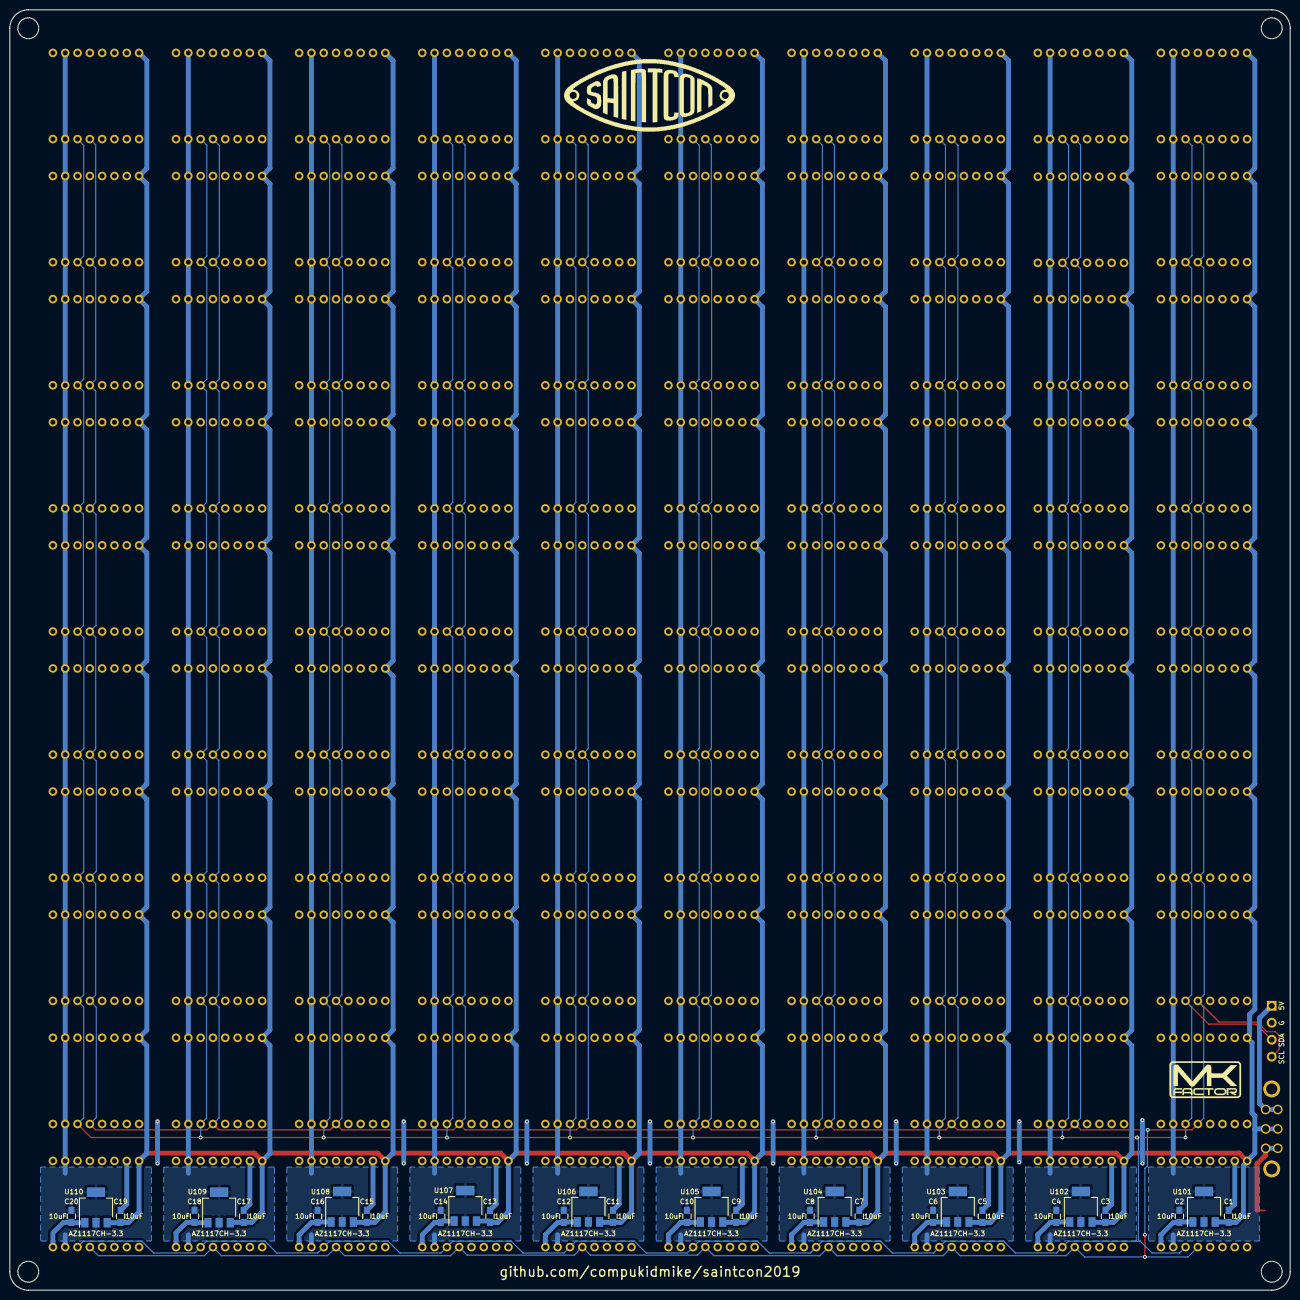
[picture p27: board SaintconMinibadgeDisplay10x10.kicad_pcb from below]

Board: 2 copper layers, 264.2 x 264.2 mm, 134 parts (31 on the bottom side), 16 nets.

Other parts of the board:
Ref**: Val**; drawing

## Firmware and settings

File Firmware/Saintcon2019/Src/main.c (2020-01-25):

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

/* Includes ------------------------------------------------------------------*/
#include "main.h"
#include "dma.h"
#include "i2c.h"
#include "spi.h"
#include "tim.h"
#include "usart.h"
#include "usb_device.h"
#include "gpio.h"

/* USER CODE BEGIN Includes */
#include "stdint.h"
#include "drv_is31fl.h"
#include "usbd_cdc_if.h"
#include "stm32l4xx_hal.h"
#include "errno.h"
#include "stm32l433xx.h"
#include "matrix.h"
#include "lampboard.h"
#include "keyboard.h"
#include "images.h"
#include "custommessage.h"
#include "eeprom_emul.h"
#include "stdlib.h"
#include "testmode.h"
#include "animations.h"
#include "menu.h"
#include "plugboard.h"
/* USER CODE END Includes */

/* USER CODE BEGIN PD */
#define LED_I2C_MASTER_NUM &hi2c1

/* USER CODE END PD */


/* USER CODE BEGIN PV */

//Uncomment to enable badge test mode
//#define BADGE_TEST_CODE

const char ERROR_COMMANDER[] = "You must have a commander to receive your debriefing. Invite one to join your ring.";
const uint8_t ERROR_COMMANDER_LENGTH = 83;
const char INITIAL_RING[] = "Helga has been captured! Your mission is to decode messages to enable Allied forces to save her from the Enemy. Intercepted messages can be picked up at Hut 6. Good luck!";
const uint8_t INITIAL_RING_LENGTH = 170;

const char RING1_MESSAGE[] = "Well done Agents! Helga has been rescued, but Trevor was recaptured. Your new mission is to stop the Enemy from extracting the vital intelligence that Trevor holds. Good luck!";
const char RING2_MESSAGE[] = "Trevor tragically paid the ultimate price, but hopefully the Enemy didn’t learn of our newest defense. Your new mission is to determine what the Enemy knows about Project Firewall.";
const char RING3_MESSAGE[] = "Mission Complete! Thanks to your decoding skills Helga was saved! Sadly Trevor gave his life to protect Project Firewall, but his sacrifice will never be forgotten #TrevorForget. Thanks for playing!";
const uint8_t RING1_MESSAGE_LENGTH = 175;
const uint8_t RING2_MESSAGE_LENGTH = 180;
const uint8_t RING3_MESSAGE_LENGTH = 198;

/* Virtual address Tab defined by the user: 0x0000 and 0xFFFF values are prohibited */
uint16_t VirtAddVarTab[NB_OF_VARIABLES];
uint32_t Index = 0;
__IO uint32_t ErasingOnGoing = 0;
uint32_t VarDataTab[NB_OF_VARIABLES] = {0};
uint32_t VarValue = 0;

uint8_t badgeLevel = 1; //Change to start on level 1 after the conference, when it's not possible to link up badges
uint8_t badgeNum = 1;

volatile uint8_t rbyte;

volatile uint8_t nextFrame = 0;

volatile int syncCounter = 0;

volatile int LeftRecvBufferHead = 0;
volatile int LeftRecvBufferTail = 0;
volatile uint8_t LeftRecvBuffer[UART_BUFFER_SIZE + 1];
volatile int RightRecvBufferHead = 0;
volatile int RightRecvBufferTail = 0;
volatile uint8_t RightRecvBuffer[UART_BUFFER_SIZE + 1];

/* USER CODE END PV */

void SystemClock_Config(void);
/* USER CODE BEGIN 0 */
/*
 * Delay for n msec
 */
static void
msec_delay(int n)
{
	HAL_Delay(n);
}
/* USER CODE END 0 */

/**
  * @brief  The application entry point.
  * @retval int
  */
int main(void)
{
  /* USER CODE BEGIN 1 */
	EE_Status ee_status = EE_OK;
  /* USER CODE END 1 */
  

  /* MCU Configuration--------------------------------------------------------*/

  /* Reset of all peripherals, Initializes the Flash interface and the Systick. */
  HAL_Init();

  /* Configure the system clock */
  SystemClock_Config();

  /* Initialize all configured peripherals */
  MX_GPIO_Init();
  MX_DMA_Init();
  MX_I2C1_Init();
  MX_I2C2_Init();
  MX_SPI1_Init();
  MX_SPI2_Init();
  MX_USART1_UART_Init();
  MX_USART2_UART_Init();
  MX_USB_DEVICE_Init();
  MX_TIM16_Init();
  /* USER CODE BEGIN 2 */

  /* Enable and set FLASH Interrupt priority */
    /* FLASH interrupt is used for the purpose of pages clean up under interrupt */
    HAL_NVIC_SetPriority(FLASH_IRQn, 0, 0);
    HAL_NVIC_EnableIRQ(FLASH_IRQn);

    /* Unlock the Flash Program Erase controller */
    HAL_FLASH_Unlock();
    /* Enable Power Control clock */
      __HAL_RCC_PWR_CLK_ENABLE();

      /* Set user List of Virtual Address variables: 0x0000 and 0xFFFF values are prohibited */
        for (VarValue = 0; VarValue < NB_OF_VARIABLES; VarValue++)
        {
          VirtAddVarTab[VarValue] = (uint16_t)(10*VarValue + 1);
        }

      /* Set EEPROM emulation firmware to erase all potentially incompletely erased
           pages if the system came from an asynchronous reset. Conditional erase is
           safe to use if all Flash operations where completed before the system reset */
        if(__HAL_PWR_GET_FLAG(PWR_FLAG_SB) == RESET)
        {


          /* System reset comes from a power-on reset: Forced Erase */
          /* Initialize EEPROM emulation driver (mandatory) */
          ee_status = EE_Init(VirtAddVarTab, EE_FORCED_ERASE);
          if(ee_status != EE_OK) {Error_Handler();}
        }
        else
        {
          /* Clear the Standby flag */
          __HAL_PWR_CLEAR_FLAG(PWR_FLAG_SB);


          /* System reset comes from a STANDBY wakeup: Conditional Erase*/
          /* Initialize EEPROM emulation driver (mandatory) */
          ee_status = EE_Init(VirtAddVarTab, EE_CONDITIONAL_ERASE);
          if(ee_status != EE_OK) {Error_Handler();}
        }





  HAL_TIM_Base_Start_IT(&htim16);

  FPGA_Init();

  HAL_GPIO_WritePin(GPIOE, GPIO_PIN_1,GPIO_PIN_SET);

  drv_is31fl_init();

  //uint8_t buffer[10];

  drv_is31fl_set_page(1);
  //HAL_I2C_Master_Transmit(&hi2c1, 0x50<<1, buffer,1,100);
  //drv_is31fl_send_value(10,128);

  //uint8_t x = 0;
  //uint8_t leddelay = 100;
  /* USER CODE END 2 */

  /* Infinite loop */
  /* USER CODE BEGIN WHILE */
//matrix_fillRect(0,0,64,16,COLOR_WHITE);
//matrix_update();
  //while(1);
  //uint8_t address = 70;

  InitMinibadges();



  /*
  HAL_I2C_Master_Transmit(&hi2c2, address, data, 2, 100);

  data[0] = 0x01;
  for(int x=0; x<2; x++){
	  data[1] = 0x01;
	  HAL_I2C_Master_Transmit(&hi2c2, address, data, 2, 100);
	  msec_delay(100);
	  data[1] = 0x02;
	  HAL_I2C_Master_Transmit(&hi2c2, address, data, 2, 100);
	  msec_delay(100);
	  data[1] = 0x04;
	  HAL_I2C_Master_Transmit(&hi2c2, address, data, 2, 100);
	  msec_delay(100);
	  data[1] = 0x08;
	  HAL_I2C_Master_Transmit(&hi2c2, address, data, 2, 100);
	  msec_delay(100);
	  data[1] = 0x10;
	  HAL_I2C_Master_Transmit(&hi2c2, address, data, 2, 100);
	  msec_delay(100);
	  data[1] = 0x20;
	  HAL_I2C_Master_Transmit(&hi2c2, address, data, 2, 100);
	  msec_delay(100);
	  data[1] = 0x40;
	  HAL_I2C_Master_Transmit(&hi2c2, address, data, 2, 100);
	  msec_delay(100);
	  data[1] = 0x80;
	  HAL_I2C_Master_Transmit(&hi2c2, address, data, 2, 100);
	  msec_delay(100);
  }
  data[1] = 0xFF;
  HAL_I2C_Master_Transmit(&hi2c2, address, data, 2, 100);
*/

  //Character Test
  //matrix_drawChar("SAINTCON",0,0,COLOR_RED);
 // matrix_update();
  //msec_delay(500);

  //Drawing Test
  /*matrix_drawRect(0,0,64,16,COLOR_RED);
  matrix_drawRect(1,1,62,14,COLOR_GREEN);
  matrix_drawRect(2,2,60,12,COLOR_BLUE);
  matrix_drawRect(3,3,58,10,COLOR_WHITE);
  matrix_drawRect(4,4,56,8,COLOR_RED);
  matrix_drawRect(5,5,54,6,COLOR_GREEN);
  matrix_drawRect(6,6,52,4,COLOR_BLUE);
  matrix_drawRect(7,7,50,2,COLOR_WHITE);
  matrix_update();
  msec_delay(500);
   */

  uint8_t data;
  if(EE_ReadVariable8bits(VirtAddVarTab[EEP_MESSAGE_CODE_1], &data) != EE_OK){
	  TestMode();
  }

  EE_ReadVariable8bits(VirtAddVarTab[EEP_CHALLENGE_LEVEL], &badgeLevel);
  if(badgeLevel == 0) badgeLevel = 1; //Fix for after conference - Skip initial ring and start on level 1

  //Image Test
  //matrix_drawImage(sc,0,0,38,16);
  matrix_drawImage(sc4,0,0,64,16);
  matrix_update();
  msec_delay(1000);


  menu();

/*
  for(int x=64; x>0; x-=2){
	  matrix_clear();
	  matrix_drawImageScaled(sc4,(64-x)/2,0,64,16,x,16);
	  matrix_update();
	  msec_delay(500);
  }
*/
  /*
  for(int i=0; i<16; i++){
	  matrix_clear();
	  matrix_drawLine(0,0,63,i, COLOR_RED);
	  matrix_update();
	  msec_delay(200);
  }
  for(int i=63; i>0; i--){
  	  matrix_clear();
  	  matrix_drawLine(0,0,i,15, COLOR_RED);
  	  matrix_update();
  	  msec_delay(200);
    }*/
  /*for(int i=0; i<16; i++){
  	  matrix_clear();
  	  matrix_drawLine(0,0,63,i, COLOR_RED);
  	  matrix_update();
  	  msec_delay(500);
    }
  for(int i=0; i<16; i++){
  	  matrix_clear();
  	  matrix_drawLine(0,0,63,i, COLOR_RED);
  	  matrix_update();
  	  msec_delay(500);
    }*/

  while (1){

	  if(nextFrame == 1){ //Set by Timer16 - 30FPS
		  nextFrame = 0;
		  //Button Test Code
		  uint32_t buttons = 0;
		  buttons = keyboardUpdate();
		  for(int x=0; x<26; x++){
			  if((buttons>>x) & 1){
				  lampboard_setLamp(x, COLOR_RED);
				  HAL_UART_Transmit(&huart1, (unsigned char*)"A", 1, 500);
			  } else {
				  lampboard_setLamp(x, COLOR_GREEN);
			  }
		  }
		  if((buttons>>31)&1){//LongPress
			  for(int x=0; x<26; x++){
				  lampboard_setLamp(x, COLOR_BLUE);
			  }
		  }
		  lampboard_update();
		  //msec_delay(50);
	  }

  }
    /* USER CODE END WHILE */

}

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
/* USER CODE BEGIN 4 */
void HAL_GPIO_EXTI_Callback(uint16_t GPIO_Pin){
	//Called when an external interrupt pin is triggered
	if(GPIO_Pin == SYNC_Pin){
		//syncCounter ++;
	}
	//if(GPIO_Pin == GPIO_PIN_2){
		//dispDelay = 500;
		//for(int x=0; x<100; x++){
		//HAL_UART_Transmit(&huart1, (unsigned char*)"A", 1, 500);
		//msec_delay(10);
		//}
	//}
}

void HAL_TIM_PeriodElapsedCallback(TIM_HandleTypeDef *htim){
	if(htim == &htim16){ //Timer16 - 30fps timer
		//Set flag here to alert main loop to draw new frame
		nextFrame = 1;
	}
	/*static uint8_t state = 0;
	if(state == 0){
		state = 1;
		drv_is31fl_send_value(0,0);
	} else {
		state = 0;
		drv_is31fl_send_value(0,128);
	}*/
}

void UART_Right_IRQ(UART_HandleTypeDef *huart){ //huart1
	uint32_t isrflags   = READ_REG(huart->Instance->ISR);
	  uint32_t cr1its     = READ_REG(huart->Instance->CR1);
	  uint32_t cr3its     = READ_REG(huart->Instance->CR3);

	  uint32_t errorflags;
	  //uint32_t errorcode;

	  if (((isrflags & USART_ISR_RXNE) != 0U) //Receive Mode
			  && ((cr1its & USART_CR1_RXNEIE) != 0U)){
		  /* If no error occurs */
		  errorflags = (isrflags & (uint32_t)(USART_ISR_PE | USART_ISR_FE | USART_ISR_ORE | USART_ISR_NE));
		  if (errorflags == 0U)
		  {
			  if(RightRecvBufferHead == ((RightRecvBufferTail - 1 + UART_BUFFER_SIZE) % UART_BUFFER_SIZE)){
				  //Buffer Full

				  rbyte = (uint8_t)huart->Instance->RDR;
			  } else {
				  RightRecvBuffer[RightRecvBufferHead] = (uint8_t)huart->Instance->RDR;
				  RightRecvBufferHead = (RightRecvBufferHead + 1) % UART_BUFFER_SIZE;
			  }
		  }
	  } else {
		  rbyte = (uint8_t)huart->Instance->RDR;
	  }


	  __HAL_UART_CLEAR_FLAG(huart, UART_CLEAR_PEF);
	  __HAL_UART_CLEAR_FLAG(huart, UART_CLEAR_FEF);
	  __HAL_UART_CLEAR_FLAG(huart, UART_CLEAR_NEF);
	  __HAL_UART_CLEAR_FLAG(huart, UART_CLEAR_OREF);
	  __HAL_UART_CLEAR_FLAG(huart, UART_CLEAR_WUF);
}

void UART_Left_IRQ(UART_HandleTypeDef *huart){ //huart2
	uint32_t isrflags   = READ_REG(huart->Instance->ISR);
		  uint32_t cr1its     = READ_REG(huart->Instance->CR1);
		  uint32_t cr3its     = READ_REG(huart->Instance->CR3);

		  uint32_t errorflags;
		  uint32_t errorcode;

		  if ((isrflags & USART_ISR_RXNE) != 0U){ //Receive Mode
				  //&& ((cr1its & USART_CR1_RXNEIE) != 0U)){
			  /* If no error occurs */
			  errorflags = (isrflags & (uint32_t)(USART_ISR_PE | USART_ISR_FE | USART_ISR_ORE | USART_ISR_NE));
			  if (errorflags == 0U)
			  {
				  if(LeftRecvBufferHead == ((LeftRecvBufferTail - 1 + UART_BUFFER_SIZE) % UART_BUFFER_SIZE)){
					  //Buffer Full
					  rbyte = (uint8_t)huart->Instance->RDR;
				  } else {
					  LeftRecvBuffer[LeftRecvBufferHead] = (uint8_t)huart->Instance->RDR;
					  LeftRecvBufferHead = (LeftRecvBufferHead + 1) % UART_BUFFER_SIZE;
				  }
			  }
		  } else {
			  rbyte = (uint8_t)huart->Instance->RDR;
		  }

		  __HAL_UART_CLEAR_FLAG(huart, UART_CLEAR_PEF);
		  __HAL_UART_CLEAR_FLAG(huart, UART_CLEAR_FEF);
		  __HAL_UART_CLEAR_FLAG(huart, UART_CLEAR_NEF);
		  __HAL_UART_CLEAR_FLAG(huart, UART_CLEAR_OREF);
		  __HAL_UART_CLEAR_FLAG(huart, UART_CLEAR_WUF);

}

void CheckSerial(){

	uint8_t leftBadgeLevel = 0;
	uint8_t leftBadgeNum = 0;
	//uint8_t leftBadgeNum = 25; //for testing
	//Left Serial
	if(LeftRecvBufferHead == LeftRecvBufferTail){
		//Buffer Empty
	} else {
		uint8_t data = LeftRecvBuffer[LeftRecvBufferTail];
		//LeftRecvBufferTail = (LeftRecvBufferTail + 1) % UART_BUFFER_SIZE;
		if(data == SYNC){
			DisplayAnimation();
		} else {
			LeftRecvBufferTail = (LeftRecvBufferTail + 1) % UART_BUFFER_SIZE;
		}

	}

	uint8_t rightBadgeLevel = 0;
	//Right Serial
	if(RightRecvBufferHead == RightRecvBufferTail){
		//Buffer Empty
	} else {
		uint8_t data = RightRecvBuffer[RightRecvBufferTail];

		if(data == badgeNum){
			DisplayAnimation();
		} else {
			RightRecvBufferTail = (RightRecvBufferTail + 1) % UART_BUFFER_SIZE;
		}

		if(data == SYNC + 1){ //201
			uint8_t out[8];
			uint8_t data = 0;
			out[0] = SYNC;
			out[1] = badgeLevel;
			if(badgeLevel < 1){
				for(int x=0; x<6; x++){
					out[x + 2] = 'A';
				}
			} else if(badgeLevel < 2){
				for(int x=0; x<6; x++){
					EE_ReadVariable8bits(EEP_MESSAGE_CODE_1 + x, &data);
					out[x + 2] = data+65;
				}
			} else if(badgeLevel < 3){
				for(int x=0; x<6; x++){
					EE_ReadVariable8bits(EEP_MESSAGE_CODE_2 + x, &data);
					out[x + 2] = data+65;
				}
			} else if(badgeLevel < 4){
				for(int x=0; x<6; x++){
					EE_ReadVariable8bits(EEP_MESSAGE_CODE_3 + x, &data);
					out[x + 2] = data+65;
				}
			} else if(badgeLevel < 5){
				for(int x=0; x<6; x++){
					out[x + 2]='A';
				}
			} else if(badgeLevel < 6){
				for(int x=0; x<6; x++){
					EE_ReadVariable8bits(EEP_MESSAGE_CODE_4 + x, &data);
					out[x + 2] = data+65;
				}
			} else if(badgeLevel < 7){
				for(int x=0; x<6; x++){
					EE_ReadVariable8bits(EEP_MESSAGE_CODE_5 + x, &data);
					out[x + 2] = data+65;
				}
			} else if(badgeLevel < 8){
				for(int x=0; x<6; x++){
					EE_ReadVariable8bits(EEP_MESSAGE_CODE_6 + x, &data);
					out[x + 2] = data+65;
				}
			} else if(badgeLevel < 9){
				for(int x=0; x<6; x++){
					out[x + 2]='A';
				}
			} else if(badgeLevel < 10){
				for(int x=0; x<6; x++){
					EE_ReadVariable8bits(EEP_MESSAGE_CODE_7 + x, &data);
					out[x + 2] = data+65;
				}
			} else if(badgeLevel < 11){
				for(int x=0; x<6; x++){
					EE_ReadVariable8bits(EEP_MESSAGE_CODE_8 + x, &data);
					out[x + 2] = data+65;
				}
			} else if(badgeLevel < 12){
				for(int x=0; x<6; x++){
					EE_ReadVariable8bits(EEP_MESSAGE_CODE_9 + x, &data);
					out[x + 2] = data+65;
				}
			} else if(badgeLevel < 13){
				for(int x=0; x<6; x++){
					out[x + 2] = 'A';
				}
			} else if(badgeLevel < 14){
				for(int x=0; x<6; x++){
					out[x + 2] = 'Z';
				}
			}
			HAL_UART_Transmit(&huart1, out, 8, 100); //Send Code to Printer
			//matrix_clear();
			//matrix_drawCharCentered("PRINTING", 0, 4, COLOR_GREEN);
			//matrix_update();
			//HAL_Delay(1000);
		}
				/*if(data == SYNC){
					while(RightRecvBufferHead == RightRecvBufferTail);
					rightBadgeLevel = RightRecvBuffer[RightRecvBufferTail];
					RightRecvBufferTail = (RightRecvBufferTail + 1) % UART_BUFFER_SIZE;
					while(RightRecvBufferHead == RightRecvBufferTail);
					uint8_t rightBadgeNum = RightRecvBuffer[RightRecvBufferTail];
					RightRecvBufferTail = (RightRecvBufferTail + 1) % UART_BUFFER_SIZE;
					while(RightRecvBufferHead == RightRecvBufferTail);
					uint8_t rightBadgeCommand = RightRecvBuffer[RightRecvBufferTail];
					RightRecvBufferTail = (RightRecvBufferTail + 1) % UART_BUFFER_SIZE;

					uint8_t ack[5];
					switch(rightBadgeCommand){
					case 2: //Ack
						ack[0] = SYNC;
						ack[1] = badgeLevel;
						//ack[2] = leftBadgeNum + 1;
						ack[2] = 26;
						ack[3] = 4;
						ack[4] = 0;
						HAL_UART_Transmit(&huart1, ack, 5, 100); //Send Display Rotor Animation
						DisplayAnimation(leftBadgeLevel, leftBadgeNum, 4, badgeLevel);
						break;

					case 5: //Request Level Code
						;
						uint8_t code[10] = {SYNC, badgeLevel, 1, 6};
						if(badgeLevel == 1){
							for(int x=4; x<10; x++){
								EE_ReadVariable8bits(EEP_MESSAGE_CODE_1 + x, code[x]);
							}
						}
						if(badgeLevel == 2){
							for(int x=4; x<10; x++){
								EE_ReadVariable8bits(EEP_MESSAGE_CODE_2 + x, code[x]);
							}
						}
						if(badgeLevel == 3){
							for(int x=4; x<10; x++){
								EE_ReadVariable8bits(EEP_MESSAGE_CODE_3 + x, code[x]);
							}
						}
						if(badgeLevel == 4){
							for(int x=4; x<10; x++){
								EE_ReadVariable8bits(EEP_MESSAGE_CODE_4 + x, code[x]);
							}
						}
						if(badgeLevel == 5){
							for(int x=4; x<10; x++){
								EE_ReadVariable8bits(EEP_MESSAGE_CODE_5 + x, code[x]);
							}
						}
						if(badgeLevel == 6){
							for(int x=4; x<10; x++){
								EE_ReadVariable8bits(EEP_MESSAGE_CODE_6 + x, code[x]);
							}
						}
						if(badgeLevel == 7){
							for(int x=4; x<10; x++){
								EE_ReadVariable8bits(EEP_MESSAGE_CODE_7 + x, code[x]);
							}
						}
						if(badgeLevel == 8){
							for(int x=4; x<10; x++){
								EE_ReadVariable8bits(EEP_MESSAGE_CODE_8 + x, code[x]);
							}
						}
						if(badgeLevel == 9){
							for(int x=4; x<10; x++){
								EE_ReadVariable8bits(EEP_MESSAGE_CODE_9 + x, code[x]);
							}
						}
						HAL_UART_Transmit(&huart1, code, 10, 100); //Send Level Code
						break;
					}
				}*/
	}

	//uint8_t outData[4] = {SYNC, badgeLevel, leftBadgeNum + 1, 1};
	//uint8_t outData[4] = {SYNC, badgeLevel, 26, 1};
	//HAL_UART_Transmit(&huart1, outData, 4, 100); //Send Hello to Right side
	uint8_t outData[5] = {SYNC, badgeLevel, 1, 4, 0};
	HAL_UART_Transmit(&huart1, outData, 5, 100); //Send Rotor Command to Right
}


/* USER CODE END 4 */
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


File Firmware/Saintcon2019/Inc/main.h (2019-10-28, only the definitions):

#define KBD_A_Pin GPIO_PIN_2
#define KBD_A_GPIO_Port GPIOE
#define KBD_B_Pin GPIO_PIN_3
#define KBD_B_GPIO_Port GPIOE
#define KBD_C_Pin GPIO_PIN_4
#define KBD_C_GPIO_Port GPIOE
#define KBD_D_Pin GPIO_PIN_5
#define KBD_D_GPIO_Port GPIOE
#define KBD_E_Pin GPIO_PIN_6
#define KBD_E_GPIO_Port GPIOE
#define PlugX_Pin GPIO_PIN_13
#define PlugX_GPIO_Port GPIOC
#define PlugY_Pin GPIO_PIN_14
#define PlugY_GPIO_Port GPIOC
#define PlugZ_Pin GPIO_PIN_15
#define PlugZ_GPIO_Port GPIOC
#define I2CRST_Pin GPIO_PIN_1
#define I2CRST_GPIO_Port GPIOH
#define PlugK_Pin GPIO_PIN_0
#define PlugK_GPIO_Port GPIOC
#define PlugL_Pin GPIO_PIN_1
#define PlugL_GPIO_Port GPIOC
#define PlugM_Pin GPIO_PIN_2
#define PlugM_GPIO_Port GPIOC
#define PlugN_Pin GPIO_PIN_3
#define PlugN_GPIO_Port GPIOC
#define PlugA_Pin GPIO_PIN_0
#define PlugA_GPIO_Port GPIOA
#define PlugB_Pin GPIO_PIN_1
#define PlugB_GPIO_Port GPIOA
#define PlugC_Pin GPIO_PIN_4
#define PlugC_GPIO_Port GPIOA
#define PlugD_Pin GPIO_PIN_5
#define PlugD_GPIO_Port GPIOA
#define PlugE_Pin GPIO_PIN_6
#define PlugE_GPIO_Port GPIOA
#define PlugF_Pin GPIO_PIN_7
#define PlugF_GPIO_Port GPIOA
#define PlugO_Pin GPIO_PIN_4
#define PlugO_GPIO_Port GPIOC
#define PlugP_Pin GPIO_PIN_5
#define PlugP_GPIO_Port GPIOC
#define PlugH_Pin GPIO_PIN_0
#define PlugH_GPIO_Port GPIOB
#define PlugI_Pin GPIO_PIN_1
#define PlugI_GPIO_Port GPIOB
#define PlugJ_Pin GPIO_PIN_2
#define PlugJ_GPIO_Port GPIOB
#define KBD_F_Pin GPIO_PIN_7
#define KBD_F_GPIO_Port GPIOE
#define KBD_G_Pin GPIO_PIN_8
#define KBD_G_GPIO_Port GPIOE
#define KBD_H_Pin GPIO_PIN_9
#define KBD_H_GPIO_Port GPIOE
#define KBD_I_Pin GPIO_PIN_10
#define KBD_I_GPIO_Port GPIOE
#define KBD_J_Pin GPIO_PIN_11
#define KBD_J_GPIO_Port GPIOE
#define KBD_K_Pin GPIO_PIN_12
#define KBD_K_GPIO_Port GPIOE
#define KBD_L_Pin GPIO_PIN_13
#define KBD_L_GPIO_Port GPIOE
#define KBD_M_Pin GPIO_PIN_14
#define KBD_M_GPIO_Port GPIOE
#define KBD_N_Pin GPIO_PIN_15
#define KBD_N_GPIO_Port GPIOE
#define MB_CS1_Pin GPIO_PIN_12
#define MB_CS1_GPIO_Port GPIOB
#define MB_RESET_Pin GPIO_PIN_8
#define MB_RESET_GPIO_Port GPIOD
#define KBD_W_Pin GPIO_PIN_9
#define KBD_W_GPIO_Port GPIOD
#define KBD_X_Pin GPIO_PIN_10
#define KBD_X_GPIO_Port GPIOD
#define KBD_Y_Pin GPIO_PIN_11
#define KBD_Y_GPIO_Port GPIOD
#define KBD_Z_Pin GPIO_PIN_12
#define KBD_Z_GPIO_Port GPIOD
#define MB_CS2_Pin GPIO_PIN_13
#define MB_CS2_GPIO_Port GPIOD
#define MB_CS3_Pin GPIO_PIN_14
#define MB_CS3_GPIO_Port GPIOD
#define SYNC_Pin GPIO_PIN_15
#define SYNC_GPIO_Port GPIOD
#define SYNC_EXTI_IRQn EXTI15_10_IRQn
#define PlugQ_Pin GPIO_PIN_6
#define PlugQ_GPIO_Port GPIOC
#define PlugR_Pin GPIO_PIN_7
#define PlugR_GPIO_Port GPIOC
#define PlugS_Pin GPIO_PIN_8
#define PlugS_GPIO_Port GPIOC
#define PlugT_Pin GPIO_PIN_9
#define PlugT_GPIO_Port GPIOC
#define PlugG_Pin GPIO_PIN_8
#define PlugG_GPIO_Port GPIOA
#define PlugU_Pin GPIO_PIN_10
#define PlugU_GPIO_Port GPIOC
#define PlugV_Pin GPIO_PIN_11
#define PlugV_GPIO_Port GPIOC
#define PlugW_Pin GPIO_PIN_12
#define PlugW_GPIO_Port GPIOC
#define KBD_O_Pin GPIO_PIN_0
#define KBD_O_GPIO_Port GPIOD
#define KBD_P_Pin GPIO_PIN_1
#define KBD_P_GPIO_Port GPIOD
#define KBD_Q_Pin GPIO_PIN_2
#define KBD_Q_GPIO_Port GPIOD
#define KBD_R_Pin GPIO_PIN_3
#define KBD_R_GPIO_Port GPIOD
#define KBD_S_Pin GPIO_PIN_4
#define KBD_S_GPIO_Port GPIOD
#define KBD_T_Pin GPIO_PIN_5
#define KBD_T_GPIO_Port GPIOD
#define KBD_U_Pin GPIO_PIN_6
#define KBD_U_GPIO_Port GPIOD
#define KBD_V_Pin GPIO_PIN_7
#define KBD_V_GPIO_Port GPIOD
#define ICE_CRESET_Pin GPIO_PIN_6
#define ICE_CRESET_GPIO_Port GPIOB
#define ICE_CDONE_Pin GPIO_PIN_7
#define ICE_CDONE_GPIO_Port GPIOB
#define TEST1_Pin GPIO_PIN_3
#define TEST1_GPIO_Port GPIOH
#define MB_CS4_Pin GPIO_PIN_0
#define MB_CS4_GPIO_Port GPIOE
#define SDB_Pin GPIO_PIN_1
#define SDB_GPIO_Port GPIOE
#define LED5_Pin GPIO_PIN_13
#define LED5_GPIO_Port GPIOC
#define SPI1_MUX_S_Pin GPIO_PIN_14
#define SPI1_MUX_S_GPIO_Port GPIOC
#define SPI1_MUX_OE_Pin GPIO_PIN_15
#define SPI1_MUX_OE_GPIO_Port GPIOC
#define AN0_Pin GPIO_PIN_0
#define AN0_GPIO_Port GPIOC
#define AN1_Pin GPIO_PIN_1
#define AN1_GPIO_Port GPIOC
#define AN2_Pin GPIO_PIN_2
#define AN2_GPIO_Port GPIOC
#define AN3_Pin GPIO_PIN_3
#define AN3_GPIO_Port GPIOC
#define AN4_Pin GPIO_PIN_0
#define AN4_GPIO_Port GPIOA
#define AN5_Pin GPIO_PIN_1
#define AN5_GPIO_Port GPIOA
#define QSPI_CS_Pin GPIO_PIN_2
#define QSPI_CS_GPIO_Port GPIOA
#define QSPI_CLK_Pin GPIO_PIN_3
#define QSPI_CLK_GPIO_Port GPIOA
#define DIG9_Pin GPIO_PIN_4
#define DIG9_GPIO_Port GPIOA
#define DIG5_Pin GPIO_PIN_5
#define DIG5_GPIO_Port GPIOA
#define QSPI_D3_Pin GPIO_PIN_6
#define QSPI_D3_GPIO_Port GPIOA
#define QSPI_D2_Pin GPIO_PIN_7
#define QSPI_D2_GPIO_Port GPIOA
#define DIG0_Pin GPIO_PIN_4
#define DIG0_GPIO_Port GPIOC
#define DIG1_Pin GPIO_PIN_5
#define DIG1_GPIO_Port GPIOC
#define QSPI_D1_Pin GPIO_PIN_0
#define QSPI_D1_GPIO_Port GPIOB
#define QSPI_D0_Pin GPIO_PIN_1
#define QSPI_D0_GPIO_Port GPIOB
#define DIG2_Pin GPIO_PIN_2
#define DIG2_GPIO_Port GPIOB
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

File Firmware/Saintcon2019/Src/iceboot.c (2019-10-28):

/*
 * Configure the ICE40 with new bitstreams:
 *	- first from flash at offset FLASH_ICE40_START (if one exists there)
 *	- then repeatedly from uart1 or usbcdc
 */

#include "main.h"
#include "dma.h"
#include "i2c.h"
#include "spi.h"
#include "usart.h"
#include "usb_device.h"
#include "gpio.h"
#include "tim.h"
#include "usbd_cdc_if.h"
#include "stm32l4xx_hal.h"
#include "errno.h"
#include "stm32l433xx.h"
#include "drv_is31fl.h"
#include "matrix.h"
#include "lampboard.h"
#include "keyboard.h"
//#include "usart.h"

#define VER "<Iceboot 0.4> "

//enum { FLASH_ICE40_START = 0x0801F000, FLASH_ICE40_END = 0x08040000 };
//enum { FLASH_ICE40_START = 0x0801F000, FLASH_ICE40_END = 0x08026DDC };
enum { FLASH_ICE40_START = 0x0801F000, FLASH_ICE40_END = 0x08026DDF };
enum { OK, TIMEOUT, ICE_ERROR };
enum { UART_FIFOSIZE = 1024 };	/* must be power of 2 */

typedef int (*Reader)(uint8_t*, uint16_t*);

#define gpio_low(pin)	HAL_GPIO_WritePin(pin##_GPIO_Port, pin##_Pin, GPIO_PIN_RESET)
#define gpio_high(pin)	HAL_GPIO_WritePin(pin##_GPIO_Port, pin##_Pin, GPIO_PIN_SET)
#define gpio_ishigh(pin)	(HAL_GPIO_ReadPin(pin##_GPIO_Port, pin##_Pin) == GPIO_PIN_SET)
#define gpio_toggle(pin)	HAL_GPIO_TogglePin(pin##_GPIO_Port, pin##_Pin)
//#define select_rpi() HAL_GPIO_WritePin(GPIOC, SPI3_MUX_S_Pin, GPIO_PIN_SET)
//#define select_leds() HAL_GPIO_WritePin(GPIOC, SPI3_MUX_S_Pin, GPIO_PIN_RESET)
//#define enable_mux_out() HAL_GPIO_WritePin(GPIOC, SPI3_MUX_OE_Pin, GPIO_PIN_RESET)
//#define disable_mux_out() HAL_GPIO_WritePin(GPIOC, SPI3_MUX_OE_Pin, GPIO_PIN_SET)
//#define status_led_high() HAL_GPIO_WritePin(GPIOC, LED5_Pin, GPIO_PIN_SET)
//#define status_led_low() HAL_GPIO_WritePin(GPIOC, LED5_Pin, GPIO_PIN_RESET)
//#define status_led_toggle() HAL_GPIO_TogglePin(GPIOC, LED5_Pin)


extern UART_HandleTypeDef huart1;
extern UART_HandleTypeDef huart2;
extern SPI_HandleTypeDef hspi1;
extern USBD_HandleTypeDef hUsbDeviceFS;

static uint16_t crc;
static uint8_t *memp, *endmem;
static int cdc_stopped;
static int uart_detached;

volatile uint8_t spiDone = 0;
volatile uint16_t dispDelay = 1000;
uint8_t framebuffer[3075];



uint8_t buffer_rx[10];

/*
 * Dummy memory allocator for newlib, so we can call snprintf
 */
/*caddr_t
_sbrk(int incr)
{
	errno = ENOMEM;
	return (caddr_t) -1;
}*/

/*
 * Readahead fifo for input
 */
static struct fifo {
	int head, tail, max;
	uint8_t buf[UART_FIFOSIZE];
} in_fifo;

static int
fifo_put(struct fifo *f, int c)
{
	int tl;
	int count;

	tl = f->tail;
	count = tl - f->head;
	if (count < 0)
		count += UART_FIFOSIZE;
	if (count > f->max)
		f->max = count;
	if (count == UART_FIFOSIZE - 1)
		return -1;
	f->buf[tl++] = c;
	f->tail = tl & (UART_FIFOSIZE-1);
	if (count > (3*UART_FIFOSIZE)/4)
		cdc_stopped = 1;
	return OK;
}

static int
fifo_get(struct fifo *f, uint8_t *b)
{
	int hd;
	int count;

	hd = f->head;
	count = f->tail - hd;
	if (count < 0)
		count += UART_FIFOSIZE;
	if (count == 0)
		return -1;
	*b = f->buf[hd++];
	f->head = hd & (UART_FIFOSIZE-1);
	if (cdc_stopped && count < UART_FIFOSIZE/4) {
		cdc_stopped = 0;
		USBD_CDC_ReceivePacket(&hUsbDeviceFS);
	}
	return OK;
}

/*
 * Write a string to usbcdc, and to uart1 if not detached,
 * adding an extra CR if it ends with LF
 */
static void
uart_puts(char *s)
{
	char *p;

	for (p = s; *p; p++)
		;
	//if (!uart_detached)
		//HAL_USART_Transmit(&huart1, (unsigned char*)s, p - s, 500);
	CDC_Transmit_FS((unsigned char*)s, p - s);
	if (p > s && p[-1] == '\n')
		uart_puts("\r");
}

/*
 * Read one byte from input fifo, waiting until one is available
 */
static int
uart_getc(uint8_t *b)
{
	while (in_fifo.head == in_fifo.tail)
		;
	return fifo_get(&in_fifo, b);
}


/*
 * Read one byte from uart1, returning TIMEOUT immediately if one is not available
 */
static int
uart_trygetc(uint8_t *b)
{
	//if (HAL_USART_Receive(&huart1, b, 1, 0) != HAL_OK)
		//return TIMEOUT;
	return OK;
}

/*
 * Interrupt callback on uart error (probably overrun)
 */
void
HAL_UART_ErrorCallback(UART_HandleTypeDef *huart)
{
	uart_puts("UART Error!\n");
}

/*
 * Interrupt callback when a packet has been read from usbcdc
 */
static int8_t
usbcdc_rxcallback(uint8_t *data, uint32_t *len)
{
	int i;
	int n;

	n = *len;
	for (i = 0; i < n; i++) {
		if (fifo_put(&in_fifo, *data++) < 0) {
			uart_puts("Fifo overflow!\n");
			return OK;
		}
	}
	if (!cdc_stopped)
		USBD_CDC_ReceivePacket(&hUsbDeviceFS);
	return OK;
}

/*
 * Enable reading from usbcdc in interrupt mode
 */
static void
usbcdc_startread(void)
{
	USBD_Interface_fops_FS.Receive = &usbcdc_rxcallback;
	cdc_stopped = 1;
}

/*
 * Delay for n msec
 */
static void
msec_delay(int n)
{
	HAL_Delay(n);
}

static uint8_t spibuf[64];
static int nspi;

/*
 * Write to spi3 in multiple chunks (HAL_SPI_Transmit length is limited to 16 bits)
 */
static int
spi_write(uint8_t *p, uint32_t len)
{
	int ret;
	uint16_t n;

	ret = HAL_OK;
	n = 0x8000;
	while (len > 0) {
		if (len < n)
			n = len;
		ret = HAL_SPI_Transmit(&hspi1, p, n, HAL_MAX_DELAY);
		if (ret != HAL_OK)
			return ret;
		len -= n;
		p += n;
	}
	return ret;
}

/*
 * Append one byte to output buffer for spi3.
 * If arg is negative, flush the buffer.
 */
static void
spi_write1(int b)
{
	if (b >= 0)
		spibuf[nspi++] = b;
	if ((b < 0 && nspi > 0) || nspi == sizeof spibuf) {
		spi_write(spibuf, sizeof spibuf);
		nspi = 0;
	}
}

/*
 * Tri-state spi3 pins which are shared with ice40 LED1-4 signals
 */
static void
spi_detach(void)
{
	HAL_SPI_MspDeInit(&hspi1);
	HAL_GPIO_DeInit(ICE40_SPI_CS_GPIO_Port, ICE40_SPI_CS_Pin);
}

/*
 * Reconnect the spi3 pins
 */
static void
spi_reattach(void)
{
	GPIO_InitTypeDef g;

	HAL_SPI_MspInit(&hspi1);
	g.Pin = ICE40_SPI_CS_Pin;
	g.Mode = GPIO_MODE_OUTPUT_PP;
	g.Pull = GPIO_NOPULL;
	g.Speed = GPIO_SPEED_FREQ_LOW;
	HAL_GPIO_Init(ICE40_SPI_CS_GPIO_Port, &g);
	gpio_low(ICE40_SPI_CS);
}

/*
 * Tristate the uart1 rx/tx pins
 */
static void
uart_detach(void)
{
	uart_detached = 1;
	//HAL_USART_MspDeInit(&huart1);
}
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

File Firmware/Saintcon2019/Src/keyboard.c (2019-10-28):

/*
 * keyboard.c
 *
 *  Created on: Aug 24, 2019
 *      Author: compukidmike
 */

#include "keyboard.h"
#include "gpio.h"

#define gpio_ishigh(pin)	(HAL_GPIO_ReadPin(pin##_GPIO_Port, pin##_Pin) == GPIO_PIN_SET)
#define gpio_ispressed(pin)	!(HAL_GPIO_ReadPin(pin##_GPIO_Port, pin##_Pin) == GPIO_PIN_SET)
#define LONG_PRESS_MS 3000

static uint32_t PreviousButtonState;

static uint32_t APressedTime = 0;
static uint32_t BPressedTime = 0;
static uint32_t CPressedTime = 0;
static uint32_t DPressedTime = 0;
static uint32_t EPressedTime = 0;
static uint32_t FPressedTime = 0;
static uint32_t GPressedTime = 0;
static uint32_t HPressedTime = 0;
static uint32_t IPressedTime = 0;
static uint32_t JPressedTime = 0;
static uint32_t KPressedTime = 0;
static uint32_t LPressedTime = 0;
static uint32_t MPressedTime = 0;
static uint32_t NPressedTime = 0;
static uint32_t OPressedTime = 0;
static uint32_t PPressedTime = 0;
static uint32_t QPressedTime = 0;
static uint32_t RPressedTime = 0;
static uint32_t SPressedTime = 0;
static uint32_t TPressedTime = 0;
static uint32_t UPressedTime = 0;
static uint32_t VPressedTime = 0;
static uint32_t WPressedTime = 0;
static uint32_t XPressedTime = 0;
static uint32_t YPressedTime = 0;
static uint32_t ZPressedTime = 0;

uint32_t keyboardUpdate(){

	uint32_t retval = 0;

	if(gpio_ispressed(KBDA)){
		if(PreviousButtonState & 1<<0){
			if(HAL_GetTick()-APressedTime > LONG_PRESS_MS){
				retval |= 1<<31;//ButtonLongPressed
			}
		} else {
			APressedTime = HAL_GetTick();
			PreviousButtonState |= 1<<0;
			retval |= 1<<0;//A
		}
	} else {
		PreviousButtonState = PreviousButtonState & ~(1<<0);
	}
	if(gpio_ispressed(KBDB)){
		if(PreviousButtonState & 1<<1){
			if(HAL_GetTick()-BPressedTime > LONG_PRESS_MS){
				retval |= 1<<31;//ButtonLongPressed
			}
		} else {
			BPressedTime = HAL_GetTick();
			PreviousButtonState |= 1<<1;
			retval |= 1<<1;//B
		}
	} else {
		PreviousButtonState = PreviousButtonState & ~(1<<1);
	}
	if(gpio_ispressed(KBDC)){
			if(PreviousButtonState & 1<<2){
				if(HAL_GetTick()-CPressedTime > LONG_PRESS_MS){
					retval |= 1<<31;//ButtonLongPressed
				}
			} else {
				CPressedTime = HAL_GetTick();
				PreviousButtonState |= 1<<2;
				retval |= 1<<2;//C
			}
		} else {
			PreviousButtonState = PreviousButtonState & ~(1<<2);
		}
	if(gpio_ispressed(KBDD)){
			if(PreviousButtonState & 1<<3){
				if(HAL_GetTick()-DPressedTime > LONG_PRESS_MS){
					retval |= 1<<31;//ButtonLongPressed
				}
			} else {
				DPressedTime = HAL_GetTick();
				PreviousButtonState |= 1<<3;
				retval |= 1<<3;//D
			}
		} else {
			PreviousButtonState = PreviousButtonState & ~(1<<3);
		}
	if(gpio_ispressed(KBDE)){
			if(PreviousButtonState & 1<<4){
				if(HAL_GetTick()-EPressedTime > LONG_PRESS_MS){
					retval |= 1<<31;//ButtonLongPressed
				}
			} else {
				EPressedTime = HAL_GetTick();
				PreviousButtonState |= 1<<4;
				retval |= 1<<4;//E
			}
		} else {
			PreviousButtonState = PreviousButtonState & ~(1<<4);
		}
	if(gpio_ispressed(KBDF)){
			if(PreviousButtonState & 1<<5){
				if(HAL_GetTick()-FPressedTime > LONG_PRESS_MS){
					retval |= 1<<31;//ButtonLongPressed
				}
			} else {
				FPressedTime = HAL_GetTick();
				PreviousButtonState |= 1<<5;
				retval |= 1<<5;//F
			}
		} else {
			PreviousButtonState = PreviousButtonState & ~(1<<5);
		}
	if(gpio_ispressed(KBDG)){
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

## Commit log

2019-10-28 Add Firmware
    [Saintcon2019 Debug (1).cfg, Saintcon2019 Debug.cfg, Saintcon2019.elf.cfg]
2019-10-28 add hardware files
    [26RGBLED.sch, LEDMatrixRGB16x16.sch, LEDMatrixRGB16x64.sch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]
2019-10-28 add pdf of schematic
2019-10-28 add pdf schematics

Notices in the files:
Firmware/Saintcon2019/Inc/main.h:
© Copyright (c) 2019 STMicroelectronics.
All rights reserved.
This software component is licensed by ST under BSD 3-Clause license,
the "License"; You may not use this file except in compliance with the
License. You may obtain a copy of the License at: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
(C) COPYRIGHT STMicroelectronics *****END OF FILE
